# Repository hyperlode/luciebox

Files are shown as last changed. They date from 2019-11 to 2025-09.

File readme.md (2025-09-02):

# About
A busy box is the official word for a sensory exploratory platform for babies. 
This project was made as a birth day gift for Lucie Ameije 2019-04
Turns out, it's as interesting to adults as it is to babies. 
95% ignores abandos the box after five minutes. 5% gets hooked for days. 

Made by Uncle Sensory Overlode.
www.ameije.com

PCB and code:
https://github.com/hyperlode/luciebox

Manual:
https://docs.google.com/document/d/10EQDtFDWs3Xm5eaC9KIhdYMh6ftuR9I12zDFt4Ep7Ls/edit?usp=sharing

# Upload
- Open the arduino IDE
- Open the "luciebox" folder in the IDE
- Compile and upload should go smoothly.
- (alternatively Platformio for VS-code can be used)

# Versions
- F301: 2021-03-19: Version uploaded before sending boxes home
- F302: 2021-04-20 For the v3 startburst pcb. 
-F303: 2021-04-21: Small bugfixes, easier debug of selector dial in settings app . 
-F306: 2021-10-15: Improve user experience. Dream mode app better suited for toddlers.

# Manual
- A manual is in the "documentation folder"
- The most up to date manual is a google docs. Online at https://docs.google.com/document/d/1WturQFRmZjFw0ZYRagNDqMO8tlJvhG8SyK8Gmxv2Aj4/edit#

# Motto
- There are no bugs, only features.  Or: every bug is a feature.  (it doesn't matter if things work or not).

# Making off:
- pcbs ordered 20191112   jlc pcb (jlcpcb.com) 10 pieces for about 30cad.
- Invoice No：2818290A20191113144921
- Invoice Date：13/11/2019
- Batch No：W201911131447210

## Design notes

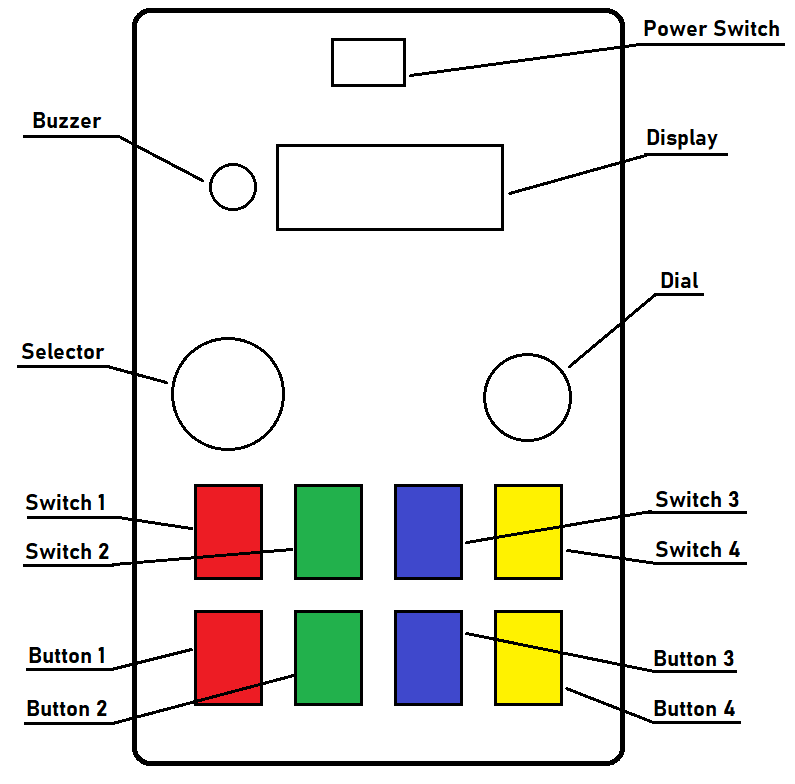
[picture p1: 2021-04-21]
documentation/Drawings_F306/Luciebox_lid_layout_annotated_font_bahnschrift.png

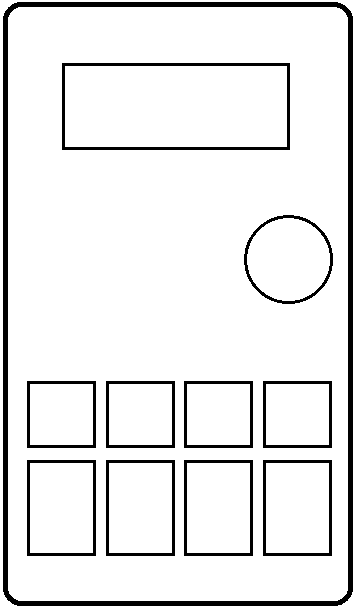
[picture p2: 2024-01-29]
documentation/Drawings_F308/Luciebox_lid_layout.png

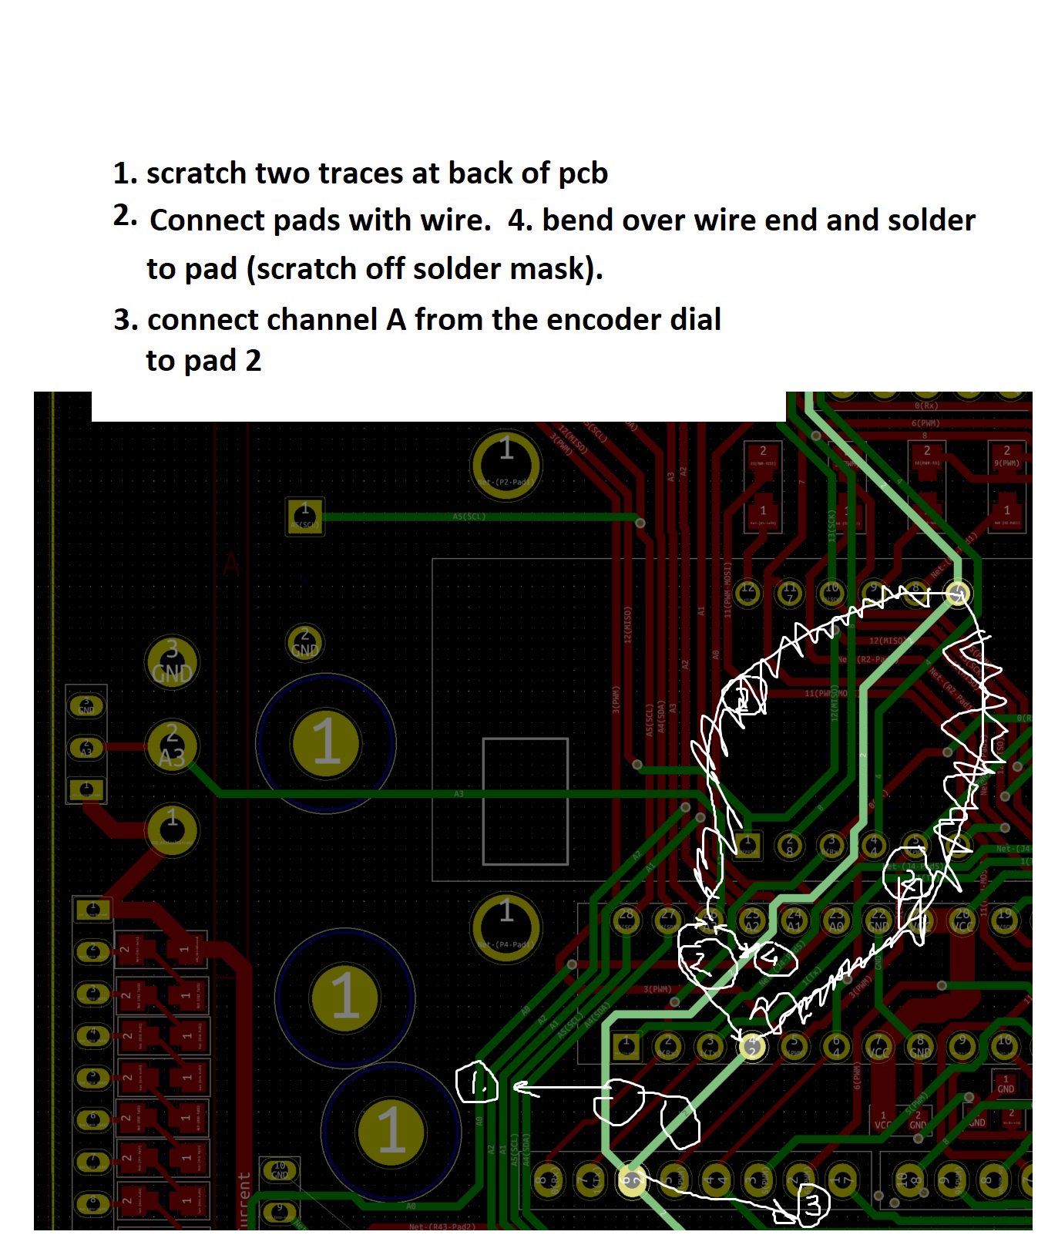
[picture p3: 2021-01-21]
pcb/v2 pcb with corona - change pin 2 to A3 for segment B.jpg

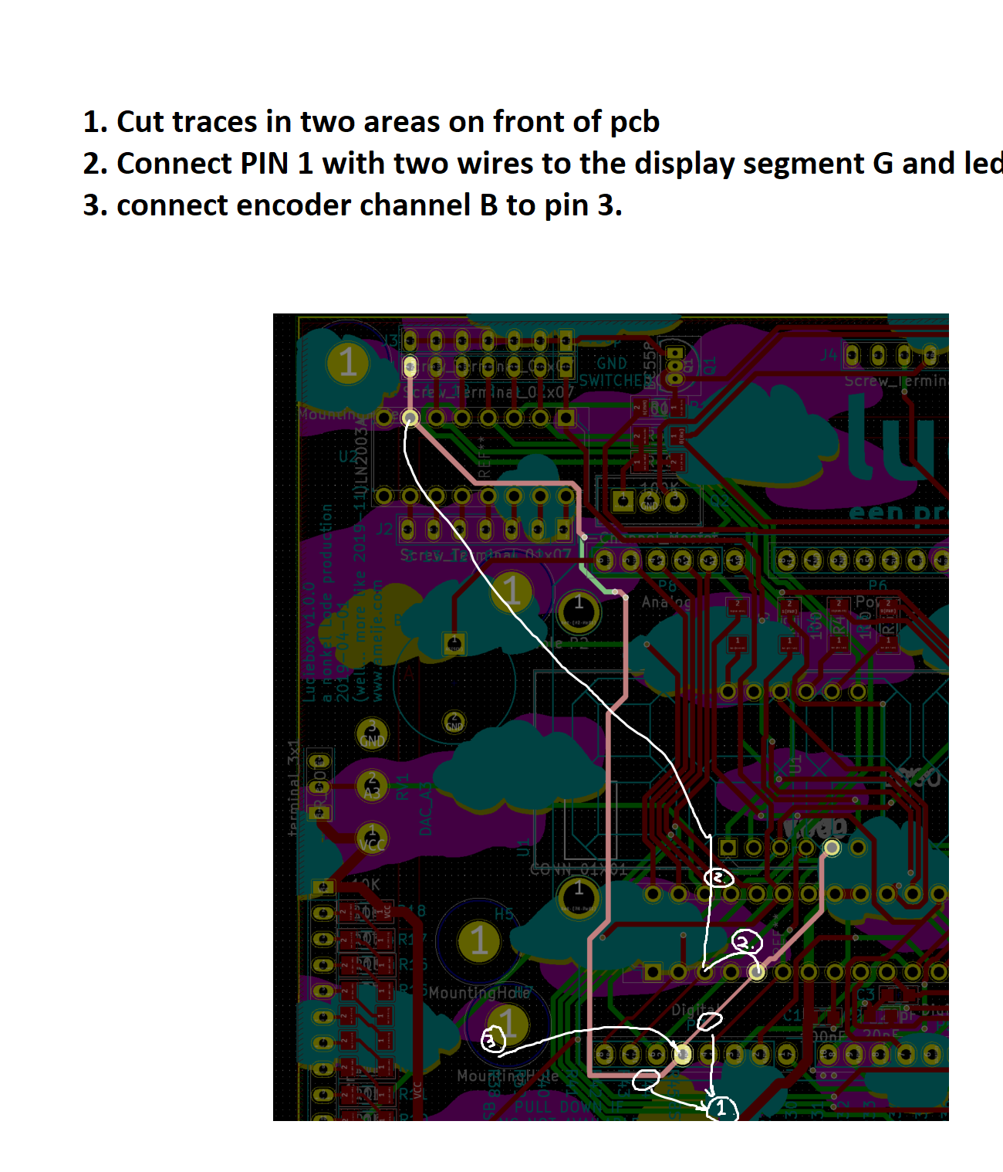
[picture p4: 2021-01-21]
pcb/v1 pcb with clouds - change pin 3 to 1 for segment G.png

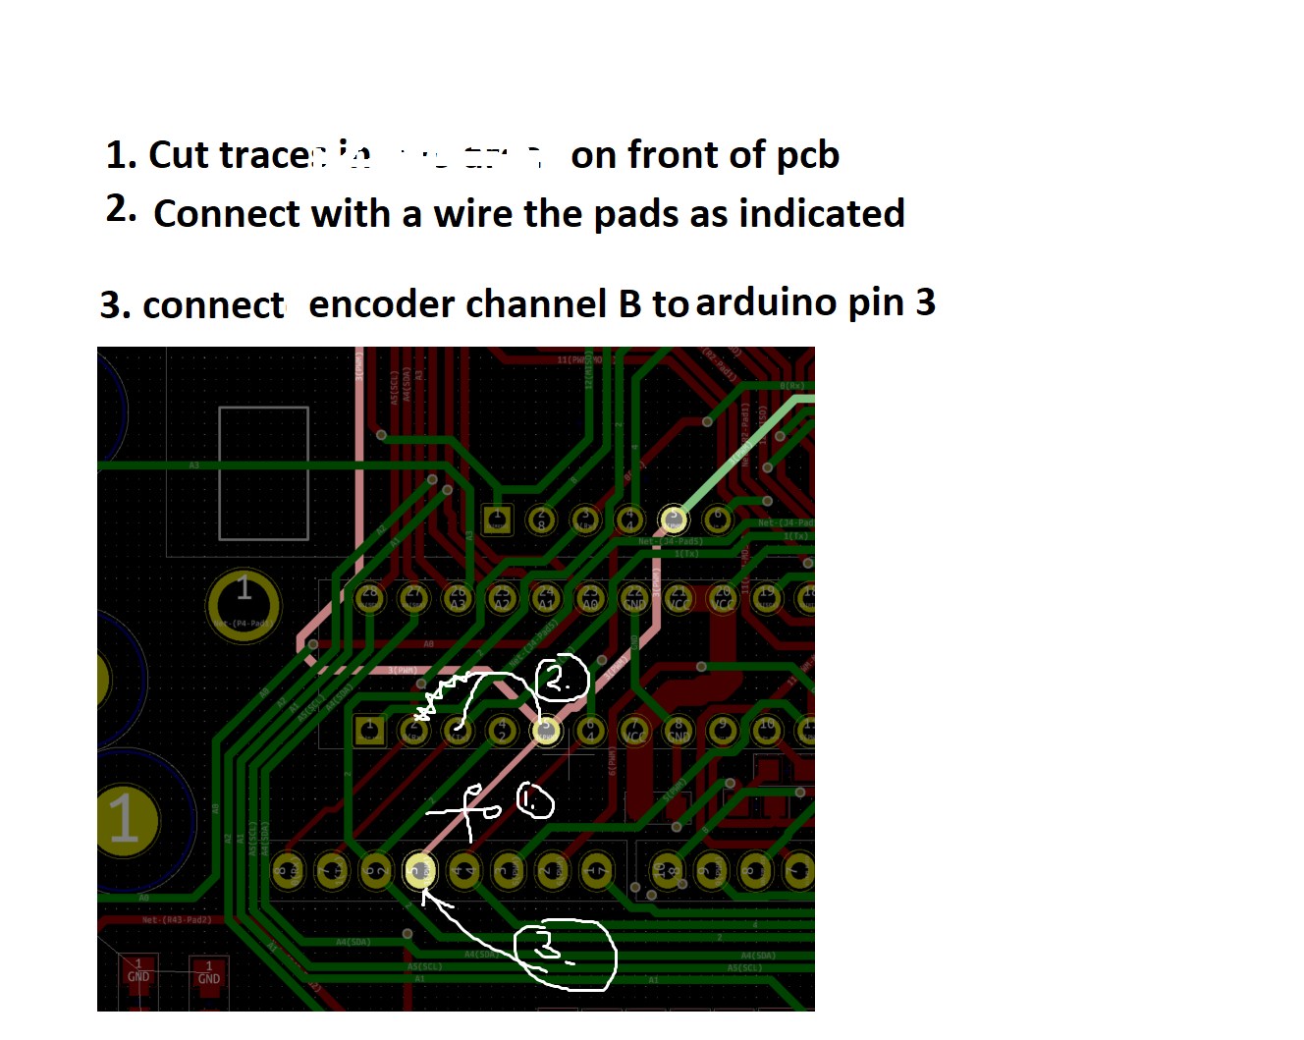
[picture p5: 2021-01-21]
pcb/v2 pcb with corona- change pin 3 to 1 for segment G.png

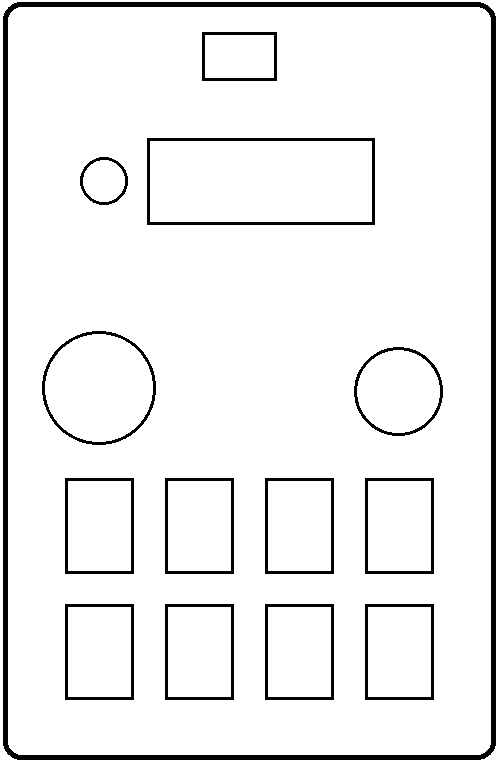
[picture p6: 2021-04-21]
documentation/Drawings_F306/Luciebox_lid_layout.png

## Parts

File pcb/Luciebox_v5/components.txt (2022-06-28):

https://www.aliexpress.com/item/32906026581.html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,scm-url:1007.13339.274681.0,pvid:77129f3c-91ed-44a8-8e5b-19a464453535,tpp_buckets:668%232846%238116%232002&pdp_ext_f=%7B%22sku_id%22%3A%2265853774655%22%2C%22sceneId%22%3A%223339%22%7D&pdp_npi=2%40dis%21CAD%21%2112.02%21%21%21%21%21%40210323a416546603388338875e28e2%2165853774655%21rec

https://www.aliexpress.com/item/32918157519.html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,scm-url:1007.40050.281175.0,pvid:30780251-6273-4900-846c-6cb24b13091a,tpp_buckets:668%232846%238116%232002&pdp_ext_f=%7B%22sku_id%22%3A%2210000001925503913%22%2C%22sceneId%22%3A%2230050%22%7D&pdp_npi=2%40dis%21CAD%21%210.59%21%21%21%21%21%40210323a016546671876902505e33f1%2110000001925503913%21rec

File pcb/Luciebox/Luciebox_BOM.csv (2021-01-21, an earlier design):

Reference | Value | Footprint | Datasheet
P6 | Power | Socket_Arduino_Uno:Socket_Strip_Arduino_1x08
P8 | Analog | Socket_Arduino_Uno:Socket_Strip_Arduino_1x06
P1 | CONN_01X01 | Socket_Arduino_Uno:Arduino_1pin
P2 | CONN_01X01 | Socket_Arduino_Uno:Arduino_1pin
P3 | CONN_01X01 | Socket_Arduino_Uno:Arduino_1pin
P4 | CONN_01X01 | Socket_Arduino_Uno:Arduino_1pin
P7 | Digital | Socket_Arduino_Uno:Socket_Strip_Arduino_1x08
P5 | Digital | Socket_Arduino_Uno:Socket_Strip_Arduino_1x10
U1 | CA56-12SRWA | Luciebox:CA56-12SRWA | http://www.kingbrightusa.com/images/catalog/SPEC/CA56-12SRWA.pdf
R3 | 100 | Luciebox:1206_0805 | ~
R4 | 100 | Luciebox:1206_0805 | ~
R5 | 100 | Luciebox:1206_0805 | ~
U2 | ULN2003A | Luciebox:DIP-16_W7.62mm | http://www.ti.com/lit/ds/symlink/uln2003a.pdf
R2 | 100 | Luciebox:1206_0805 | ~
R1 | 100 | Luciebox:1206_0805 | ~
Q1 | BC558 | Luciebox:TO-92-3 | http://www.fairchildsemi.com/ds/BC/BC557.pdf
J2 | Screw_Terminal_01x07 | Luciebox:Terminal_7x1_100mil | ~
J3 | Screw_Terminal_01x07 | Luciebox:Terminal_7x1_100mil | ~
U3 | ATmega328-PU | Luciebox:DIP-28_W7.62mm | http://ww1.microchip.com/downloads/en/DeviceDoc/ATmega328_P%20AVR%20MCU%20with%20picoPower%20Technology%20Data%20Sheet%2040001984A.pdf
R7 | 10K | Luciebox:1206_0805 | ~
R8 | 10K | Luciebox:1206_0805 | ~
R9 | 10K | Luciebox:1206_0805 | ~
R10 | 10K | Luciebox:1206_0805 | ~
R11 | 10K | Luciebox:1206_0805 | ~
R12 | 10K | Luciebox:1206_0805 | ~
R13 | 10K | Luciebox:1206_0805 | ~
R14 | 10K | Luciebox:1206_0805 | ~
R15 | 10K | Luciebox:1206_0805 | ~
R16 | 10K | Luciebox:1206_0805 | ~
R17 | 10K | Luciebox:1206_0805 | ~
R18 | 10K | Luciebox:1206_0805 | ~
T1 | terminal_13x1 | Luciebox:Terminal_13x1_100mil
RV1 | R_POT | Luciebox:BIG_POTENTIO | ~
BZ1 | Buzzer | Luciebox:buzzer | ~
Y1 | 16MHz | Luciebox:CRYSTAL | ~
R6 | 1M | Luciebox:1206_0805 | ~
C2 | 20pF | Luciebox:0805 | ~
C3 | 20pF | Luciebox:0805 | ~
C1 | 100nF | Luciebox:0805 | ~
R19 | 100 | Luciebox:1206_0805 | ~
J4 | Screw_Terminal_01x07 | Luciebox:Terminal_7x1_100mil | ~
Q2 | N-Channel_Mosfet | Luciebox:TO-220-3 | https://www.onsemi.com/pub/Collateral/FQP30N06L-D.pdf
R47 | 100K | Luciebox:1206_0805 | ~
R48 | 100K | Luciebox:1206_0805 | ~
J5 | Screw_Terminal_01x07 | Luciebox:Terminal_7x1_100mil | ~
T11 | terminal_3x1 | Luciebox:Terminal_3x1_100mil
H4 | MountingHole | MountingHole:MountingHole_4mm | ~
H1 | MountingHole | MountingHole:MountingHole_4mm | ~
H2 | MountingHole | MountingHole:MountingHole_4mm | ~
H3 | MountingHole | MountingHole:MountingHole_4mm | ~
H8 | MountingHole | MountingHole:MountingHole_4mm | ~
H7 | MountingHole | MountingHole:MountingHole_4mm | ~
H6 | MountingHole | MountingHole:MountingHole_4mm | ~
H5 | MountingHole | MountingHole:MountingHole_4mm | ~
U4 | 8X8PADS | Luciebox:64_PADS_100mil
R49 | 10K | Luciebox:1206_0805 | ~
J7 | USB_B_Mini | Luciebox:usb_mini_Molex-0548190519 | ~
D1 | D_Schottky | Luciebox:smd_throughhole_2_pins | ~
T8 | terminal_3x1 | Luciebox:Terminal_3x1_100mil
T10 | terminal_8x1 | Luciebox:Terminal_8x1_100mil
T9 | terminal_8x1 | Luciebox:Terminal_8x1_100mil
T13 | terminal_8x1 | Luciebox:Terminal_8x1_100mil
R27 | R_Small | Luciebox:1206_0805 | ~
R26 | R_Small | Luciebox:1206_0805 | ~
R25 | R_Small | Luciebox:1206_0805 | ~
R24 | R_Small | Luciebox:1206_0805 | ~
R23 | R_Small | Luciebox:1206_0805 | ~
R22 | R_Small | Luciebox:1206_0805 | ~
R21 | R_Small | Luciebox:1206_0805 | ~
R20 | R_Small | Luciebox:1206_0805 | ~
R28 | DAC_R-2R | Luciebox:SIP-10 | https://www.bourns.com/docs/Product-Datasheets/R2R.pdf
T4 | terminal_8x1 | Luciebox:Terminal_8x1_100mil
T3 | terminal_8x1 | Luciebox:Terminal_8x1_100mil
T2 | terminal_8x1 | Luciebox:Terminal_8x1_100mil
R36 | R_Small | Luciebox:1206_0805 | ~
R35 | R_Small | Luciebox:1206_0805 | ~
R34 | R_Small | Luciebox:1206_0805 | ~
R33 | R_Small | Luciebox:1206_0805 | ~
R32 | R_Small | Luciebox:1206_0805 | ~
R31 | R_Small | Luciebox:1206_0805 | ~
R30 | R_Small | Luciebox:1206_0805 | ~
R29 | R_Small | Luciebox:1206_0805 | ~
R37 | DAC_R-2R | Luciebox:SIP-10 | https://www.bourns.com/docs/Product-Datasheets/R2R.pdf
T7 | terminal_8x1 | Luciebox:Terminal_8x1_100mil
T6 | terminal_8x1 | Luciebox:Terminal_8x1_100mil
T5 | terminal_8x1 | Luciebox:Terminal_8x1_100mil
R44 | R_Small | Luciebox:1206_0805 | ~
R43 | R_Small | Luciebox:1206_0805 | ~
R46 | DAC_R-2R | Luciebox:SIP-10 | https://www.bourns.com/docs/Product-Datasheets/R2R.pdf
SW9 | Switch_tilt | Luciebox:Terminal_2x1_100mil
SW10 | Switch_tilt | Luciebox:Terminal_2x1_100mil
SW11 | Switch_tilt | Luciebox:Terminal_2x1_100mil
SW12 | Switch_tilt | Luciebox:Terminal_2x1_100mil
R45 | R_Small | Luciebox:1206_0805 | ~
R42 | R_Small | Luciebox:1206_0805 | ~

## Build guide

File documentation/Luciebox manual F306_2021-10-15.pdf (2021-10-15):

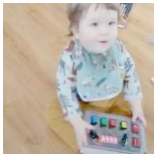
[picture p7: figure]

# Luciebox

# Owners manual

The Luciebox pretbak, made by Uncle Lode Ameije for Lucie. Project started 2019-04-02. Manual v20211005

# Introduction

I saw a toddler being mesmerized with the sounds and lights after pressing random buttons on one of my multiTimers. Right away I knew what I should give to my brother’s first soon-to-be-born child. What started as a weekend project now has a 40 something pages manual, and Lucie is two years old. The Luciebox is not going to appeal to many people, but I know, if I would have had this box as a kid, I would have worn it out together with my brother. We’d know every feature and bug better than the original creator. Sure, I can claim that there is educational value in this over the top retro device. But, let’s not forget the original mission of this project… It’s time to mesmerize! I realize now there is no such thing as finished projects, only abandoned projects. I’m welcoming all suggestions and contributions, write them down as comments in the appropriate section in this document. Looking at you Lucie! Regards from your high-expectations-uncle Lode.

# How to use this box

Don’t be put off by the lack of information on the box. It’s ok to be overwhelmed. Just know that there are 23 applications. An app is selected with the selector dial in combination with the Red Switch. Applications have different degrees of difficulty. Choose an application from the list and try to make it work. I suggest Guitar Hero for a fun introduction. Read the instructions for the specific app and have a go at it. At the start leave all switches in the OFF position to enable the default mode. Experiment away, you can’t do anything wrong.

Ta

# ble

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
rvie

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
rvie

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
al m

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
ol | 1
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
tilt

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
ole, r

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
al m

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
4 Idea for the Pascal sake drinking game | 24

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
rial | 2
7 Independent reaction game mode | 27

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
Timin

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
al c

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
ultiTim

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
Timin

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
al m

o

d

e

3

5
Valu

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
al r

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
al r

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
m la

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
7 Inactivity timer | 37 Randomness fun | 37 Test and Settings | 38 Settings Menu items | 38

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
Valu

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
Valu

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
O in

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
# Getting started

## Overview

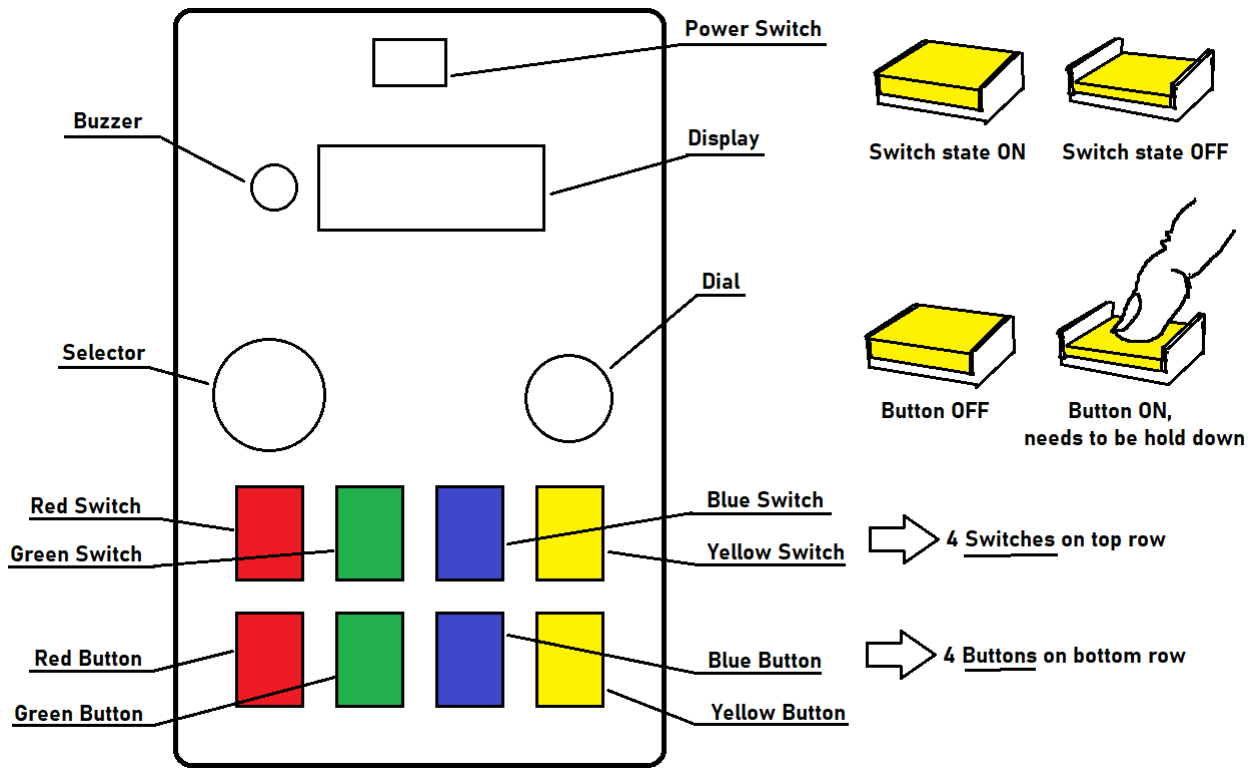
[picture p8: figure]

Name in this document | Official name | Description
Power Switch | On / Off switch | Switches on the box with the batteries. If powered by USB or the programming connecter, this will have no effect
Selector | Selector dial | Limitless 12 positions dial, on the left of the lid
Dial | Encoder dial | Limitless smooth dial on the right of the lid
Red Switch | Latching Button 0 | Red toggle button which can be set in the ON or OFF position.
Green Switch | Latching Button 1 | Green toggle button which can be set in the ON or OFF position.
Blue Switch | Latching Button 2 | Blue toggle button which can be set in the ON or OFF position.
Yellow Switch | Latching Button 3 | Yellow toggle button which can be set in the ON or OFF position.

Red Button | Momentary Button 0 | Red push button. When pushed and held, it’s ON, when released, it’s OFF.
Green Button | Momentary Button 1 | Green push button. When pushed and held, it’s ON, when released, it’s OFF.
Blue Button | Momentary Button 2 | Blue push button. When pushed and held, it’s ON, when released, it’s OFF.
Yellow Button | Momentary Button 3 | Yellow push button. When pushed and held, it’s ON, when released, it’s OFF.
Buzzer | Buzzer | A tiny speaker is inside the box. The volume can be set by putting some tape over the hole. The sound can be muted in the settings app
Display | 4 digit 7 segment LED display | Every digit has actually eight segments if we include the little dot, called the decimal point, on its right

# Applications

## Overview

If one of the buttons is held while rotating the selector knob, the splash screen stays visible.
Application | Selector Position | Red Switch Position | Splash screen | Comments | Diffi culty [1-5]
Test and Settings | 1 | 0 | wrench | Test all the buttons. Check and modify the Luciebox configuration. | 1
| 1 | 1
Stopwatch | 2 | 0 | stopwatch | All the goodies from a typical 80’s stopwatch. Has two independent timers. | 2
MultiTimer | | 1 | | A game clock for up to 4 players. Can also be used as a chess clock or as a kitchen timer. | 2
School | 3 | 0 | koala / Adhemar | Learn how to count, learn the alphabet | 3
Pomodoro Timer | 3 | 1 | | The Pomodoro technique helps procrastinators to get things done | 3

Random world | 4 | 0 | dice | Roll the dice, flip a coin, play bingo, draw random playing cards or let psychic Lucie answer all your questions. | 2
Score tracker | 4 | 1 | | Keeps a tally of the score of up to four players. | 2
Simon Says Game | 5 | 0 | face | Try to repeat light patterns of ever increasing length. Has multiplayer modes. | 3
Quizmaster, reaction game | 5 | 1 | | Press your button as fast as possible when the lights go on. Up to four players. | 3
Whack a mole | 6 | 0 | gun | Hit the button as quick as possible if the light goes on. If you play with sounds, it’s called “whack a bird” | 2
Guitar hero | 6 | 1 | | Bars are falling down quickly, hit the buttons at the right moment to catch them! | 3
Sketch pad | 7 | 0 | pencil | Scroll through and edit 95 pictures | 3
Memory game | 7 | 1 | | Reproduce what the display showed. | 3
Radio | 8 | 0 | movie reel | Play the main songs, your own compositions and the stored sequencer loops | 1
Movie player | 8 | 1 | | A full featured media player. Combine the built in or stored animations with one of the songs. It could as well have been named “my first meme”. | 3
Metronome | 9 | 0 | drumkit | Set the number of beats per minute. The flash mode produces noiseless ticks. | 2
Sequencer | 9 | 1 | | 4 bars of 8 notes of fun. Always starts up with an auto generated sequence. | 4
Music notes | 10 | 0 | note | Experiment with tones, lengths, scales and arpeggios. Features an auto mode | 1

Song Composer | 10 | 1 | | Create and save up to four songs. | 4
Noise Generator | 11 | 0 | radioactive | Measure your local radio activity. Or generate all kinds of noise. | 1
Hack Time | 11 | 1 | | Display and edit the Luciebox memory. Experiment as you like. | 5
Dream Time | 12 | 0 | manta ray | Baby action with simple button actions, patterns and sounds. | 1
| 12 | 1 | | | 1

# Toddler

## Radio

Simple music player. Each momentary button will play a song. The standard songs are featured, and your own programmed songs!

Input | Functionality | Comments
Green Switch | Song bank selector 1 | A combination of the bank selector assigns different songs to the momentary buttons
Blue Switch | Song bank selector 2 | A combination of the bank selector assigns different songs to the momentary buttons
Yellow Switch | Playback speed / Transpose | Dial will change the settings while a song is playing

### Songs

Green Switch | Blue Switch | Functionality
0 | 0 | Permanent memory songs bank 1 assigned to momentary buttons
1 | 0 | Permanent memory songs bank 2 assigned to momentary buttons
0 | 1 | Home made songs from the song composer assigned to momentary buttons
1 | 1 | Sequencer songs 1 to 4 assigned to momentary buttons

## Music notes

Plays single notes. Manually or automatically. Test different scales and modes.
Input | Functionality [OFF / ON] | Comments
Green Switch | Piano mode / Advanced mode
Blue Switch | Single note / Queue | In queue mode, all pressed notes will be added to the buffer. In single mode, the buffer will be erased before adding a note.
Yellow Switch | Manual mode / Auto arpeggio | Auto arpeggio will automatically play the next note after a timed interval
Dial | | in auto arpeggio: set interval, in manual mode: go up or down the scale

### Piano mode

Input | Functionality | Comments
Red Button | Mute | Will not make sound while changing notes. This allows you to jump notes silently when playing a song.
Green Button | Play active note | Play the last played note
Blue Button | Previous note | Previous note on the active scale
Yellow Button | Next note | Next note on the active scale

### Advanced mode

Input | Functionality | Comments
Red Button | Duration | Cycle between full, half, quarter, eight notes
Green Button | Progression | Cycle between up/down patterns: ● MANU: Manual (default, set direction yourself), ● UP: Going up the scale, ● DO: Going down the scale, ● UPDO: Saw pattern, going up and down, changing at a random interval ● RND: Random picking of a note on the scale ● CRAY: Crazy mode going randomly up and down at erratic intervals.
Blue Button | Scale | Cycle between different scales: ● AJOR: Major ● INOR: Minor ● PENT: Pentatonic ● BLUE: Blues Major ● CHRO: Chromatic

Yellow Button | Key | Cycle between all 12 tones in an octave to set the key of the selected scale. Press once to display the current key. Next button presses will change it.

## Metronome

A classic metronome with fun visual effect.
12 steps per cycle, up to three tickers.
Input | Functionality [OFF / ON] | Comments
Green Switch | Make ticker 2 step backwards
Blue Switch | Set speed in beats per minute (bpm) | One ‘beat’ is a full circle of 12 steps.
Yellow Switch | Manual mode / Ticking mode
Red Button | Reset the positions of all tickers | Set to the position of ticker 1
Green Button | Increase ticker 2 offset by one
Blue Button | Increase ticker 3 offset by one

### Metronome Manual mode

Yellow Button | Functionality | Comments
Single press | manual step
Not pressed | rotate dial to step
Hold and dial | Change tick sounds | note length: shorter (rotate clockwise) or longer (rotate counter clockwise) beeps. Shorter beeps lose their pitch, and are more like a metronome ‘puck’ sound.

### Metronome Ticking mode

Button | Functionality | Comments
Yellow Button | Flash screen toggle | Will toggle screen flashing at every beep. This improves metronome feedback in loud environments.
dial | | change bpm

## Dream Time

Mesmerize and go on a trippy hypno voyage where sound and graphics are ruled by randomness and chaos.

Input | Functionality [OFF / ON] | Comments
Green Switch | Play song | Toggle between Alphabet song and Happy Dryer song
Blue Switch | Unmute / Mute | Every segment has a sound assigned.It’s played when it appears or disappears. Sounds are a 32 values range off the total of 256 available sounds. The offset is settable.
Yellow Switch | Auto / Manual | Dial will change step in manual and set interval speed in auto mode
Red Button | Uncle Lode Indoctrination
Green Button | PRRRRR noise
Blue Button | Previous step
Yellow Button | Next step

# Child

## Easy timer

Displays the time since the box was switched on. There are no controls in this app.

## School

Learn how to count and learn the alphabet.
Learn how to be a bouncer by using the counting function to keep track of the number of guests in your bar.
Input | Functionality [OFF / ON] | Comments
Green Switch | Number mode / alphabet mode | display numbers or letters
Blue Switch | Numbers as Decimal / Hexadecimal | Only effective in number mode
Yellow Switch | Manual / Auto count | Auto mode ● Song is played when in alphabet mode ● Dial changes the speed Manual mode ● Dial changes value
Red Button | in auto mode: toggle count up / down
Green Button | set value zero

Blue Button | value down
Yellow Button | value up

## Score tracker

Keeps up to four different tallies. Can also be used for general counting. Cribbage, snooker, darts,...

Input | Functionality [OFF / ON] | Comments
Green Switch | Count up / Count down
Blue Switch | Apply score change to single tally / to all tallys
Yellow Switch | Modify mode / View mode | In view mode, every tally can be checked without modifying it
Red Button | Tally 1
Green Button | Tally 2
Blue Button | Tally 3
Yellow Button | Tally 4
dial | Hold momentary + dial → set delta | Will show the delta on the screen as long as the momentary button is not released.

## Movement detector (tilt fun)

Deprecated app. Will be made available again on popular request and when mercury switches are deemed environmentally friendly.
Move the box around to count.
Input | Functionality [OFF / ON] | Comments
Green Switch | go through all four positions for a full cycle / skip lateral movements for a full cycle. | don’t take lateral movement into account

Blue Switch

Yellow Switch

Dial

Move the box around, inside are motion detectors. When moved through a cycle correctly, the counter will increase.
Put the box on a swing, see how many times you can swing in a minute!

## Sketch pad

All drawings are stored in eeprom. Scroll through and edit the drawings.

### Modes

Input | Functionality [OFF / ON] | Remark
Green Switch | ON: Save menu | Save a drawing to the eeprom memory
Blue Switch | Display Image / Display Index | “Display index” displays the eeprom drawing address
Yellow Switch | View / Draw | In draw mode, drawings can be edited

### Display mode

Input | Functionality | Screen

Red Button

Green Button | Global display setting | cycle through: ● normal (default) ● negative ● all on ● all off ● STOP screen
Blue Button | Previous drawing
Yellow Button | Next drawing
Dial | Scroll through drawings

### Draw mode

Input | Functionality | Screen
Red Button | Toggle active segment
Green Button | Global display setting | cycle through: ● normal (default) ● negative ● all on ● all off ● STOP screen
Blue Button | Move cursor inside digit
Yellow Button | Move cursor to next digit
Dial | Move cursor

### Save To eeprom Mode

When scrolling through images, will NOT update the screen. The buffer stays the same. This way, you can scroll through the desired image (used index to see number) and save .
Input | Functionality | Comments
Red Button | Save screen | Will save the drawing to the active EEPROM address (visible with Green Switch)
Green Button | HOLD to have “shift function for momenary_2 and Yellow Button
Blue Button | previous drawing OR with SHIFT FUNCTION: delete drawing slot (and move all indexes, ) | Hold down Green Button for it to work
Yellow Button | next drawing OR with SHIFT FUNCTION: insert drawing slot and move all indexes from other drawings. Will overwrite the last drawing from eeprom. | Hold down Green Button for it to work
Dial | move through drawings.

### How to create animations

Step | Comment | Example
1 | Create and save a drawing with the STOP marker. (Draw mode → global display settings → stop screen) | drawing 27: STOP
2 | Go to the next drawing. Now make as many drawings as you want in the next slots. These are the frames of the movie. | drawing 28: UNCL drawing 29: LODE drawing 30: IS drawing 31: OLD COOL
3 | To indicate that the drawings are an animation, create and save another STOP drawing. | drawing 32: STOP
4 | Animations can be watched with the “Movie Player” app.

## Memory Game

Look at the picture, memorize it, press the start button. Try to reproduce it!
There are four modes available: Random segments, Numbers, Letters, Digital clock. This game is really fun to play as a collaborative challenge with a team!
Input | Functionality [OFF / ON] | Remark
Green Switch | Play mode option 1

Blue Switch | Play mode option 2
Yellow Switch | Menu / Play | In menu the generated pattern is already shown

### Menu

Play mode defines which image will be generated on the display
Play Mode | Green Switch | Blue Switch | Generate and display pattern
Random | OFF | OFF | Random segments (difficult mode)
Numbers | ON | OFF | Random digits (0000 to 9999)
Letters | OFF | ON | Random letters (AAAA to ZZZZ)
Clock | ON | ON | Random clock value (00.00 to 23.59)

### Play

Step | Comment
1 | Make sure Yellow Switch is set to OFF
2 | Memorize what’s displayed on the screen
3 | Switch Yellow Switch to ON
4 | Try to reproduce the screen as it was shown at the start. See the draw app on how to draw on the display
5 | When done with drawing, switch Yellow Switch to OFF
6 | If done correctly, a victory song will play. If you didn’t manage to reproduce the original drawing, the differences will be displayed.

## Random world

Show various random generated events.
Button | Functionality [OFF / ON] | Remark
Green Switch | Shift | Each of the momentary buttons gets another function if ON.
Blue Switch | animate? | “Rolling animation” if ON.

Yellow Switch | Manual / Auto draw | Auto draw: ● Set the draw interval time in seconds with the dial. ● Press a momentary button to start the auto draw Manual draw: ● Press a momentary button for each draw
Dial | | Manual draw mode: ● rotate to draw

### Random modes

Input | Shift? | Function
Red Button | No | Single Dice | Display shows eyes like a real dice
Red Button | Yes | Roll 4 dice at once | Each dice has its own digit. display: VVVV V = [1-6]
Green Button | No | Random Letter Shows random letter and its position in the alphabet | display: VV L VV = position of letter in alphabet L = representation of letter.
Green Button | Yes | Draw the next card from a shuffled deck. The card is discarded at next draw. When all cards from the deck are gone, a new deck is shuffled. Sound will sound when a new deck is taken and shuffled. | display: V S V = value S = Suit Values: 1 = ACE, 11 = JACK, 12 = QUEEN 13 = KING Suits: S = Spades C = Clubs H = Hearts D = Diamonds
Blue Button | No | Random number in manual mode : hold button (minimum 2 seconds, and keep holding) to set upper limit with Dial.
Blue Button | Yes | Random sequence (=tombola) Custom Value [0-xxx] Set maximum value xxx by holding the button and turning the Dial. xxx will be saved in eeprom.

| | in manual mode : hold button (minimum 2 seconds, and keep holding) to set upper limit with Dial. Will draw all numbers from the set (max 100 numbers) before starting a new set. Sound will sound when new sequence produced.
Yellow Button | No | Coin toss | display: HEAD (=head) or TAIL (=tails)
Yellow Button | Yes | Psychic experience. Ask a question, your grand-grand aunty Lucy will respond with yes or no. | display: YES or NO

## Stopwatch

Two independent classic chronometers.
At startup of the app, the second chronometer contains the total ON time since the Lucie box was switched on.
Input | Functionality [OFF / ON] | Remark
Green Switch | None | The rarest of beasts! A button without a function! Contact Uncle Lode if you have an idea.
Blue Switch | Display maximum precision or seconds precision
Yellow Switch | Stopwatch 1 / Stopwatch 2 | The two stopwatch controls are not influencing each other
Red Button | Hold to show split time
Green Button | Hold to save split time and show
Blue Button | Reset
Yellow Button | Toggle Start Pause

## Noise Generator

A geiger counter detects radioactive decay. Every time radiation is sensed, a beep is emitted. The more beeps you hear, the more contaminated the environment is!
Note: There is no real radioactivity meter installed in the Luciebox. It’s all fake fake fake. But your mother doesn’t need to know!
Input | Functionality [OFF / ON] | Remark
Green Switch | Geiger mode / Noise mode

Blue Switch | Animated / Counter
Dial | sensitivity

### Geiger Counter Mode

Input | Function | Comment
Red Button | None | Contact uncle Lode if you have a functionality idea
Green Button | None | Contact uncle Lode if you have a functionality idea
Blue Button | None | Contact uncle Lode if you have a functionality idea
Yellow Button | Temporary sharp increase of tick probability | When pressed, it looks like there is a lot more radiation. Practical joke idea: Hold the box close to a person and press the button…. it then appears like the person is contaminated. Hilarity ensues! Warning, do not use this prank near microwave ovens. People are already paranoid enough about them as it is.
Dial | Set tick probability

### Noise Mode

Offers the possibility to tune Geiger as a random note generator.

Input | Functionality | Comment
Yellow Switch | Prolonged beep | Every beep will sound until another beep takes over if ON.
Red Button | Set Lower frequency | Hold while rotating the dial. This is the lowest frequency that will be randomly chosen.
Green Button | Upper frequency | Hold while rotating the dial. This is the highest frequency that will be randomly chosen.
Blue Button | Tone length | Hold while rotating the dial. Tone length in milliseconds.
Yellow Button | Trigger manually | Hold while rotating the dial to trigger manually

## Whack a mole, reaction game

### Menu

Input | Functionality [OFF / ON] | Remark

Green Switch | Whack a mole / whack a bird | Can only be changed in Menu
Blue Switch | Normal mode / Endurance mode | Can only be changed in Menu
Yellow Switch | Menu / Play
Dial | Set level | Can only be changed in Menu

### Play Whack a mole

Every momentary button represents a mole that’s popping up. Your task is to hit it when it stick its head out! When the light goes on, you have to press the button as quick as possible to gain high scores.

Step | Function
1 | In the menu, the level (L x) and its high score are shown intermittently. Choose a level with the dial.
2 | Switch Yellow Switch to ON to start playing
3 | If a momentary button lights up (or a decimal point on the display), the corresponding button needs to be pressed.
4 | When the button is pressed, the light goes out. If it stays on, the button needs to be pressed again as that persistent mole needs more whacking!
5 | If a wrong button is pressed, or if time ran out, the game ends
6 | At game end, your mole whacking score will be displayed. If you have a new high score, a victory song will be played.
7 | After some seconds, a new game will start automatically. Go to step 3.
8 | Switch Yellow Switch to OFF to end the game and enter the menu at any time

### Play Whack a bird

Step | Function
1 | When the application is selected, four random notes from the chromatic scale are chosen. These notes stay the same for as long as the Whack-a-mole application is active.
2 | In the menu, the level (L x) and its high score are shown intermittently. Choose a level with the dial.
3 | Switch Yellow Switch to ON to start playing
4 | The four notes will be heard as a sequence. For each note, a button is assigned. It will light up when the sequence is playing.
5 | Now a note is played. Press the corresponding momentary button to whack that bird. (In

| level one, rookie mode, the corresponding button is lit up as a visual clue.)
6 | If a wrong button is pressed, or if time ran out, the game ends
7 | At game end, your bird whacking score will be displayed. If you have a new high score, a victory song will be played.
8 | After some seconds, a new game will start automatically. Go to step 4.
9 | Switch Yellow Switch to OFF to end the game and enter the menu at any time

### Normal mode

The time assigned is the maximum time between two whacks.
Level | Maximum reaction time[s] | Comments
1 | 30 | This seems long. But, run around the table or house for every mole you whack. How long can you last? What else can you do?
2 | 5
3 | 2.5
4 | 1
5 | ~0.5
6 | ~0.3 | Obviously uncle Lode maxed out on this one!

### Endurance mode

The time assigned is the total whacking time. Try to whack as many animals in that given time frame. Beware, one mistake and you have to start all over again…
level | Total whack time
1 | 2 minutes
2 | 1 minute
3 | 30 seconds
4 | 20 seconds
5 | 10 seconds
6 | 5 seconds

# Adolescent

## Simon Says Game

‘Simon says’ is a game where people try to repeat progressively longer sequences of button presses.

### Main menu

Button | Functionality [OFF / ON]
Green Switch | Simon / without Simon | Normally Simon decides the sequence. In games without Simon, every level, a player adds a step to the sequence.
Blue Switch | All players repeat/ one player repeats | In multiplayer: all players have to enter the sequencer (computer decides player sequence) or only one random chosen player has to repeat it.
Yellow Switch | Main menu / Play | When playing, set to OFF to enable menu and reset game
Dial | set number of players

### Game selection

Green Switch | Blue Switch | Functionality implemented | desired functionality (future)
0 | 0 | Play with Simon. Every turn, the computer makes the sequence one step longer. In multiplayer, all players in random order (the number is displayed on the screen) have to repeat the sequence
0 | 1 | Play with Simon. Every turn, the computer makes the sequence one step longer. In multiplayer, only one player is chosen to repeat the sequence. The chosen player id is displayed.
1 | 0 | Play without Simon. Players build the sequence. The first player in a new rounds sets the new last step in the sequence. Every player repeats the sequence.
1 | 1 | Play without Simon. Players build the sequence. Only one random player has to repeat the sequence. He decides what the next last step is. | Pascal sake drinking game: Player presses a sequence (length decided by computer?) computer chooses another player who has to repeat it.

TODO: Mode Pascal Sake Drinking Game
Use random switch AND custom build up options at the same time. For every round, a random player has to add a button press to the sequence.
→ a lot more fun when not
everybody has to do the new sequence.

### Play with Simon

Display | Function | Comments
Sxx | De computer player Simon shows a light sequence. | x = length of lights sequence [1-99]
nPxx | Player n has to repeat the light sequence Simon showed. Every button stands for a light. | Lights from left to right correspond with momentary buttons from left to right. n = player id [1 to 9]
nPxx/ END (blink) | All players are out. Last surviving player is n, with score: xx | Display blinks, during a repetition of the sequence one more time. After which a new game starts.

### Play without Simon

Display | Function | Comments
nPxx | Player n has to repeat the light sequence that’s already set. Every button stands for a light. At the end of the sequence, the player adds one more step by pressing one of the buttons of his choice. | Lights from left to right correspond with momentary buttons from left to right. n = player id [1 to 9]
nPxx/ END (blink) | All players are out. Last surviving player is n, with score: xx | Display blinks, during a repetition of the sequence one more time. After which a new game starts.

### Idea for the Pascal sake drinking game

Display | Function | Comments

nPxx | Player n inputs a certain sequence with the momentary buttons. The length of the sequence is defined by x | x = length of sequence [1-99] Use momentary buttons to input a sequence. n = player id [1 to 9]
nPpP | Player n has to repeat the light sequence Player p showed. This could be the same player (p could = n) | Use momentary buttons to input a sequence. n = player id [1 to 9]
pP / OUT (blink) | If player p makes a mistake, he’s out. Not sure if we continue then with a new sequence or if the next player has to input the correct sequence (this would ensure everybody keeps paying attention!) | Display blinks for 2 seconds, before continuing
nP / END (blink) | All players are out. Last surviving player is n | Display blinks for two seconds before restarting a new game

## Guitar Hero

Input | Functionality [OFF / ON] | Remark
Green Switch | Guitar hero / Hex hero
Blue Switch | Normal / Extra mode | Extra mode: Guitar hero: Adds random paused Hex Hero: Input the complement of what you see for all digits with a dot. e.a. 6. → 1001
Yellow Switch | Menu / Play
Dial | In Menu: Choose level | Higher level number = faster

### Play Guitar Hero

Step | Function
1 | In the menu, the level (L x) and its high score are shown intermittently. Choose a level with the dial.
2 | Switch Yellow Switch to ON to start playing
3 | Lines fall down from the top of the screen.
4 | Once lines have reached the bottom, you have to delete them by pressing the corresponding momentary button. Only delete lines that are AT the bottom.
5 | The game ends if a button is pressed at the wrong time, or lines are not deleted in time.
6 | At game end, your score will be displayed. If you have a new high score, a victory song

| will be played.
7 | After some seconds, a new game will start automatically. Go to step 4.
8 | Switch Yellow Switch to OFF to end the game and enter the menu at any time

Team tip: Play guitar hero together: Every player holds his finger on one or more buttons.

### Play Hex Hero

By the year 2036, having a reflexive knowledge of hexadecimal patterns will vastly improve your chances on the job market. Hex hero is an industry leading hex patterns trainer.
Step | Function
1 | In the menu, the level (L x) and its high score are shown intermittently. Choose a level with the dial.
2 | Switch Yellow Switch to ON to start playing
3 | Hexadecimal numbers characters scroll into the screen from the left
4 | Press the corresponding nibble (=half byte) pattern with the momentary buttons to delete the most right hex number. Try to keep a clear screen. See the “Hex character to button pattern conversion table” below. In extra mode (Blue Switch ON), digits with a dot will appear. These need to have the inverted nibble pattern inputted. That’s called “the complement”.
5 | The game ends if the hex numbers scroll out of the screen before they are deleted.
6 | At game end, your score will be displayed. If you have a new high score, a victory song will be played.
7 | After some seconds, a new game will start automatically. Go to step 4.
8 | Switch Yellow Switch to OFF to end the game and enter the menu at any time

Hex character to button pattern conversion table
Example: B shows up on the screen. B represents the value of 11 in decimal. In binary, B is 1011. Mimic this pattern with the momentary buttons by simultaneously pressing buttons 0, 2 and 3.
Charact er display ed | Decim al value | Convert ed to binary | Required button pattern to be pressed simultaneously | Extra: Compleme nt
| | | Red Button | Green Button | Blue Button | Yellow Button
1 | 1 | 0001 | | | | x | 1110
2 | 2 | 0010 | | | x | | 1101

3 | 3 | 0011 | | | x | x | 1100
4 | 4 | 0100 | | x | | | 1011
5 | 5 | 0101 | | x | | x | 1010
6 | 6 | 0110 | | x | x | | 1001
7 | 7 | 0111 | | x | x | x | 1000
8 | 8 | 1000 | x | | | | 0111
9 | 9 | 1001 | x | | | x | 0110
A | 10 | 1010 | x | | x | | 0101
B | 11 | 1011 | x | | x | x | 0100
C | 12 | 1100 | x | x | | | 0011
D | 13 | 1101 | x | x | | x | 0010
E | 14 | 1110 | x | x | x | | 0001
F | 15 | 1111 | x | x | x | x | 0000

## Quizmaster

Once the quizmaster has asked a question. Players can then press a button if they know the answer. It’s important to press your button quicker than your opponent. The Luciebox figures out who pressed first.
In independent mode, this app becomes an addictive multiplayer reaction game without a quizmaster asking questions
Input | Functionality [OFF / ON] | Remark
Green Switch | Normal / Long maximum wait time | ● normal: max 3 seconds ● long: max 20 seconds (which is very long!)
Blue Switch | Quizmode / Independent mode | in independent mode, this is a reaction game. At the random intervals, the light goes on. First player pressing gets a point. auto play some rounds.
Yellow Switch | Question asked | Quizmaster “just asked a question button” In independent mode: ON=play game

Dial

### Quizmaster Tutorial

Step | Comments
1 | Every player gets a momentary button assigned.

2 | Quizmaster asks question
3 | Quizmaster sets Yellow Switch to ON
4 | When the momentary buttons light up, the players can press their corresponding button. The first players pressing its button can answer. A player that presses its button before it’s lit up will have its score reset.
5 | Quizmaster can now turn dial to add or subtract a point to the player’s score
6 | Quizmaster sets Yellow Switch to OFF
7 | Go to step 2

### Independent reaction game mode

In independent mode, this becomes a very fun multiplayer reaction game.
Step | Comments
1 | Every player gets a momentary button assigned.
2 | Start the game by setting Yellow Switch to ON
3 | Wait until the button lights go on.
4 | The first player to press its corresponding button (when the light is on) gets a point. All players that press their buttons before it’s lit up will have their score reset.
5 | First player to reach ten points will hear a victory song.
6 | Reset the game with Yellow Switch

## Movie Player

Combine animations with songs to create full featured movies.

Functionality | Switch | Button | Dial
| 0 | 1 | 2 | 3 | 0 | 1 | 2 | 3
Sound Off (=Mute button) | 1 | | 1
Sound On | 1 | | 0
Autoplay movies | 1 | | | 0
Set playback speed | 1 | 0 | | 0 | | | | | Turn
Manual movie mode | 1 | | | 1
Scroll through frames | 1 | 0 | | 1 | | | | | Turn
Play song | 1 | 1 | | | 1 | 0 | 0 | 0

Toggle between continuous repeat of song and only play at start of movie | 1 | 1 | | 0 | 1 | 0 | 0
Previous Song | 1 | 1 | | 0 | 0 | 1 | 0
Next Song | 1 | 1 | | 0 | 0 | 0 | 1
Next Movie | 1 | 0 | | 1 | 0 | 0 | 0
Display Inverted | 1 | 0 | | 0 | 1 | 0 | 0
Previous frame | 1 | 0 | 1 | 0 | 0 | 1 | 0
Next frame | 1 | 0 | 1 | 0 | 0 | 0 | 1
Play movie forwards | 1 | 0 | 0 | 0 | 0 | 1 | 0
Play movie backwards | 1 | 0 | 0 | 0 | 0 | 0 | 1

### Animation selection

Cycle through all the animations with the “next movie” button.
Sequence: built in animations - home made animations
Note: See DRAW app on how to create a home made animation

### Song selection

Cycle through all the songs with the next and previous buttons. Sequence: 8 built in songs - 4 composed songs - 4 sequencer songs

## Pomodoro Performance Meter

The Pomodoro Timer is a well known tool to be able to concentrate for specific task such as studying, filing in taxes, doing homework, cleaning, …
https://en.wikipedia.org/wiki/Pomodoro_Technique

The official Pomodoro timer is a kitchen timer which has to be wind up manually. This very physical act prepares the mind for the task at hand. But, as we are automation aficionado's, an auto mode was added that automatically restarts the cycle after some break time.

### Menu

Input | Functionality [OFF / ON] | Remark
Green Switch | Enable Break time and auto restart
Blue Switch | Enable Visual Timer | Visual timer shows the amount of segments lit up as a function of the left over time. This is easier to grasp for young children.

Yellow Switch | Switch ON to start timer | Once started the settings will be saved to the permanent eeprom memory, to be retrieved later.
dial | if no Red Button or Green Button is pressed, will set the set POMODORO time | The official Pomodoro time is 25 minutes.
Red Button + dial | Hold and turn Dial to set POMODORO break duration. | The official Pomodoro break time is 5 minutes.
Green Button + dial | Hold and turn Dial to set random beep probability interval. | Must be bigger than zero to enable. Set the probability time at which interval a beep will be heard. This means that “on average” at this interval a beep will be heard. The randomization is to ensure that we are being checked up on at irregular intervals.

### Timing

Input | Functionality [OFF / ON] | Remark
Green Switch | enable/ disable break
Blue Switch | Display Visual timer.
Yellow Switch | If released, the timer will stop immediately.
Dial | Set volume and number of ticks. | The official Pomodoro guide states that the audible ticks remind us of the task at hand and help us to stay focussed.
Red Button | See number of NO’s
Green Button | See number of Yes’s
Blue Button | add 1 to NO
Yellow Button | add 1 to YES

Performance meter
When enabled, the Pomodoro timer will beep at random intervals during timing. The beeps keep you focussed. The idea is to press the Blue or the Yellow button at each beep. Blue for “I admit, I am procrastinating”, Yellow for “yes I am working”. A tally is kept of the key presses, so you can see your good vs bad ratio with the Red and Green Button. This is the computer equivalent of your mother checking up on you at unexpected moments!

Manual counter
The buttons can be pressed at any time. So they can also serve as a manual counter. e.a.how many sit-ups can you do in two minutes? Four kids playing, one person pressing buttons per sit-up. Or kids running back and forth from the wall to the timer for one minute, and pressing their button every time they pass… Yeah, I’m up to something

## MultiTimer

A chess clock for up to four players.

Input | Functionality [OFF / ON] | Comments
Yellow Switch | Menu / Timing | Switching to OFF will always reset the timer

### Menu

Input | Functionality [OFF / ON] | Comments
Green Switch | Fischer Timer | ● Set the time that will be added to every timer after its turn is finished. ● The Fischer timer prevents a player from not using all its time at once. It provides a fighting chance to come back into the game if a player is almost out of time. ● As copied from boardgamearena.com: When playing a timer’s time will never exceed its initial time.
Blue Switch | Random | ● A random timer will be chosen at game startup. ● When selected, all enabled timer button lights are blinking to indicate a random starter.
Yellow Switch | Menu / Start Timing
Dial | Set number of timers, Set time | ● Normal: Set the number of timers. ● If corresponding momentary buttons is pushed: Set a timer’s initial time
Momentar y_buttons | | ● If the light is on, the player is selected to join the game. ● If it is blinking, it is the starting player. ● To set the time of the player, press the button while rotating the dial.

### Timing mode

Input | Functionality [OFF / ON] | Comments
Green Switch | None
Blue Switch | Unpause / Pause
Yellow Switch | Menu / Start Timing

Momentary_but
tons
Next timer | ● If blinking slow: Timer is selected and ticking. Press the button to select the next timer ● If solid: Timer is not selected and not elapsed ● If fast blinking in pause mode: Selected but paused timer ● If fast blinking not in pause mode: checking remaining time while timer not selected ● If Off: Timer elapsed or not initialized

# Professional

## Sequencer

A sequencer indefinitely plays a programmed pattern.
The sequencer has a total length of 32 steps spread out over four bars of 8 steps. The bottom four horizontal segments on the display indicate the active bar, the top and middle horizontal segments indicate the active step on that bar. Each step can contain one note.
At startup of the app a random sequencer song will be generated for you. It will change at every restart of the app. If you like it, you’ll have to store it manually.
Input | Functionality [OFF / ON] | Comments
Green Switch | Normal mode / Eeprom Menu
Yellow Switch | Play mode / Program Mode | (Green Switch must be off)

### Program Mode

Input | Functionality [OFF / ON] | Comments
Blue Switch | Single bar / All bars | If All Bars is ON: When assigning a note to a step, it will be assigned to the step of all 4 bars. This is VERY HANDY. Tip: Use it to create a “base” pattern that is the same for all 4 bars before changing steps individually in all bars to make the song interesting.
Red Button | Play and show note at active sequencer step

Green Button | Set and listen to active note without assigning it | Hold button and rotate dial to choose the active note. Keep on holding the button while pressing the red button to assign the selected note to the current active sequencer step.
Blue Button | Previous step
Yellow Button | Next step
Dial | Move step

### Play Mode

Input | Functionality [OFF / ON] | Comments
Red Button | Hold to show assigned notes at active step as they are played | BONUS: hold and rotate dial to transpose the programmed sequence in auto play mode
Blue Button | Assign active note to active slot
Yellow Button | Next step | Hold down and rotate dial to quickly go forward
Dial | Set step speed

### Eeprom menu

Input | Functionality [OFF / ON] | Comments
Yellow Switch | LOAD / SAVE | Should a song be saved or loaded?
Green Button | Execute | Will save to eeprom or load from eeprom (depending on Yellow Switch)
Dial | Choose song number

## Song composer

Create your own songs and store them permanently in eeprom memory. Or load and edit a song. Each song has a maximum length of 100 notes.

Input | Functionality [OFF / ON] | Comments
Green Switch | Compose mode / Eeprom menu | Compose a song or save or load a song from Eeprom
Blue Switch | Note mode / Index mode | Display note value / Display note position in song

Dial | in autoplay: set speed, in manual mode: scroll through all notes.

### Compose mode

Input | Functionality [OFF / ON]
Red Button in Note mode | Play active note
Green Button in Note mode | Select note | Hold down and turn dial to select active note from scale
Press Red Button while holding Green Button in Note mode | Program note | It’s important to FIRST hold and keep holding Green Button, and then, to program, shortly press Red Button
Red Button in Index Mode | Delete current note in song | Delete slot. Move all notes so there is no gap
Green Button in Index Mode | Insert a note in the song | Insert slot behind current location. The song gets longer. If longer than the maximum allowed number of notes, the last note is erased.
Blue Button | Previous note in song
Yellow Button | Next note in song
Yellow Switch | Manual / Auto | If ON: the note sequence is played automatically
Dial | ● Auto play: set speed ● Manual play: scroll through song.. ● With Green Button in note mode: select note

### Eeprom menu

Input | Functionality [OFF / ON]
Yellow Switch | SAVE / LOAD | Should a song be saved or loaded
Red Button | Execute | Save to eeprom or load from eeprom (depending on Yellow Switch)
Dial | Choose program number

# Uncle Lode’s crazy level

## Hack Time

Observe the FLASH, RAM and EEPROM memories in their rawest state!
Scroll manually or automatically through all the bytes. Let them make noise or just display them on the screen. Show the index or the value of the address. Modify the RAM and EEPROM manually. Can you cheat your way into the game's highscores? If things go wrong, just switch the box on and off again.

Note: The active address is the most left digit on the display

### Modes

Input | Function [OFF / ON] | Remark
Green Switch | Address mode / normal mode
Blue Switch | Mute button | Sound OFF / ON. Every byte encodes for a note. On every change, this note is played. Be prepared for post-modernist masterpieces in auto-mode.
Yellow Switch | Auto scroll / Manual
Blue Button | HOLD and rotate Dial to scroll through memory in increments of 255 addresses
Yellow Button | HOLD and rotate Dial to scroll through memory in increments of 4 addresses | 4 is chosen, because the display can hold four bytes at its most.
Dial | | ● Auto scroll: Change speed ● Manual: Change address

### Address mode

Input | Functionality | Screen
Red Button | Set memory type | Cycle through: ● FLASH: displays F ● RAM: displays R ● EEPROM: displays E

### Normal mode

Input | Functionality | Screen
Green | | Cycle through:

Button with dial | | ● values displayed as ASCII-like character ● values displayed as bytes (7 segments + decimal point = 8 bits represented) ● most left digit on display: decimal ● most left digit on display: hexadecimal
Dial | while Green Button is pressed, write | Hold and rotate Dial to change the active memory byte value from 0 to 255. When the value changes in the memory, a confirmation beep will sound. Will work for eeprom and ram, but not for flash. Beware: when changing RAM, it might change back to another value right away as you’re tweaking the cpu live. Also, the device can suddenly behave strangely. Alternatively, the universe might collapse.

### Value representation

Decimal representation
Value from 0 to 255 (left character on the display)

Hexadecimal representation
Value from 0 to 0xFF (left segment on the display)

Binary representation
Display the raw byte value. See addendum for byte to display conversion.

Character representation
Display the byte value as a character. See addendum for byte to character conversion.

### Memory types

Memory Type | Address range Decimal | Address range Hexadeci mal | Length [bytes] | Edita ble | Retains value when powered off | Function
Flash | 0..32255 | 0..7DFF | 32255 | NO | YES | This memory contains the main program code. It is programmable to upload the firmware, but it cannot be changed from within the program.
Ram | 0..2047 | 0..7FF | 2048 | YES | NO | This fast memory is needed for the program to function
Eeprom | 0..1023 | 0..3FF | 1024 | YES | YES | This slow memory contains values the need to be preserved

### Luciebox eeprom layout

The flash and ram memory are organised beyond my control. But, the eeprom has 1024 bytes that can be programmed and will retain their value, even when the box is switched on and off again. It is strictly organised according to the schematic below.

Address range Decimal | Address range Hexadeci mal | Len gth [byt es] | function
0..7 | 0..7 | 8 | Settings | ● byte 0: Sound disabled ● byte 1..2: Power cycle counter (will only update if at least one of the momentary buttons is pressed after a switch on)
8.. 103 | 8..67 | 96 | Game high scores | each game has 6 levels. High score is 2 bytes (because I choose to believe in your abilities!) ● byte 0..11: Whack a mole ● byte 12..23: Whack a mole endurance mode ● byte 24..35: Whack a bird ● byte 36..47: Whack a bird endurance mode ● byte 48..59: Guitar Hero ● byte 60..71: Guitar Hero with stuttering ● byte 72..83: Hex Hero ● byte 84..95: Hex Hero with stuttering
104..109 | 68..6D | 6 | MultiTimer | ● byte 0: Number of enabled timers ● byte 1..4: Init timer per timer [seconds] ● byte 5: Fischer time [seconds]
110..112 | 6E..70 | 3 | Pomodoro | ● byte 0: Init time [seconds] ● byte 1: Pause time [seconds] ● byte 2: Random beep time [seconds]
113..240 | 71..F0 | 128 | Sequencer | 32 bytes per sequence * 4 sequences
241..640 | F1..280 | 400 | Composer songs | 100 bytes per song * 4 songs
641..1020 | 281..3FC | 380 | Sketch saved Pictures | 4 bytes per picture* 95 pictures
1021..1023 | 3FD..3FF | 3 | Free | Free space. All for you to store secret information, passwords, bitcoin passwords,...

# Extra features

## Luciebox ON time

This functionality has moved to the second chronometer of the chronometer app.

Nothing can be done in this app. The total time since the Luciebox was switched on is displayed. Switch the box OFF and back ON to reset.

## Inactivity timer

Every hour since the last key press, the happy dryer song will play. Unless the Pomodoro Application or Multitimer is activated.

## Randomness fun

Computers have a hard time with random value. They produce always the same sequence of values. By “seeding” a random generator, a starting point in that sequence is chosen.

For the Lucie box, the random seed is done with the internal timer at each app initialization. So, at startup, as long as no app has been changed, the same values will show up for generated random events.

In reality: As long as the selector dial was not rotated, the same random sequence will show up when restarting the Luciebox. That means rolling the dice will have result in the same value sequences, the sequencer generator will create the exact same song, guitar hero will show the same blocks,... .

I did this because it’s fun. For better randomness, change apps with the selector dial after switching the Luciebox on.

https://rheingoldheavy.com/better-arduino-random-values/

## Test and Settings

Button test and Luciebox settings.
Decimal points on display flicker erratically to indicate that the box is alive.
This is a simple buttons test app, that is very appealing to small kids as the behaviour is very predictable. All button presses have an instant effect!
Input | Function [OFF / ON] | Remark
Red Switch | Button test | display: -
Green Switch | Button test | display: -
Blue Switch | Button test | display: -
Yellow Switch | Button test | display: -
Red Button | Button test | display: 0
Green Button | Button test | display: 0

Blue Button | Button test | display: 0
Yellow Button | Button test | display: 0
Dial | Settings Menu | Twist back and forth 3 times to activate the settings menu. Once activated, every consecutive twist will activate the next menu item.

### Settings Menu items

Dial twists | Menu item | Functionality
3 | Enable sound | With Red Button, toggle the sound. This will be stored in the retentive memory.
4 | Battery level | Check the battery or usb voltage. Displayed in millivolts. The battery voltage goes down during the battery life until a level (about 2.7V) until a level where the box cannot operate any longer. Which is called “brown out”. Note: The measured voltage can vary from the battery voltage because of an inline Schottky diode (the voltage of a set of new batteries is too high for the microcontroller. The diode lowers the voltage to be always in range for 4 AA batteries. Add about 700mV to the displayed value for battery voltage.
5 | A0 | The value of the selector dial. The selector dial can be rotated in the A0 menu to check the values without changing apps. Expected values (estimations): 82/168/253/339/425/510/596/682/767/853/938/1023 (which makes for a difference of 85 per position). (If the selector wiper does not make contact, it shows a low value (~ 50). The analog input is then basically floating.)
6 | A1 | The value is an addition of pressed latching buttons. Red Switch:~64, Green Switch: ~128, Blue Switch: ~256, Yellow Switch: ~512
7 | A2 | The value is an addition of pressed momentary buttons. Red Button:~64, Green Button: ~128, Blue Button: ~256, Yellow Button: ~512
8 | A3 | not used for an analog input
9 | A4 | left floating
10 | Firmware version | Have this number ready when contacting the helpdesk.
11 | QTY | Display the amount of times the Luciebox was switched on and at least one momentary button was pressed.

12 | Reset | Press M0 and then M3 for game high scores and timer settings reset Press M0 and then M2 for total reset (includes drawings, composed songs, high scores, sequencer songs)

# Troubleshooting

Problem | Comment
App sometimes restarts. Some apps show a blank screen. Some apps are missing. | The selector dial wiper might have a gap. Bad bad selector switch. With a small screwdriver, bend the wiper downward to eliminate the gap with the outer conducting circle.
Luciebox does not start up, or only for some seconds | Undervoltage, batteries empty.
I have no clue what to do. | Read this manual.
I can’t read yet | Vraag hulp aan een ouder of voogd.
Ik ken geen Engels | Vraag maar aan Omi, zij heeft Engelse les gevolgd!

## Unimplemented apps

App | status | comments | Difficulty [1-5]
Slots machine | not started | Teach children that luck can replace work in order to make money | 3
Timed key press game | not started | Olympics game with keypresses. Press as fast as possible, stay in a steady rhythm or gradually go faster. | 4

# Addendums

## Value representation

### Binary representation

7 segment Digit, segment to byte position. light on = 1

0
5 | 1
6
4 | 2
3 | 7
| XXXX
| X
| XXXX
| X X
e.a. | X X = h57 = b01010111
Segment name | Byte bit index | Segment Position in Digit description
A | 0 | top
B | 1 | up right
C | 2 | bottom right
D | 3 | bottom
E | 4 | bottom left
F | 5 | top left
G | 6 | center
DP | 7 | decimal point

## Music note values

The length of the rests is

Byte value | ⅛ note | Byte valu e | ¼ note | Byte value | ½ note | Byte value | Full note | Byte value | Rest values (multiples of ⅛) (DISPLAY VALUE)
0 | A3_8 | 60 | A3_4 | 120 | A3_2 | 180 | A3_1 | 240 | REST_1_8 (-- 1)
1 | As3_8 | 61 | As3_4 | 121 | As3_2 | 181 | As3_1 | 241 | REST_2_8 (-- 2)
2 | B3_8 | 62 | B3_4 | 122 | B3_2 | 182 | B3_1 | 242 | REST_3_8 (-- 3)
3 | C4_8 | 63 | C4_4 | 123 | C4_2 | 183 | C4_1 | 243 | REST_4_8 (-- 4)
4 | Cs4_8 | 64 | Cs4_4 | 124 | Cs4_2 | 184 | Cs4_1 | 244 | REST_5_8 (-- 5)
5 | D4_8 | 65 | D4_4 | 125 | D4_2 | 185 | D4_1 | 245 | REST_6_8 (-- 6)
6 | Ds4_8 | 66 | Ds4_4 | 126 | Ds4_2 | 186 | Ds4_1 | 246 | REST_7_8 (-- 7)

7 | E4_8 | 67 | E4_4 | 127 | E4_2 | 187 | E4_1 | 247 | REST_8_8 (-- 8)
8 | F4_8 | 68 | F4_4 | 128 | F4_2 | 188 | F4_1 | 248 | REST_9_8 (-- 9)
9 | Fs4_8 | 69 | Fs4_4 | 129 | Fs4_2 | 189 | Fs4_1 | 249 | REST_10_8 (--A )
10 | G4_8 | 70 | G4_4 | 130 | G4_2 | 190 | G4_1 | 250 | REST_11_8 (-- B)
11 | Gs4_8 | 71 | Gs4_4 | 131 | Gs4_2 | 191 | Gs4_1 | 251 | REST_12_8 (-- C)
12 | A4_8 | 72 | A4_4 | 132 | A4_2 | 192 | A4_1 | 252 | REST_13_8 (-- D)
13 | As4_8 | 73 | As4_4 | 133 | As4_2 | 193 | As4_1 | 253 | REST_14_8 (-- E)
14 | B4_8 | 74 | B4_4 | 134 | B4_2 | 194 | B4_1 | 254 | REST_15_8 (-- F)
15 | C5_8 | 75 | C5_4 | 135 | C5_2 | 195 | C5_1 | 255 | RESERVED (eeprom song stop byte) (-- G)
16 | Cs5_8 | 76 | Cs5_4 | 136 | Cs5_2 | 196 | Cs5_1
17 | D5_8 | 77 | D5_4 | 137 | D5_2 | 197 | D5_1
18 | Ds5_8 | 78 | Ds5_4 | 138 | Ds5_2 | 198 | Ds5_1
19 | E5_8 | 79 | E5_4 | 139 | E5_2 | 199 | E5_1
20 | F5_8 | 80 | F5_4 | 140 | F5_2 | 200 | F5_1
21 | Fs5_8 | 81 | Fs5_4 | 141 | Fs5_2 | 201 | Fs5_1
22 | G5_8 | 82 | G5_4 | 142 | G5_2 | 202 | G5_1
23 | Gs5_8 | 83 | Gs5_4 | 143 | Gs5_2 | 203 | Gs5_1
24 | A5_8 | 84 | A5_4 | 144 | A5_2 | 204 | A5_1
25 | As5_8 | 85 | As5_4 | 145 | As5_2 | 205 | As5_1
26 | B5_8 | 86 | B5_4 | 146 | B5_2 | 206 | B5_1
27 | C6_8 | 87 | C6_4 | 147 | C6_2 | 207 | C6_1
28 | Cs6_8 | 88 | Cs6_4 | 148 | Cs6_2 | 208 | Cs6_1
29 | D6_8 | 89 | D6_4 | 149 | D6_2 | 209 | D6_1
30 | Ds6_8 | 90 | Ds6_4 | 150 | Ds6_2 | 210 | Ds6_1
31 | E6_8 | 91 | E6_4 | 151 | E6_2 | 211 | E6_1
32 | F6_8 | 92 | F6_4 | 152 | F6_2 | 212 | F6_1
33 | Fs6_8 | 93 | Fs6_4 | 153 | Fs6_2 | 213 | Fs6_1
34 | G6_8 | 94 | G6_4 | 154 | G6_2 | 214 | G6_1
35 | Gs6_8 | 95 | Gs6_4 | 155 | Gs6_2 | 215 | Gs6_1
36 | A6_8 | 96 | A6_4 | 156 | A6_2 | 216 | A6_1
37 | As6_8 | 97 | As6_4 | 157 | As6_2 | 217 | As6_1
38 | B6_8 | 98 | B6_4 | 158 | B6_2 | 218 | B6_1
39 | C7_8 | 99 | C7_4 | 159 | C7_2 | 219 | C7_1
40 | Cs7_8 | 100 | Cs7_4 | 160 | Cs7_2 | 220 | Cs7_1
41 | D7_8 | 101 | D7_4 | 161 | D7_2 | 221 | D7_1
42 | Ds7_8 | 102 | Ds7_4 | 162 | Ds7_2 | 222 | Ds7_1
43 | E7_8 | 103 | E7_4 | 163 | E7_2 | 223 | E7_1

44 | F7_8 | 104 | F7_4 | 164 | F7_2 | 224 | F7_1
45 | Fs7_8 | 105 | Fs7_4 | 165 | Fs7_2 | 225 | Fs7_1
46 | G7_8 | 106 | G7_4 | 166 | G7_2 | 226 | G7_1
47 | Gs7_8 | 107 | Gs7_4 | 167 | Gs7_2 | 227 | Gs7_1
48 | A7_8 | 108 | A7_4 | 168 | A7_2 | 228 | A7_1
49 | As7_8 | 109 | As7_4 | 169 | As7_2 | 229 | As7_1
50 | B7_8 | 110 | B7_4 | 170 | B7_2 | 230 | B7_1
51 | C8_8 | 111 | C8_4 | 171 | C8_2 | 231 | C8_1
52 | Cs8_8 | 112 | Cs8_4 | 172 | Cs8_2 | 232 | Cs8_1
53 | D8_8 | 113 | D8_4 | 173 | D8_2 | 233 | D8_1
54 | Ds8_8 | 114 | Ds8_4 | 174 | Ds8_2 | 234 | Ds8_1
55 | E8_8 | 115 | E8_4 | 175 | E8_2 | 235 | E8_1
56 | F8_8 | 116 | F8_4 | 176 | F8_2 | 236 | F8_1
57 | Fs8_8 | 117 | Fs8_4 | 177 | Fs8_2 | 237 | Fs8_1
58 | G8_8 | 118 | G8_4 | 178 | G8_2 | 238 | G8_1
59 | Gs8_8 | 119 | Gs8_4 | 179 | Gs8_2 | 239 | Gs8_1

## Display character Values

The letters and digits follow the ASCII standard. The other characters are custom Luciebox characters.
All values that are not indicated in the table will have their value represented as a blank (just like a space).
Character | Binary to 7 segment (left is A, right is DP) | ASCII value | Remark
‘ ‘ | | | Space is not implemented, provide SPACE_FAKE_ASCII. All unrecognized values will resolve into spaces.
0 | B00111111 | 48
1 | B00000110 | 49
2 | B01011011 | 50
3 | B01001111 | 51
4 | B01100110 | 52
5 | B01101101 | 53
6 | B01111101 | 54

7 | B00000111 | 55
8 | B01111111 | 56
9 | B01101111 | 57
ONLY_TOP_SEGMENT_FAKE_ASCII | B00000001 | 58 | Not an official ASCII character
ONLY_MIDDLE_SEGMENT_FAKE_ASCII | B01000000 | 59 | Not an official ASCII character
ONLY_BOTTOM_SEGMENT_FAKE_ASCII | B00001000 | 60 | Not an official ASCII character
ONLY_TOP_AND_BOTTOM_SEGMENT_F AKE_ASCII | B00001001 | 61 | Not an official ASCII character
SPACE_FAKE_ASCII | B00000000 | 62 | Not an official ASCII character
RANDOM | RANDOM | 63 | Not an official ASCII character. This is a SPECIAL CASE. It will randomly toggle its segments each time when assigned.
| B00000000 | 64
A | B01110111 | 65
B | B01111100 | 66
C | B00111001 | 67
D | B01011110 | 68
E | B01111001 | 69
F | B01110001 | 70
G | B00111101 | 71
H | B01110100 | 72
I | B00000110 | 73
J | B00001110 | 74
K | B01110101 | 75
L | B00111000 | 76
M | B01010101 | 77
N | B01010100 | 78

O | B01011100 | 79
P | B01110011 | 80
Q | B01100111 | 81
R | B01010000 | 82
S | B01101101 | 83
T | B01111000 | 84
U | B00011100 | 85
V | B00011110 | 86
W | B00011101 | 87
X | B00110110 | 88
Y | B01101110 | 89
Z | B00011011 | 90
37

# Todo and issues

F305

Please write down all idea’s, suggestions, and bugs.

## F304 changes

Update baby mode. Update songs and music notes handling

## F303 Changes

Settings app: ability to debug selector dial at A0

## F302 Changes

Issue | Status
metronome:button3 hold: set sound also when metronome ON. Change flashing toggle to another button. | No don’t do this. ok like it is. close issue
check if the MAX from random number (bingo) is indeed saved to eeprom once set… | Done

in random mode: dial function: not working. : If Blue Switch and Yellow Switch are off: Generate random values for last selected mode. (dial should be like next step)

Mode draw letters: would be fun to have the probability of drawn letter set to a certain language. English, Dutch,.... this way it can be used in word games. | memory for such a multi language endeavour for now. I could work if we put the probabilities per letter as byte in the eeprom. So, it can be changed in hack mode. Then, to pick a letter: make sum of all probabilities. Choose random number between zero and that total. In a for loop, add the probabilities again, if the chosen random number, is in an interval, that’s our number! aka: previous probability index when counting up. Of, just store the english letter frequencies in the ram. It’s not thaaaat
chronometer (or countdown timer?) Set animation, instead of numbers on screen, show hourglass on screen for countdown | we could use the screen fill animation.

done. Does it add value though?

done in flash Hmmm… not enough

different from dutch...

not done , not needed close

simon says multiplayer mode: do not let everybody do the sequence. Just one person. let random mode decide if it’s
just the next person, or a random person

OK done.

check pascal “No Simon” mode. | OK done
todo quizmaster app: dial sets score in quizmaster mode after question answered. → press all buttons to which a value is added or subtracted. hmm easier: dial changes value of player that pressed

multitimer: multiple timers, next player: not working!

enable random pause in hex hero | that’s silly. But, what we could do: complementary mode: whenever the decimal point is ON, the complement of the given number has to be provided

song composer: check if dial rotating with If momentary 1 or 2 is pressed, sets note.

song composer: hold down momentary0 and rotate dial will not assign notes while dialing

hack time: When the value changes in the memory, a confirmation beep will sound → NOPE

hacktime: representation of values as chars and binary looks like it’s not correct

ok done

ugh, no problem. works! did you read the manual on how to use it ? Closed.

done

reworked done

reworked done

solved.

done

inactivity timer

done beep every X minutes.(30?) → one hour

# Remarks

# Power solutions

- Batteries: 4xAA → this is more like 6.5V when the batteries are new, but, the Luciebox can handle (thanks to a Schottky diode)
- USB Mini connected to a powerbank or a phone charger

# Firmware update

Check the firmware version in the settings app. An update or your own software can be uploaded.

## Background

The arduino platform is used. The arduino bootloader is loaded in the Microcontroller. Imagine the Luciebox as an Arduino UNO board without its microcontroller. When the wires are connected like in the table, programming the Luciebox is like uploading a program to any Arduino Uno board. Experimenting is encouraged.

## Upload firmware procedure

1. Have an arduino UNO board ready. These boards are available for very cheap on aliexpress.
2. Take an arduino uno board, and connect the wires like indicated in the table below. There is no need to modify the arduino uno board. (For serial output to work in debug mode (e.a. Serial.println()), the atmega328 needs to be removed from the original UNO).
3. Open the arduino IDE and load the Luciebox program.
4. Upload the program to the connected “arduino UNO”.
5. Disconnect the RX/ TX pins if the atmega328 is not removed from the UNO board.
6. Done. (you can leave the VCC and GND connected to save on batteries).

## Luciebox to Arduino UNO interface

Pin Arduino programmer | Pin Luciebox | Remarks
VCC | VCC | 5V DC
GND | GND | Ground
TX | TX | Luciebox to Computer
RX | RX | Computer to Luciebox

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
ulle

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
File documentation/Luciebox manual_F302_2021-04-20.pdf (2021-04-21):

# Luciebox

# Owners manual

The Luciebox pretbak, made by Uncle Lode Ameije for Lucie. Project started 2019-04-02. Manual v20210406

# Introduction

I saw a toddler being mesmerized with the sounds and lights after pressing random buttons on one of my multiTimers. Right away I knew what I should give to my brother’s first soon-to-be-born child. What started as a weekend project now has a 40 something pages manual, and Lucie is two years old. The Luciebox is not going to appeal to many people, but I know, if I would have had this box as a kid, I would have worn it out together with my brother. We’d know every feature and bug better than the original creator. Sure, I can claim that there is educational value in this over the top retro device. But, let’s not forget the original mission of this project… It’s time to mesmerize! As I realize now there is no such thing as finished projects, only abandoned projects, I’m welcoming all suggestions and contributions. Looking at you Lucie! Regards from your high-expectations-uncle Lode.

# How to use this box

Don’t be put off by the lack of information on the box. It’s ok to be overwhelmed. Just know that there are 23 applications. An app is selected with the selector dial in combination with the Red Switch. Applications have different degrees of difficulty. Choose an application from the list and try to make it work. I suggest Guitar Hero for a fun introduction. Read the instructions for the specific app and have a go at it. At start leave all the switches in the OFF position to enable the default mode. Experiment away, you can’t do anything wrong.

# Table of contents

Introduction | 2
How to use this box | 2
Table of contents | 2
Getting started | 5
Overview | 5
Applications | 6
Overview | 6
Unimplemented apps | 8
Toddler | 8
Radio | 8
Songs | 8
Music notes | 9
Simple mode | 9
Advanced mode | 9
Metronome | 10
Metronome Manual mode | 10
Metronome Ticking mode | 11
Dreamtime | 11
Child | 11

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
tilt

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
ole, r

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
al m

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
2 Idea for the Pascal sake drinking game | 22

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
5 Independent reaction game mode | 26

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
Timin

g
M

ultiTim

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
Timin

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
al M

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
al m

o

d

e

3

3
Valu

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
al r

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
al r

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
m la

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
8 Inactivity timer | 38 Randomness | 38 Settings App | 38 Settings Menu items | 38

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
O in

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
# Getting started

## Overview


Name in this document | Official name | Description
Power Switch | On / Off switch | Switches on the box with the batteries. If powered by USB or the programming connecter, this will have no effect
Selector | Selector dial | Limitless 12 positions dial, on the left of the lid
Dial | Encoder dial | Limitless smooth dial on the right of the lid
Red Switch | Latching Button 0 | Red toggle button which can be set in the ON or OFF position.
Green Switch | Latching Button 1 | Green toggle button which can be set in the ON or OFF position.
Blue Switch | Latching Button 2 | Blue toggle button which can be set in the ON or OFF position.
Yellow Switch | Latching Button 3 | Yellow toggle button which can be set in the ON or OFF position.

Red Button | Momentary Button 0 | Red push button. When pushed and held, it’s ON, when released, it’s OFF.
Green Button | Momentary Button 1 | Green push button. When pushed and held, it’s ON, when released, it’s OFF.
Blue Button | Momentary Button 2 | Blue push button. When pushed and held, it’s ON, when released, it’s OFF.
Yellow Button | Momentary Button 3 | Yellow push button. When pushed and held, it’s ON, when released, it’s OFF.
Buzzer | Buzzer | A tiny speaker is inside the box. The volume can be set by putting some tape over the hole. The sound can be muted in the settings app
Display | 4 digit 7 segment LED display | Every digit has actually eight segments if we include the little dot, called the decimal point, on its right

# Applications

## Overview

If one of the buttons is held while rotating the selector knob, the splash screen stays visible.
App | Select or | Latch ing 0 | Splash screen | comments | Diffi culty [1-5]
Settings | 1 | 0 | | Test all the buttons. Check configuration. | 1
| 1 | 1
Total Time | 2 | 0 | | Display time from the moment the box is switched on | 2
Stopwatch | 2 | 1 | | All the goodies from a typical 80’s stopwatch. Has two independent timers. | 2
MultiTimer | 3 | 0 | | A game clock for up to 4 players. Can also be used as a chess clock or as a kitchen timer. | 3
Pomodoro timer | 3 | 1 | | The Pomodoro technique helps procrastinators to get things done | 3

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

Geiger | 11 | 0 | Measure your local radio activity. Or generate all kinds of noise.
Hack mode | 11 | 1 | Display and edit the Luciebox memory. Experiment as you like. | 5
Dream time | 12 | 0 | Baby soothing patterns and sounds. | 1
Letters and Numbers | 12 | 1 | Learn how to count, learn the alphabet | 2

## Unimplemented apps

App | status | comments | Difficulty [1-5]
Slots machine | not started | Teach children that luck can replace work in order to make money | 3
Timed key press game | not started | Olympics game with keypresses. Press as fast as possible, stay in a steady rhythm or gradually go faster. | 4

# Toddler

## Radio

Simple music player. Each momentary button will play a song. The standard songs are featured, and your own programmed songs!

Button | Functionality | Comments
Latching_1 | Song bank selector 1 | A combination of the bank selector assigns different songs to the momentary buttons
Latching_2 | Song bank selector 2 | A combination of the bank selector assigns different songs to the momentary buttons
Latching_3 | Playback speed / Transpose | Dial will change the settings while a song is playing

### Songs

Latching button index

2 | 3 | Functionality
0 | 0 | Permanent memory songs bank 1 assigned to momentary buttons
1 | 0 | Permanent memory songs bank 2 assigned to momentary buttons
0 | 1 | Home made songs from the song composer assigned to momentary buttons
1 | 1 | Sequencer songs 1 to 4 assigned to momentary buttons

## Music notes

Plays single notes. Manually or automatically. Test different scales and modes.
Button | Functionality [OFF / ON] | Comments
Latching_1 | Simple mode / Advanced mode | see different chapters for controls in each mode
Latching_2 | Single note / Queue | In queue mode, all pressed notes will be added to the buffer. In single mode, the buffer will be erased before adding a note.
Latching_3 | Manual mode / Auto arpeggio | Auto arpeggio will automatically play the next note after a timed interval
Dial | | in auto arpeggio: set interval, in manual mode: go up or down the scale

### Simple mode

Button | Functionality | Comments
Momentary_0 | Mute | Will not make sound while changing notes
Momentary_1 | Play active note | Just play the last played note
Momentary_2 | Previous note | Previous note on the active scale
Momentary_3 | Next note | Next note on the active scale

### Advanced mode

Button | Functionality | Comments
Momentary_0 | Duration | Press to cycle between full, half, quarter, eight notes
Momentary_1 | Progression | Press to cycle between

| | ● MANU: Manual (default, set direction yourself), ● UP: Going up the scale, ● DO: Going down the scale, ● UPDO: Saw pattern, going up and down, changing at a random interval ● RND: Random picking of a note on the scale ● CRAY: Crazy mode going randomly up and down at erratic intervals.
Momentary_2 | Scale | Cycle between different scales: ● AJOR: Major ● INOR: Minor ● PENT: Pentatonic ● BLUE: Blues Major ● CHRO: Chromatic
Momentary_3 | Key | Cycle between all 12 tones in an octave to set the key of the selected scale.

## Metronome

A classic metronome with fun visual effect.
12 steps per cycle, up to three tickers.
Button | Functionality [OFF / ON] | Comments
Latching_1 | Make ticker 2 step backwards
Latching_2 | Set speed in beats per minute (bpm) | One ‘beat’ is a full circle of 12 steps.
Latching_3 | Manual mode / Ticking mode
Momentary_0 | Reset the positions of all tickers | Set to the position of ticker 1
Momentary_1 | Increase ticker 2 offset by one
Momentary_2 | Increase ticker 3 offset by one

### Metronome Manual mode

Button Momentary_3 | Functionality | Comments
Single press | manual step
Not pressed | rotate dial to step
Hold and dial | Change tick sounds | note length: shorter (rotate clockwise) or longer (rotate counter clockwise) beeps. Shorter beeps lose their pitch, and are more like a metronome ‘puck’ sound.

### Metronome Ticking mode

Button | Functionality | Comments
Momentary_3 | Flash screen toggle | Will toggle screen flashing at every beep. This improves metronome feedback in loud environments.
dial | | change bpm

## Dreamtime

Mesmerize and go on a trippy hypno voyage where sound and graphics are ruled by randomness and chaos.
Button | Functionality [OFF / ON] | Comments
Latching_1 | Pitch offset | Offset is set with dial
Latching_2 | Unmute / Mute | Every segment has a sound assigned.It’s played when it appears or disappears. Sounds are a 32 values range off the total of 256 available sounds. The offset is settable.
Latching_3 | Auto / Manual | Dial will change step in manual and set interval speed in auto mode
Momentary_2 | Previous step | Only in manual mode
Momentary_3 | Next step | Only in manual mode

# Child

## Easy timer

Displays the time since the box was switched on. There are no controls in this app.

## Letters and Numbers

Learn how to count and learn the alphabet.
Learn how to be a bouncer by using the counting function to keep track of the number of guests in your bar.
Button | Functionality [OFF / ON] | Comments
Latching_1 | Number mode / alphabet mode | display numbers or letters
Latching_2 | Numbers as Decimal / Hexadecimal | Only effective in number mode
Latching_3 | Manual / Auto count | Auto mode

| | ● Song is played when in alphabet mode ● Dial changes the speed Manual mode ● Dial changes value
Momentary_0 | in auto mode: toggle count up / down
Momentary_1 | set value zero
Momentary_2 | value down
Momentary_3 | value up

## Score tracker

Keeps up to four different tallies. Can also be used for general counting. Cribbage, snooker, darts,...

Button | Functionality [OFF / ON] | Comments
Latching_1 | Count up / Count down
Latching_2 | Apply score change to single tally / to all tallys
Latching_3 | Modify mode / View mode | In view mode, every tally can be checked without modifying it
Momentary_0 | Tally 1
Momentary_1 | Tally 2
Momentary_2 | Tally 3
Momentary_3 | Tally 4
dial | Hold momentary + dial → set delta | Will show the delta on the screen as long as the momentary button is not released.

## Movement detector (tilt fun)

Deprecated app. Will be made available again on popular request and when mercury switches are deemed environmentally friendly.
Move the box around to count.
Button | Functionality [OFF / ON] | Comments
Latching_1 | go through all four positions for a full cycle / skip lateral movements for a full cycle. | don’t take lateral movement into account

Latching_2

Latching_3

Dial

Move the box around, inside are motion detectors. When moved through a cycle correctly, the counter will increase.
Put the box on a swing, see how many times you can swing in a minute!

## Sketch pad

All drawings are stored in eeprom. Scroll through and edit the drawings.

### Modes

Button | Functionality [OFF / ON] | Remark
Latching_1 | ON: Save menu | Save a drawing to the eeprom memory
Latching_2 | Display Image / Display Index | “Display index” displays the eeprom drawing address
Latching_3 | View / Draw | In draw mode, drawings can be edited

### Display mode

Control | Functionality | Screen

Momentary_0

Momentary_1 | Global display setting | cycle through: ● normal (default) ● negative ● all on ● all off ● STOP screen
Momentary_2 | Previous drawing
Momentary_3 | Next drawing
Dial | Scroll through drawings

### Draw mode

Control | Functionality | Screen
Momentary_0 | Toggle active segment
Momentary_1 | Global display setting | cycle through:

| | ● normal (default) ● negative ● all on ● all off ● STOP screen
Momentary_2 | Move cursor inside digit
Momentary_3 | Move cursor to next digit
Dial | Move cursor

### Save To eeprom Mode

When scrolling through images, will NOT update the screen. The buffer stays the same. This way, you can scroll through the desired image (used index to see number) and save .
Control | Functionality | Comments
Momentary_0 | Save screen | Will save the drawing to the active EEPROM address (visible with Latching_1)
Momentary_1 | HOLD to have “shift function for momenary_2 and momentary_3
Momentary_2 | previous drawing OR with SHIFT FUNCTION: delete drawing slot (and move all indexes, ) | Hold down Momentary_1 for it to work
Momentary_3 | next drawing OR with SHIFT FUNCTION: insert drawing slot and move all indexes from other drawings. Will overwrite the last drawing from eeprom. | Hold down Momentary_1 for it to work
Dial | move through drawings.

### How to create animations

Step | Comment | Example
1 | Create and save a drawing with the STOP marker. (Draw mode → global display settings → stop screen) | drawing 27: STOP
2 | use as many frames as you want the next drawings | drawing 28: UNCL drawing 29: LODE drawing 30: IS drawing 31: OLD COOL
3 | To indicate that the drawings are an animation, create and save another STOP drawing. | drawing 32: STOP
4 | Animations can be watched with the media player.

## Memory Game

Look at the picture, memorize it, press the start button. Try to reproduce it!
There are four modes available: Random segments, Numbers, Letters, Digital clock. This game is really fun to play as a collaborative challenge with a team!
Button | Functionality [OFF / ON] | Remark
Latching_1 | Play mode option 1
Latching_2 | Play mode option 2
Latching_3 | Menu / Play | In menu the generated pattern is already shown

### Menu

Play mode defines which image will be generated on the display
Play Mode | Latching_1 | Latching_2 | Generate and display pattern
Random | OFF | OFF | Random segments (difficult mode)
Numbers | ON | OFF | Random digits (0000 to 9999)
Letters | OFF | ON | Random letters (AAAA to ZZZZ)
Clock | ON | ON | Random clock value (00.00 to 23.59)

### Play

Step | Comment
1 | Make sure Latching_3 is set to OFF
2 | Memorize what’s displayed on the screen
3 | Switch Latching_3 to ON
4 | Try to reproduce the screen as it was shown at the start. See the draw app on how to draw on the display
5 | When done with drawing, switch Latching_3 to OFF
6 | If done correctly, a victory song will play. If you didn’t manage to reproduce the original drawing, the differences will be displayed.

## Random world

Show various random generated events.

Button | Functionality [OFF / ON] | Remark
Latching_1 | Shift | Each of the momentary buttons gets another function if ON.
Latching_2 | animate? | “Rolling animation” if ON.
Latching_3 | Manual / Auto draw | Auto draw: ● Set the draw interval time in seconds with the dial. ● Press a momentary button to start the auto draw Manual draw: ● Press a momentary button for each draw
Dial | | Manual draw mode: ● rotate to draw

### Random modes

Button | Shift ? | Function
Momentary_0 | No | Single Dice | Display shows eyes like a real dice
Momentary_0 | Yes | Roll 4 dice at once | Each dice has its own digit. display: VVVV V = [1-6]
Momentary_1 | No | Random Letter Shows random letter and its position in the alphabet | display: VV L VV = position of letter in alphabet L = representation of letter.
Momentary_1 | Yes | Draw the next card from a shuffled deck. The card is discarded at next draw. When all cards from the deck are gone, a new deck is shuffled. Sound will sound when a new deck is taken and shuffled. | display: V S V = value S = Suit Values: 1 = ACE, 11 = JACK, 12 = QUEEN 13 = KING Suits: S = Spades C = Clubs H = Hearts D = Diamonds
Momentary_2 | No | Random number in manual mode : hold button (minimum 2

| | seconds, and keep holding) to set upper limit with Dial.
Momentary_2 | Yes | Random sequence (=tombola) Custom Value [0-xxx] Set maximum value xxx by holding the button and turning the Dial. xxx will be saved in eeprom. in manual mode : hold button (minimum 2 seconds, and keep holding) to set upper limit with Dial. Will draw all numbers from the set (max 100 numbers) before starting a new set. Sound will sound when new sequence produced.
Momentary_3 | No | Coin toss | display: HEAD (=head) or TAIL (=tails)
Momentary_3 | Yes | Psychic experience. Ask a question, your grand-grand aunty Lucy will respond with yes or no. | display: YES or NO

## Stopwatch

Two independent classic chronometers.
Control | Functionality [OFF / ON] | Remark
Latching_1 | None | The rarest of beasts! A button without a function! Contact Uncle Lode if you have an idea.
Latching_2 | Display maximum precision or seconds precision
Latching_3 | Stopwatch 1 / Stopwatch 2 | The two stopwatch controls are not influencing each other
Momentary_0 | Hold to show split time
Momentary_1 | Hold to save split time and show
Momentary_2 | Reset
Momentary_3 | Toggle Start Pause

## Geiger

A geiger counter detects radioactive decay. Every time radiation is sensed, a beep is emitted. The more beeps you hear, the more contaminated the environment is!

Note: There is no real radioactivity meter installed in the Luciebox. It’s all fake fake fake.

Button | Functionality [OFF / ON] | Remark
Latching_1 | Geiger mode / Noise mode
Latching_2 | Animated / Counter
Dial | sensitivity

### Geiger Mode

Button | Function | Comment
Momentary_0 | None | Contact uncle Lode if you have a functionality idea
Momentary_1 | None | Contact uncle Lode if you have a functionality idea
Momentary_2 | None | Contact uncle Lode if you have a functionality idea
Momentary_3 | Temporary sharp increase of tick probability | When pressed, it looks like there is a lot more radiation. Practical joke idea: Hold the box close to a person and press the button…. it then appears like the person is contaminated. Hilarity ensues! Warning, do not use this prank near microwave ovens. People are already paranoid enough about them as it is.
Dial | Set tick probability

### Noise Mode

Offers the possibility to tune Geiger as a random note generator.

Button | Functionality | Comment
Latching_3 | Prolonged beep | Every beep will sound until another beep takes over if ON.
Momentary_0 | Lower frequency | Keep pressed while rotating Dial(CW=higher, CCW = lower)
Momentary_1 | Upper frequency | Keep pressed while rotating Dial (CW=higher, CCW = lower)
Momentary_2 | Note length | Keep pressed while rotating Dial(CW=longer, CCW = shorter)
Momentary_3 | trigger manually | Keep pressed while rotating dial for massive hits

## Whack a mole, reaction game

### Menu

Button | Functionality [OFF / ON] | Remark
Latching_1 | Whack a mole / whack a bird | Can only be changed in Menu
Latching_2 | Normal mode / Endurance mode | Can only be changed in Menu
Latching_3 | Menu / Play
Dial | Set level | Can only be changed in Menu

### Play Whack a mole

Every momentary button represents a mole that’s popping up. Your task is to hit it when it stick its head out! When the light goes on, you have to press the button as quick as possible to gain high scores.

Step | Function
1 | In the menu, the level (L x) and its high score are shown intermittently. Choose a level with the dial.
2 | Switch Latching_3 to ON to start playing
3 | If a momentary button lights up (or a decimal point on the display), the corresponding button needs to be pressed.
4 | When the button is pressed, the light goes out. If it stays on, the button needs to be pressed again as that persistent mole needs more whacking!
5 | If a wrong button is pressed, or if time ran out, the game ends
6 | At game end, your mole whacking score will be displayed. If you have a new high score, a victory song will be played.
7 | After some seconds, a new game will start automatically. Go to step 3.
8 | Switch Latching_3 to OFF to end the game and enter the menu at any time

### Play Whack a bird

Step | Function
1 | When the application is selected, four random notes from the chromatic scale are chosen. These notes stay the same for as long as the Whack-a-mole application is active.
2 | In the menu, the level (L x) and its high score are shown intermittently. Choose a level with the dial.

3 | Switch Latching_3 to ON to start playing
4 | The four notes will be heard as a sequence. For each note, a button is assigned. It will light up when the sequence is playing.
5 | Now a note is played. Press the corresponding momentary button to whack that bird. (In level one, rookie mode, the corresponding button is lit up as a visual clue.)
6 | If a wrong button is pressed, or if time ran out, the game ends
7 | At game end, your bird whacking score will be displayed. If you have a new high score, a victory song will be played.
8 | After some seconds, a new game will start automatically. Go to step 4.
9 | Switch Latching_3 to OFF to end the game and enter the menu at any time

### Normal mode

The time assigned is the maximum time between two whacks.
Level | Maximum reaction time[s] | Comments
1 | 30 | This seems long. But, run around the table or house for every mole you whack. How long can you last? What else can you do?
2 | 5
3 | 2.5
4 | 1
5 | ~0.5
6 | ~0.3 | Obviously uncle Lode maxed out on this one!

### Endurance mode

The time assigned is the total whacking time. Try to whack as many animals in that given time frame. Beware, one mistake and you have to start all over again…
level | Total whack time
1 | 2 minutes
2 | 1 minute
3 | 30 seconds
4 | 20 seconds
5 | 10 seconds
6 | 5 seconds

# Adolescent

## Simon

Simon says is a game where people try to repeat progressively longer sequences of button presses.

### Main menu

Button | Functionality [OFF / ON]
Latching_1 | Simon / without Simon | Normally Simon decides the sequence. In games without Simon, every level, a player adds a step to the sequence.
Latching_2 | All players repeat/ one player repeats | In multiplayer: all players have to enter the sequencer (computer decides player sequence) or only one random chosen player has to repeat it.
Latching_3 | Main menu / Play | When playing, set to OFF to enable menu and reset game
Dial | set number of players

### Game selection

Latchin g_1 | Latchin g_2 | Functionality implemented | desired functionality (future)
0 | 0 | Play with Simon. Every turn, the computer makes the sequence one step longer. In multiplayer, all players in random order (the number is displayed on the screen) have to repeat the sequence
0 | 1 | Play with Simon. Every turn, the computer makes the sequence one step longer. In multiplayer, only one player is chosen to repeat the sequence. The chosen player id is displayed.
1 | 0 | Play without Simon. Players build the sequence. The first player in a new rounds sets the new last step in the sequence. Every player repeats the sequence.
1 | 1 | Play without Simon. Players build the sequence. Only one random player has to repeat the sequence. He decides what the next last step is. | Pascal sake drinking game: Player presses a sequence (length decided by computer?) computer chooses another player who has to repeat it.

TODO: Mode Pascal Sake Drinking Game
Use random switch AND custom build up options at the same time. For every round, a random player has to add a button press to the sequence.
→ a lot more fun when not
everybody has to do the new sequence.

### Play with Simon

Display | Function | Comments
Sxx | De computer player Simon shows a light sequence. | x = length of lights sequence [1-99]
nPxx | Player n has to repeat the light sequence Simon showed. Every button stands for a light. | Lights from left to right correspond with momentary buttons from left to right. n = player id [1 to 9]
nPxx/ END (blink) | All players are out. Last surviving player is n, with score: xx | Display blinks, during a repetition of the sequence one more time. After which a new game starts.

### Play without Simon

Display | Function | Comments
nPxx | Player n has to repeat the light sequence that’s already set. Every button stands for a light. At the end of the sequence, the player adds one more step by pressing one of the buttons of his choice. | Lights from left to right correspond with momentary buttons from left to right. n = player id [1 to 9]
nPxx/ END (blink) | All players are out. Last surviving player is n, with score: xx | Display blinks, during a repetition of the sequence one more time. After which a new game starts.

### Idea for the Pascal sake drinking game

Display | Function | Comments

nPxx | Player n inputs a certain sequence with the momentary buttons. The length of the sequence is defined by x | x = length of sequence [1-99] Use momentary buttons to input a sequence. n = player id [1 to 9]
nPpP | Player n has to repeat the light sequence Player p showed. This could be the same player (p could = n) | Use momentary buttons to input a sequence. n = player id [1 to 9]
pP / OUT (blink) | If player p makes a mistake, he’s out. Not sure if we continue then with a new sequence or if the next player has to input the correct sequence (this would ensure everybody keeps paying attention!) | Display blinks for 2 seconds, before continuing
nP / END (blink) | All players are out. Last surviving player is n | Display blinks for two seconds before restarting a new game

## Guitar Hero

Button | Functionality [OFF / ON] | Remark
Latching_1 | Guitar hero / Hex hero
Latching_2 | Normal / Extra mode | Extra mode: Guitar hero: Adds random paused Hex Hero: Input the complement of what you see for all digits with a dot. e.a. 6. → 1001
Latching_3 | Menu / Play
Dial | In Menu: Choose level | Higher level number = faster

### Play Guitar Hero

Step | Function
1 | In the menu, the level (L x) and its high score are shown intermittently. Choose a level with the dial.
2 | Switch Latching_3 to ON to start playing
3 | Lines fall down from the top of the screen.
4 | Once lines have reached the bottom, you have to delete them by pressing the corresponding momentary button. Only delete lines that are AT the bottom.
5 | The game ends if a button is pressed at the wrong time, or lines are not deleted in time.
6 | At game end, your score will be displayed. If you have a new high score, a victory song

| will be played.
7 | After some seconds, a new game will start automatically. Go to step 4.
8 | Switch Latching_3 to OFF to end the game and enter the menu at any time

Team tip: Play guitar hero together: Every player holds his finger on one or more buttons.

### Play Hex Hero

By the year 2036, having a reflexive knowledge of hexadecimal patterns will vastly improve your chances on the job market. Hex hero is an industry leading hex patterns trainer.
Step | Function
1 | In the menu, the level (L x) and its high score are shown intermittently. Choose a level with the dial.
2 | Switch Latching_3 to ON to start playing
3 | Hexadecimal numbers characters scroll into the screen from the left
4 | Press the corresponding nibble (=half byte) pattern with the momentary buttons to delete the most right hex number. Try to keep a clear screen. See the “Hex character to button pattern conversion table” below. In extra mode (Latching_2 ON), digits with a dot will appear. These need to have the inverted nibble pattern inputted. That’s called “the complement”.
5 | The game ends if the hex numbers scroll out of the screen before they are deleted.
6 | At game end, your score will be displayed. If you have a new high score, a victory song will be played.
7 | After some seconds, a new game will start automatically. Go to step 4.
8 | Switch Latching_3 to OFF to end the game and enter the menu at any time

Hex character to button pattern conversion table
Example: B shows up on the screen. B represents the value of 11 in decimal. In binary, B is 1011. Mimic this pattern with the momentary buttons by simultaneously pressing buttons 0, 2 and 3.
Charact er display ed | Decim al value | Convert ed to binary | Required button pattern to be pressed simultaneously | Extra: Compleme nt
| | | Momentary _0 | Momentary _1 | Momentary _2 | Momentary _3
1 | 1 | 0001 | | | | x | 1110
2 | 2 | 0010 | | | x | | 1101

3 | 3 | 0011 | | | x | x | 1100
4 | 4 | 0100 | | x | | | 1011
5 | 5 | 0101 | | x | | x | 1010
6 | 6 | 0110 | | x | x | | 1001
7 | 7 | 0111 | | x | x | x | 1000
8 | 8 | 1000 | x | | | | 0111
9 | 9 | 1001 | x | | | x | 0110
A | 10 | 1010 | x | | x | | 0101
B | 11 | 1011 | x | | x | x | 0100
C | 12 | 1100 | x | x | | | 0011
D | 13 | 1101 | x | x | | x | 0010
E | 14 | 1110 | x | x | x | | 0001
F | 15 | 1111 | x | x | x | x | 0000

## Quiz master

One person is the quiz master. Up to four players are the participants. When the quiz master presses the button, a random timer is started. After that time is elapsed, the lights of the player buttons go on. Every player has a button. First one who presses can answer the question. If the player is correct, he keeps his button pressed while the quizmaster resets his button. That way, a point is added to his score. And off to the next round!

Button | Functionality [OFF / ON] | Remark
Latching_1 | Normal / Long maximum wait time | ● normal: max 3 seconds ● long: max 20 seconds (which is very long!)
Latching_2 | Quizmode / Independent mode | in independent mode, this is a reaction game. At the random intervals, the light goes on. First player pressing gets a point. auto play some rounds.
Latching_3 | Question asked | Quizmaster “just asked a question button” In independent mode: ON=play game

Dial

### Quizmaster

Step | Comments

1 | Every player gets a momentary button assigned.
2 | Quizmaster asks question
3 | Quizmaster sets Latching_3 to ON
4 | When the momentary buttons light up, the players can press their corresponding button. The first players pressing its button can answer. A player that presses its button before it’s lit up will have its score reset.
5 | Quizmaster can now turn dial to add or subtract a point to the player’s score
6 | Quizmaster sets Latching_3 to OFF
7 | Go to step 2

### Independent reaction game mode

In independent mode, this becomes a very fun multiplayer reaction game.
Step | Comments
1 | Every player gets a momentary button assigned.
2 | Start the game by setting Latching_3 to ON
3 | Wait until the button lights go on.
4 | The first player to press its corresponding button (when the light is on) gets a point. All players that press their buttons before it’s lit up will have their score reset.
5 | First player to reach ten points will hear a victory song.
6 | Reset the game with Latching_3

## Movie Player

Combine animations with songs to create full featured movies.

Functionality | Latching Button | Momentary Button | Dial
| 0 | 1 | 2 | 3 | 0 | 1 | 2 | 3
Sound Off (=Mute button) | 1 | | 1
Sound On | 1 | | 0
Autoplay movies | 1 | | | 0
Set playback speed | 1 | 0 | | 0 | | | | | Turn
Manual movie mode | 1 | | | 1

Scroll through frames | 1 | 0 | 1 | | | | | Turn
Play song | 1 | 1 | | 1 | 0 | 0 | 0
Toggle between continuous repeat of song and only play at start of movie | 1 | 1 | | 0 | 1 | 0 | 0
Previous Song | 1 | 1 | | 0 | 0 | 1 | 0
Next Song | 1 | 1 | | 0 | 0 | 0 | 1
Next Movie | 1 | 0 | | 1 | 0 | 0 | 0
Display Inverted | 1 | 0 | | 0 | 1 | 0 | 0
Previous frame | 1 | 0 | 1 | 0 | 0 | 1 | 0
Next frame | 1 | 0 | 1 | 0 | 0 | 0 | 1
Play movie forwards | 1 | 0 | 0 | 0 | 0 | 1 | 0
Play movie backwards | 1 | 0 | 0 | 0 | 0 | 0 | 1

### Animation selection

Cycle through all the animations with the “next movie” button.
Sequence: built in animations - home made animations
Note: See DRAW app on how to create a home made animation

### Song selection

Cycle through all the songs with the next and previous buttons. Sequence: 8 built in songs - 4 composed songs - 4 sequencer songs

## Pomodoro Performance Meter

The Pomodoro Timer is a well known tool to be able to concentrate for specific task such as studying, filing in taxes, doing homework, cleaning, …
https://en.wikipedia.org/wiki/Pomodoro_Technique

The implementation tries to imitate the original as closely as possible. It also has an experimental performance meter. When enabled, the timer will beep at random intervals. At these beeps, you have to press the “Yes, I was working button” or the “no, I was procrastination or dreaming” button. A tally is kept of the key presses, so you can see your good vs bad ratio. This is the computer equivalent of your mother checking up on you at unexpected moments!

The official Pomodoro timer is a kitchen timer which has to be wind up manually. This very physical act prepares the mind for the task at hand. But, as we are automation aficionado's, an auto mode was added that automatically restarts the cycle after a settable pause.

When enabled, during the Pomodoro timing, at random intervals, beeps will be heard. When a beep is
heard, a button needs to be pressed. Assign your values to the buttons. Good, bad, sleeping | The
buttons can be pressed at any time. This way, they can serve also as a manual counter. e.a.how many sit-ups can you do in two minutes? Four kids playing, one person pressing buttons per sit-up. Or kids running back and forth from the wall to the timer for one minute, and pressing their button every time they pass… Yeah, I’m up to something

### Menu

Control | Functionality [OFF / ON] | Remark
Latching_1 | Enable Break time and auto restart
Latching_2 | Enable Visual Timer | Visual timer shows the amount of segments lit up as a function of the left over time. This is easier to grasp for young children.
Latching_3 | Switch ON to start timer | Once started the settings will be saved to the permanent eeprom memory, to be retrieved later.
dial | if no momentary_0 or momentary_1 is pressed, will set the set POMODORO time | The official Pomodoro time is 25 minutes.
Momentary_0 + dial | Hold and turn Dial to set POMODORO break duration. | The official Pomodoro break time is 5 minutes.
Momentary_1 + dial | Hold and turn Dial to set random beep probability interval. | Must be bigger than zero to enable. Set the probability time at which interval a beep will be heard. This means that “on average” at this interval a beep will be heard. The randomization is to ensure that we are being checked up on at irregular intervals.

### Timing

Control | Functionality [OFF / ON] | Remark
Latching_1 | enable/ disable break
Latching_2 | Display Visual timer.
Latching_3 | If released, the timer will stop immediately.
Dial | Set volume and number of ticks. | The official Pomodoro guide states that the audible ticks remind us of the task at hand and help us to stay

| | focussed.
Momentary_0 | See number of NO’s
Momentary_1 | See number of Yes’s
Momentary_2 | add 1 to NO
Momentary_3 | add 1 to YES

## MultiTimer

A chess clock for up to four players.

Button | Functionality [OFF / ON] | Comments
Latching_3 | Menu / Timing | Switching to OFF will always reset the timer

### Menu

Button | Functionalit y [OFF / ON] | Comments
Latching_1 | Fischer Timer | ● Set the time that will be added to every timer after its turn is finished. ● The Fischer timer prevents a player from not using all its time at once. It provides a fighting chance to come back into the game if a player is almost out of time. ● As copied from boardgamearena.com: When playing a timer’s time will never exceed its initial time.
Latching_2 | Random | ● A random timer will be chosen at game startup. ● When selected, all enabled timer button lights are blinking to indicate a random starter.
Latching_3 | Menu / Start Timing
Dial | Set number of timers, Set time | ● Normal: Set the number of timers. ● If corresponding momentary buttons is pushed: Set a timer’s initial time
Momentar y_buttons | | ● If the light is on, the player is selected to join the game. ● If it is blinking, it is the starting player. ● To set the time of the player, press the button while rotating the dial.

### Timing mode

Button | Functionality [OFF / ON] | Comments

Latching_1 | None
Latching_2 | Pause / Unpause
Latching_3 | Menu / Start Timing
Momentary _buttons | Next timer | ● If blinking slow: Timer is selected and ticking. Press the button to select the next timer ● If solid: Timer is not selected and not elapsed ● If fast blinking in pause mode: Selected but paused timer ● If fast blinking not in pause mode: checking remaining time while timer not selected ● If Off: Timer elapsed or not initialized

# Professional

## Sequencer

A sequencer indefinitely plays a programmed pattern.
The sequencer has a total length of 32 steps spread out over four bars of 8 steps. The bottom four horizontal segments on the display indicate the active bar, the top and middle horizontal segments indicate the active step on that bar. Each step can contain one note.
At startup of the app a random sequencer song will be generated for you. It will change at every restart of the app. If you like it, you’ll have to store it manually.
Button | Functionality [OFF / ON] | Comments
Latching_1 | Normal mode / Eeprom Menu

### Normal Mode

Button | Functionality [OFF / ON] | Comments
Latching_2 | one bar / all bars | If ON: When assigning a note to a step, it will be assigned to the step of all 4 bars. VERY HANDY. Use this to create a “base” melody that is the same for all 4 bars.
Latching_3 | Manual / Autoplay | If no momentary buttons pressed, dial will set speed in autoplay mode
Momentary_0 Manual mode | Play and show assigned note at active step
Momentary_0 | Hold to show | BONUS: hold and rotate dial to transpose the

Autoplay | assigned notes at active step as they are played | programmed sequence in auto play mode
Momentary_1 | Set and listen to active note without assigning it | hold and rotate dial to choose the active note
Momentary_2 | Assign active note to active slot | rotate the dial to choose an active note (will not be shown on display)
Momentary_3 | Next step | Hold down and rotate dial to quickly go forward or backward

### Eeprom menu

Button | Functionality [OFF / ON] | Comments
Latching_3 | LOAD / SAVE | Should a song be saved or loaded?
Momentary_1 | Execute | Will save to eeprom or load from eeprom (depending on latching_3)
Dial | Choose song number

## Song composer

Create your own songs and store them permanently in eeprom memory. Or load and edit a song. Each song has a maximum length of 100 notes.

Button | Functionality [OFF / ON] | Comments
Latching_1 | Compose mode / Eeprom menu | Compose a song or save or load a song from Eeprom
Latching_2 | Note mode / Index mode | Display note value / Display note position in song
Dial | in autoplay: set speed, in manual mode: scroll through all notes.

### Compose mode

Button | Functionality [OFF / ON]
Momentary_0 in Note mode | Play active note
Momentary_1 in Note mode | Select note | Hold down and turn dial to select active note from scale

Press Momentary_0 while holding Momentary_1 in Note mode | Program note | It’s important to FIRST hold and keep holding Momentary_1, and then, to program, shortly press Momenary_0
Momentary_0 in Index Mode | Delete current note in song | Delete slot. Move all notes so there is no gap
Momentary_1 in Index Mode | Insert a note in the song | Insert slot behind current location. The song gets longer. If longer than the maximum allowed number of notes, the last note is erased.
Momentary_2 | Previous note in song
Momentary_3 | Next note in song
Latching_3 | Manual / Auto | If ON: the note sequence is played automatically
Dial | ● Auto play: set speed ● Manual play: scroll through song.. ● With momentary_1 in note mode: select note

### Eeprom menu

Button | Functionality [OFF / ON]
Latching_3 | SAVE / LOAD | Should a song be saved or loaded
Momentary_0 | Execute | Save to eeprom or load from eeprom (depending on latching_3)
Dial | Choose program number

# Uncle Lode’s crazy level

## Hacktime

See the FLASH, RAM and EEPROM memories in their rawest state!
Scroll manually or automatically through all the bytes. Let them make noise or just display them on the screen. Show the index or the value of the address. Modify the RAM and EEPROM manually. Can you cheat your way into the game highscores? If things go wrong, just switch the box on and off again.

note: Active address is the most left digit on the display

### Modes

Button | Function [OFF / ON] | Remark
Latching_1 | Address mode / normal mode
Latching_2 | Mute button | Sound OFF / ON. Every byte encodes for a note. On every change, this note is played. Be prepared for post-modernist masterpieces in auto-mode.
Latching_3 | Auto scroll / Manual
Momentary_2 | HOLD and rotate Dial to move memory location x255
Momentary_3 | HOLD and rotate Dial to move memory location x4 | 4 is chosen, because the display can hold four bytes at its most.
Dial | | ● Auto scroll: Change speed ● Manual: Change address

### Address mode

Control | Functionality | Screen
Momentary_0 | Set memory type | Cycle through: ● FLASH: displays F ● RAM: displays R ● EEPROM: displays E

### Normal mode

Control | Functionality | Screen
Moment ary_1 with dial | | Cycle through: ● values displayed as ASCII-like character ● values displayed as bytes (7 segments + decimal point = 8 bits represented) ● most left digit on display: decimal ● most left digit on display: hexadecimal
Dial | while Momentary_1 is pressed, write | Hold and rotate Dial to change the active memory byte value from 0 to 255. When the value changes in the memory, a confirmation beep will sound. Will work for eeprom and ram, but not for flash. Beware: when changing RAM, it might change back to another value right away as you’re tweaking the cpu live. Also, the device can suddenly behave strangely. Alternatively, the universe might collapse.

### Value representation

Decimal representation
Value from 0 to 255 (left character on the display)

Hexadecimal representation
Value from 0 to 0xFF (left segment on the display)

Binary representation
7 segment Digit, segment to byte position. light on = 1 0
5 | 1
6
4 | 2
3 | 7
| XXXX
| X
| XXXX
| X X
e.a. | X X = h57 = b01010111
Segment name | Byte bit index | Segment Position in Digit description
A | 0 | top
B | 1 | up right
C | 2 | bottom right
D | 3 | bottom
E | 4 | bottom left
F | 5 | top left
G | 6 | center
DP | 7 | decimal point

Character representation
All values that are not indicated in the table will have their value represented as a blank (just like a space)

Character

Binary to 7
segment (left

ASCII
value

Remark

| is A, right is DP)
‘ ‘ | | | Space is not implemented, provide SPACE_FAKE_ASCII. It will still work, because all unrecognized code will resolved into spaces.
0 | B00111111 | 48
1 | B00000110 | 49
2 | B01011011 | 50
3 | B01001111 | 51
4 | B01100110 | 52
5 | B01101101 | 53
6 | B01111101 | 54
7 | B00000111 | 55
8 | B01111111 | 56
9 | B01101111 | 57
ONLY_TOP_SEGMENT_FAKE_ASCII | B00000001 | 58 | Not an official ASCII character
ONLY_MIDDLE_SEGMENT_FAKE_ASCII | B01000000 | 59 | Not an official ASCII character
ONLY_BOTTOM_SEGMENT_FAKE_ASCII | B00001000 | 60 | Not an official ASCII character
ONLY_TOP_AND_BOTTOM_SEGMENT_FA KE_ASCII | B00001001 | 61 | Not an official ASCII character
SPACE_FAKE_ASCII | B00000000 | 62 | Not an official ASCII character
RANDOM | RANDOM | 63 | Not an official ASCII character, SPECIAL CASE, will randomly toggle one of the segment each time when assigned.
| B00000000 | 64
A | B01110111 | 65
B | B01111100 | 66
C | B00111001 | 67

D | B01011110 | 68
E | B01111001 | 69
F | B01110001 | 70
G | B00111101 | 71
H | B01110100 | 72
I | B00000110 | 73
J | B00001110 | 74
K | B01110101 | 75
L | B00111000 | 76
M | B01010101 | 77
N | B01010100 | 78
O | B01011100 | 79
P | B01110011 | 80
Q | B01100111 | 81
R | B01010000 | 82
S | B01101101 | 83
T | B01111000 | 84
U | B00011100 | 85
V | B00011110 | 86
W | B00011101 | 87
X | B00110110 | 88
Y | B01101110 | 89
Z | B00011011 | 90

### Memory types

Memory Type | Address range Decimal | Address range Hexadeci mal | Length [bytes] | Edita ble | Retains value when powered off | Function
Flash | 0..32255 | 0..7DFF | 32255 | NO | YES | This memory contains the main program code. It is

| | | | | | programmable to upload the firmware, but it cannot be changed from within the program.
Ram | 0..2047 | 0..7FF | 2048 | YES | NO | This fast memory is needed for the program to function
Eeprom | 0..1023 | 0..3FF | 1024 | YES | YES | This slow memory contains values the need to be preserved

### Luciebox eeprom layout

The flash and ram memory are organised beyond my control. But, the eeprom has 1024 bytes that can be programmed and will retain their value, even when the box is switched on and off again. It is strictly organised according to the schematic below.

Address range Decimal | Address range Hexadeci mal | Len gth [byt es] | function
0..7 | 0..7 | 8 | Settings | ● byte 0: Sound disabled ● byte 1..2: Power cycle counter (will only update if at least one of the momentary buttons is pressed after a switch on)
8.. 103 | 8..67 | 96 | Game high scores | each game has 6 levels. High score is 2 bytes (because I choose to believe in your abilities!) ● byte 0..11: Whack a mole ● byte 12..23: Whack a mole endurance mode ● byte 24..35: Whack a bird ● byte 36..47: Whack a bird endurance mode ● byte 48..59: Guitar Hero ● byte 60..71: Guitar Hero with stuttering ● byte 72..83: Hex Hero ● byte 84..95: Hex Hero with stuttering
104..109 | 68..6D | 6 | MultiTimer | ● byte 0: Number of enabled timers ● byte 1..4: Init timer per timer [seconds] ● byte 5: Fischer time [seconds]
110..112 | 6E..70 | 3 | Pomodoro | ● byte 0: Init time [seconds] ● byte 1: Pause time [seconds] ● byte 2: Random beep time [seconds]
113..240 | 71..F0 | 128 | Sequencer | 32 bytes per sequence * 4 sequences
241..640 | F1..280 | 400 | Composer songs | 100 bytes per song * 4 songs
641..1020 | 281..3FC | 380 | Sketch | 4 bytes per picture* 95 pictures

| | | saved Pictures
1021..1023 | 3FD..3FF | 3 | Free | Free space. All for you to store secret information, passwords, bitcoin passwords,...

# Practical

## Inactivity timer

Every hour since the last key press, the happy dryer song will play. Unless the Pomodoro Application or Multitimer is activated.

### Randomness

https://rheingoldheavy.com/better-arduino-random-values/
The random seed is done with the internal timer at each app initialization. So, at startup, as long as not app has been changed, the same values will show up for generated random event (rolling dice, sequencer generator, guitar hero sequence,...). It’s important that your sequence does not involve button presses, because, these cannot be timed. There is something fun about the idea of have the same randomness. For better randomness, make sure to change an app some time after startup of the box.

## Settings App

Button test and Luciebox settings.
Decimal points on display flicker erratically to indicate that the box is alive.
This is a simple buttons test app, that is very appealing to small kids as the behaviour is very predictable. All button presses have an instant effect!
Latching Button | Momentary Button | Dial | Functionality
0 | 1 | 2 | 3 | 0 | 1 | 2 | 3
1 | 1 | 1 | 1 | | | | | | Corresponding digit displays “-”
| | | | 1 | 1 | 1 | 1 | | Corresponding digit displays “0”
| | | | | | | | turn | Twist back and forth 3 times to activate the settings menu. Every consecutive twist will activate the next menu item.

### Settings Menu items

Dial twists | Menu item | Functionality
3 | Enable sound | With momentary 0, toggle the sound. This will be stored in the

| | retentive memory.
4 | A0 | The value of the selector dial. Stays at about 680. Cannot be changed.
5 | A1 | The value is an addition of pressed momentary buttons. Momentary_0:~64, momentary_1: ~128, momentary_2: ~256, momentary_3: ~512
6 | A2 | The value is an addition of pressed latching buttons. Latching_0:~64, Latching_1: ~128, Latching_2: ~256, Latching_3: ~512
7 | Firmware version | Have this number ready when contacting the helpdesk.
8 | QTY | Show the amount of times the Luciebox was switched on and at least one button was pressed.
9 | Reset | Press M0 and then M3 for game high scores reset Press M0 and then M2 for total reset (includes drawings, composed songs, high scores, sequencer songs)

# Troubleshooting

Problem | Comment
App sometimes restarts. Some apps show a blank screen. Some apps are missing. | The selector dial wiper might have a gap. Bad bad selector switch. With a small screwdriver, bend the wiper downward to eliminate the gap with the outer conducting circle.
Luciebox does not start up, or only for some seconds | Undervoltage, batteries empty.
I have no clue what to do. | Read this manual.
I can’t read yet | Vraag hulp aan een ouder of voogd.
Ik ken geen Engels | Vraag maar aan Omi, zij heeft Engelse les gevolgd!

# Todo and issues

## F302 Changes

Issue | Status

metronome:button3 hold: set sound also when metronome ON. Change flashing toggle to another button.

check if the MAX from random number (bingo) is indeed saved to eeprom once set…

in random mode: dial function: not working. : If latching_2 and latching_3 are off: Generate random values for last selected mode. (dial should be like next step)

Mode draw letters: would be fun to have the probability of drawn letter set to a certain language. English, Dutch,.... this way it can be used in word games. | memory for such a multi language endeavour for now. I could work if we put the probabilities per letter as byte in the eeprom. So, it can be changed in hack mode. Then, to pick a letter: make sum of all probabilities. Choose random number between zero and that total. In a for loop, add the probabilities again, if the chosen random number, is in an interval, that’s our number! aka: previous probability index when counting up. Of, just store the english letter frequencies in the ram. It’s not thaaaat
chronometer (or countdown timer?) Set animation, instead of numbers on screen, show hourglass on screen for countdown | we could use the screen fill animation.

No don’t do this. ok like it is. close issue

Done

done. Does it add value though?

done in flash Hmmm… not enough

different from dutch...

not done , not needed close

simon says multiplayer mode: do not let everybody do the sequence. Just one person. let random mode decide if it’s
just the next person, or a random person

OK done.

check pascal “No Simon” mode. | OK done
todo quizmaster app: dial sets score in quizmaster mode after question answered. → press all buttons to which a value is added or subtracted. hmm easier: dial changes value of player that pressed

multitimer: multiple timers, next player: not working!

enable random pause in hex hero | that’s silly. But, what we could do: complementary mode: whenever the decimal point is ON, the complement of the given number has to be provided

ok done

ugh, no problem. works! did you read the manual on how to use it ? Closed.

done

song composer: check if dial rotating with If momentary 1 reworked done or 2 is pressed, sets note.
song composer: hold down momentary0 and rotate dial will not assign notes while dialing

hack time: When the value changes in the memory, a confirmation beep will sound → NOPE

hacktime: representation of values as chars and binary looks like it’s not correct

inactivity timer

reworked done

solved.

done

done beep every X minutes.(30?) → one hour

# Remarks

# Power solutions

- Batteries: 4xAA → this is more like 6.5V when the batteries are new, but, the Luciebox can handle (thanks to a Schottky diode)
- USB Mini connected to a powerbank or a phone charger

# Firmware update

Check the firmware version in the settings app. An update or your own software can be uploaded.

## Background

The arduino platform is used. The arduino bootloader is loaded in the Microcontroller. Imagine the Luciebox as an Arduino UNO board without its microcontroller. When the wires are connected like in the table, programming the Luciebox is like uploading a program to any Arduino Uno board. Experimenting is encouraged.

## Upload firmware procedure

1. Have an arduino UNO board ready. These boards are available for very cheap on aliexpress.
2. Take an arduino uno board, and connect the wires like indicated in the table below. There is no need to modify the arduino uno board. (For serial output to work in debug mode (e.a. Serial.println()), the atmega328 needs to be removed from the original UNO).
3. Open the arduino IDE and load the Luciebox program.
4. Upload the program to the connected “arduino UNO”.
5. Disconnect the RX/ TX pins if the atmega328 is not removed from the UNO board.
6. Done. (you can leave the VCC and GND connected to save on batteries).

## Luciebox to Arduino UNO interface

Pin Arduino programmer | Pin Luciebox | Remarks
VCC | VCC | 5V DC
GND | GND | Ground
TX | TX | Luciebox to Computer
RX | RX | Computer to Luciebox
RESET | RESET | Pulled to GND during programming.

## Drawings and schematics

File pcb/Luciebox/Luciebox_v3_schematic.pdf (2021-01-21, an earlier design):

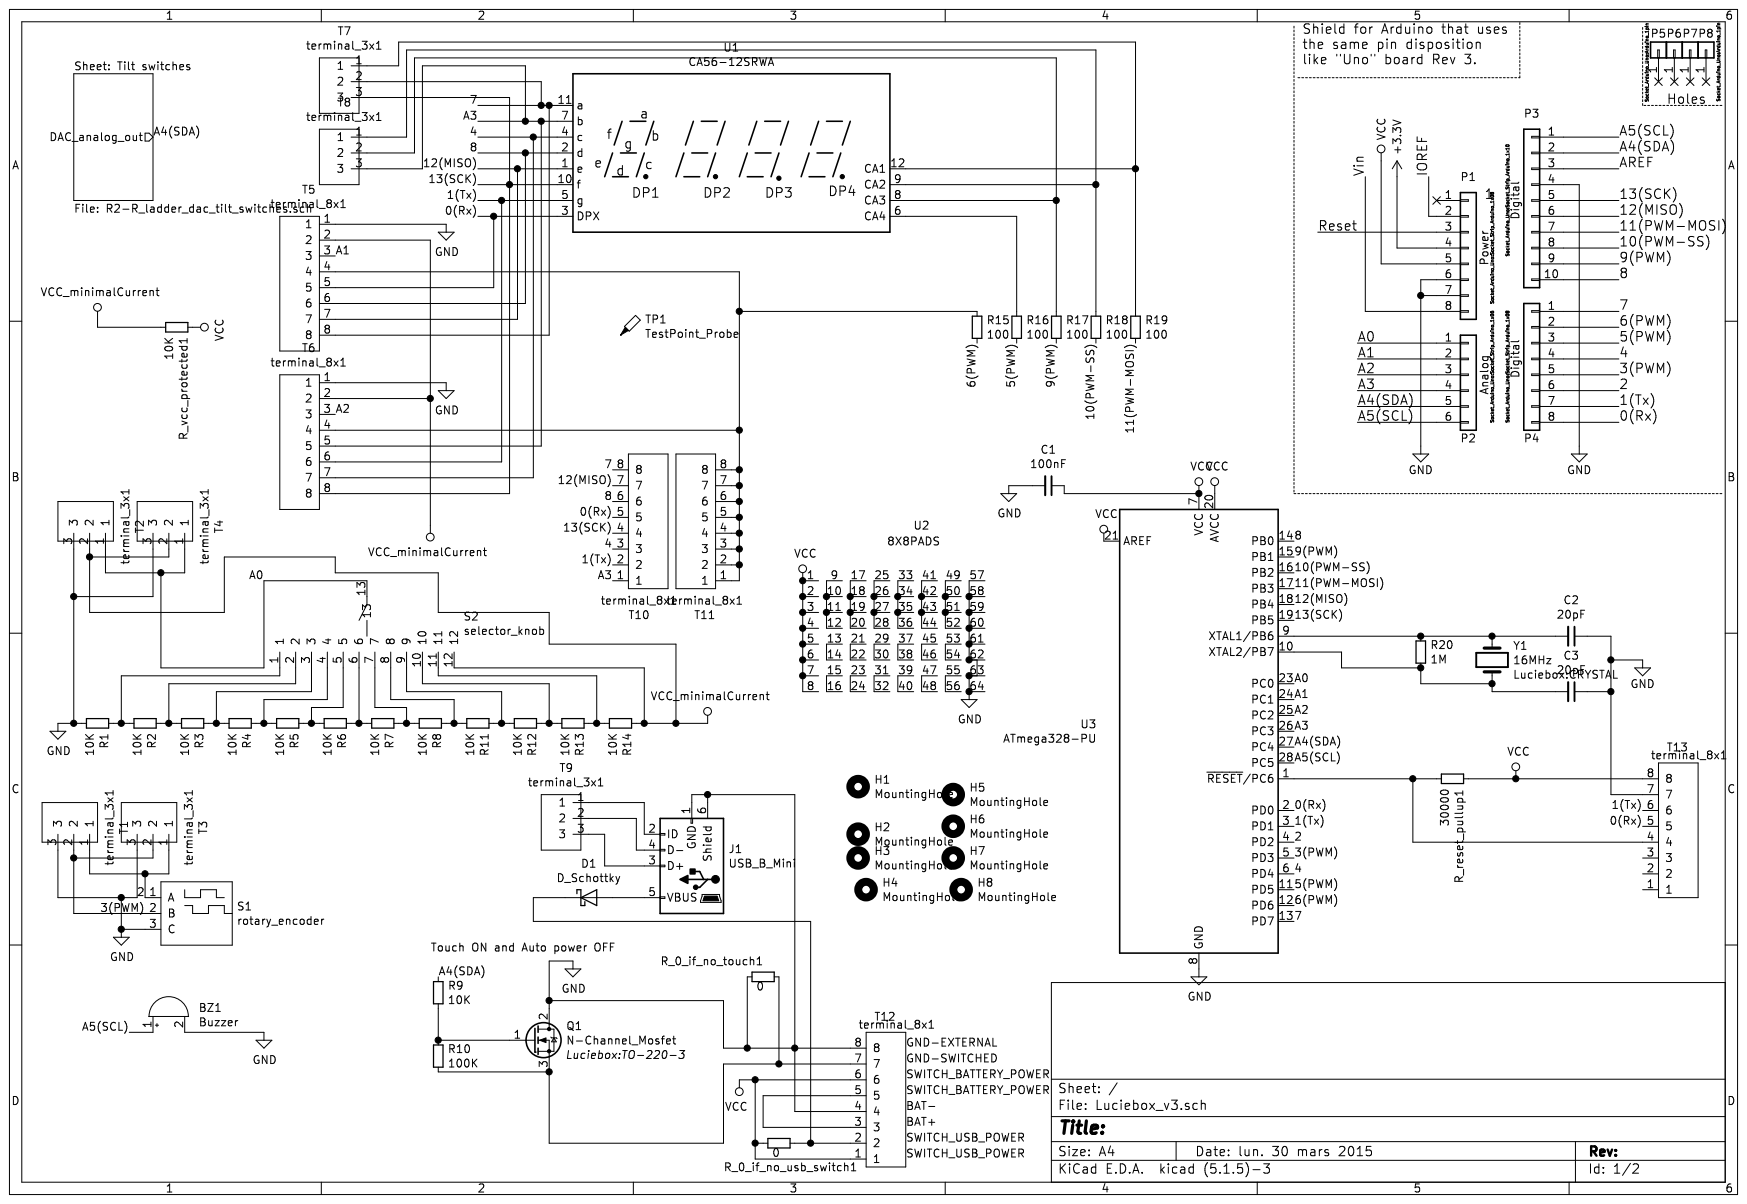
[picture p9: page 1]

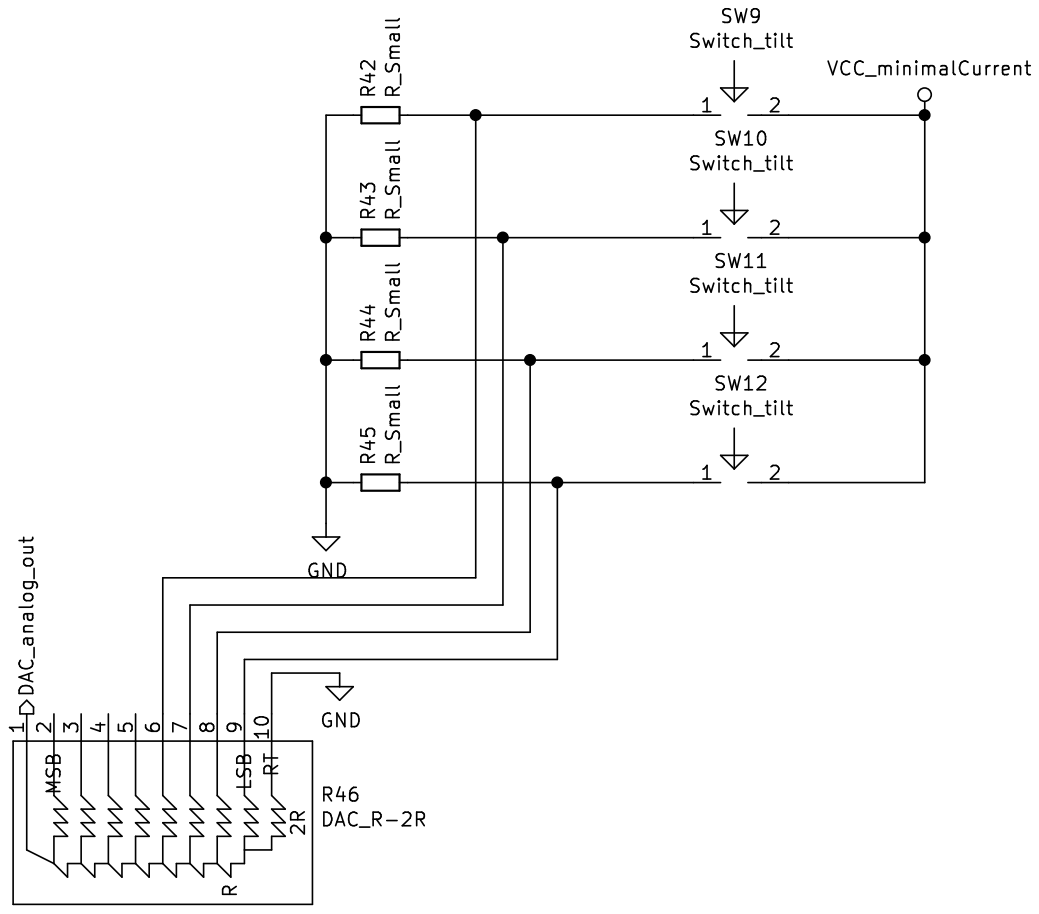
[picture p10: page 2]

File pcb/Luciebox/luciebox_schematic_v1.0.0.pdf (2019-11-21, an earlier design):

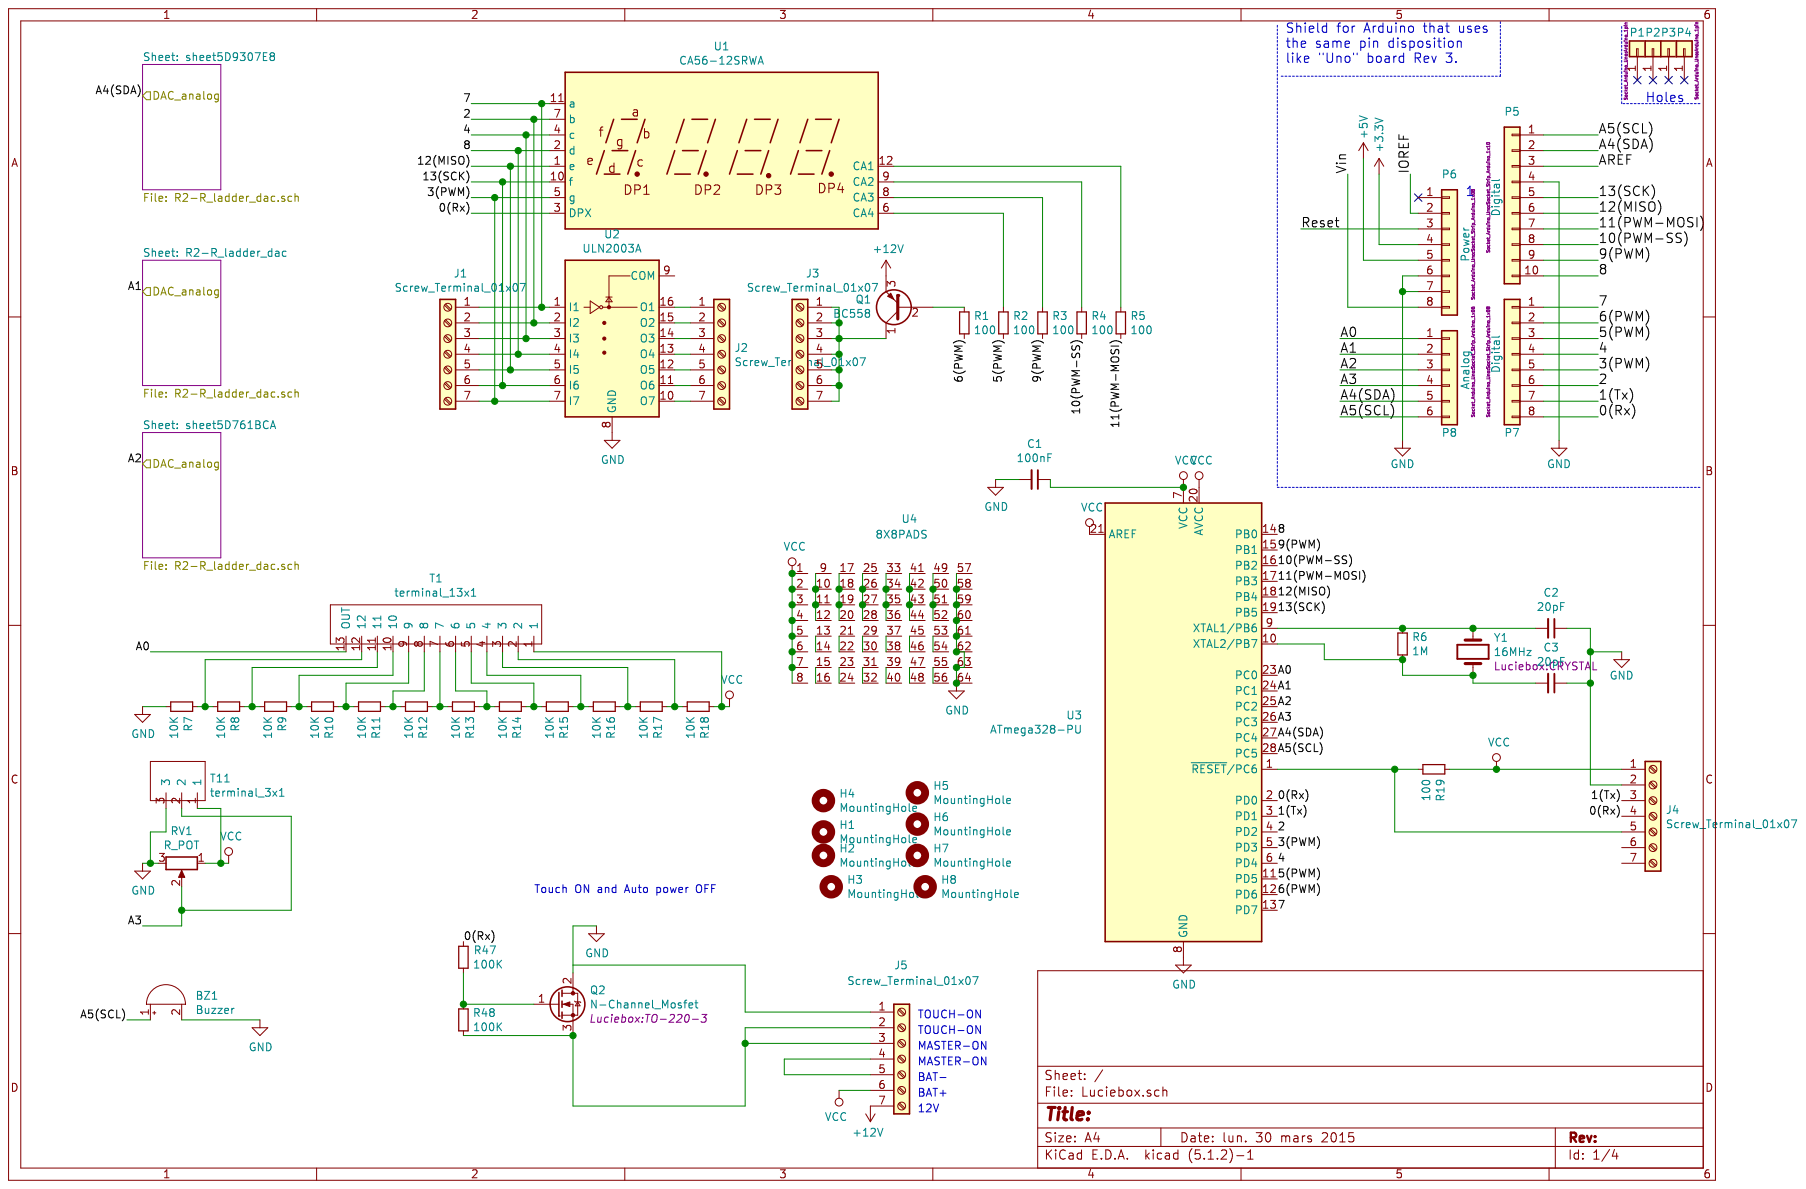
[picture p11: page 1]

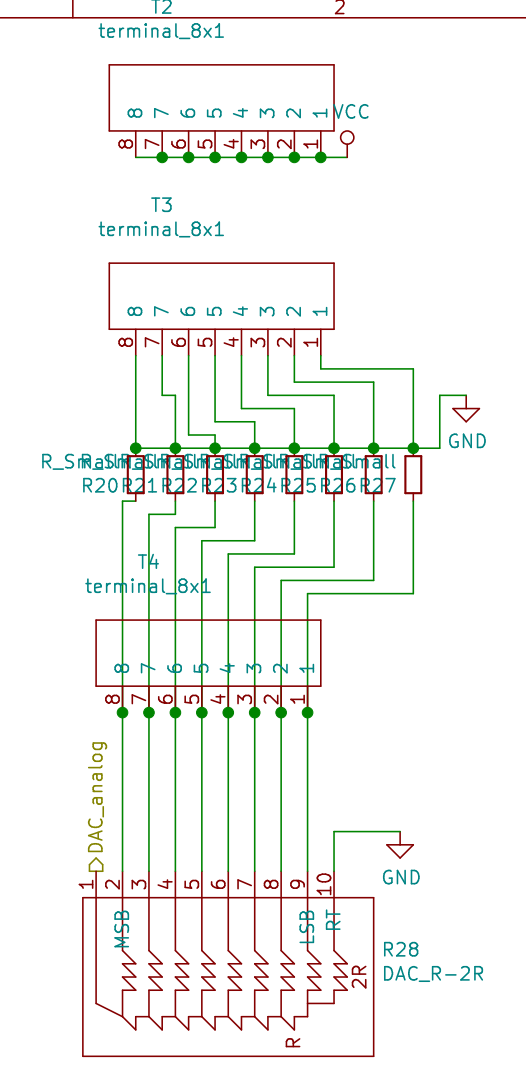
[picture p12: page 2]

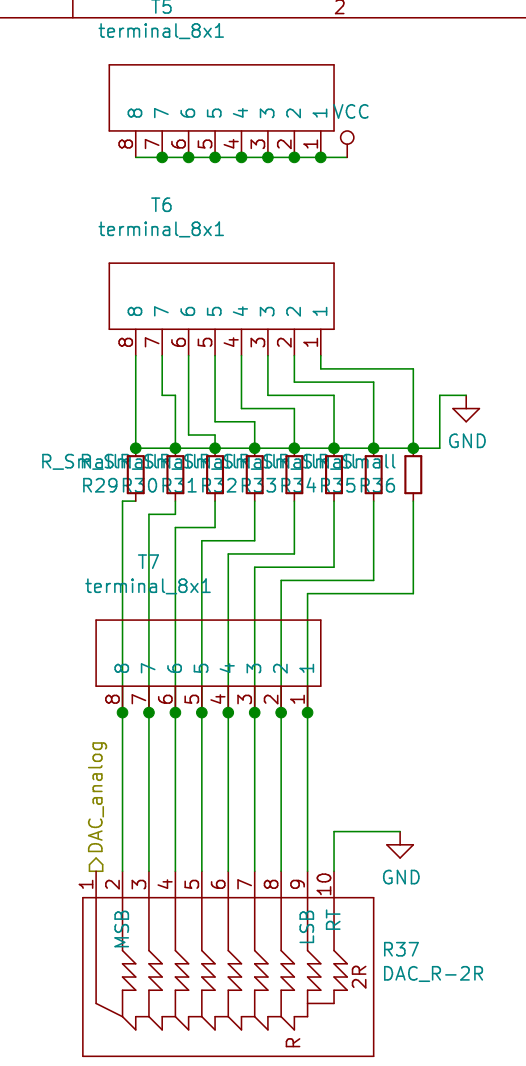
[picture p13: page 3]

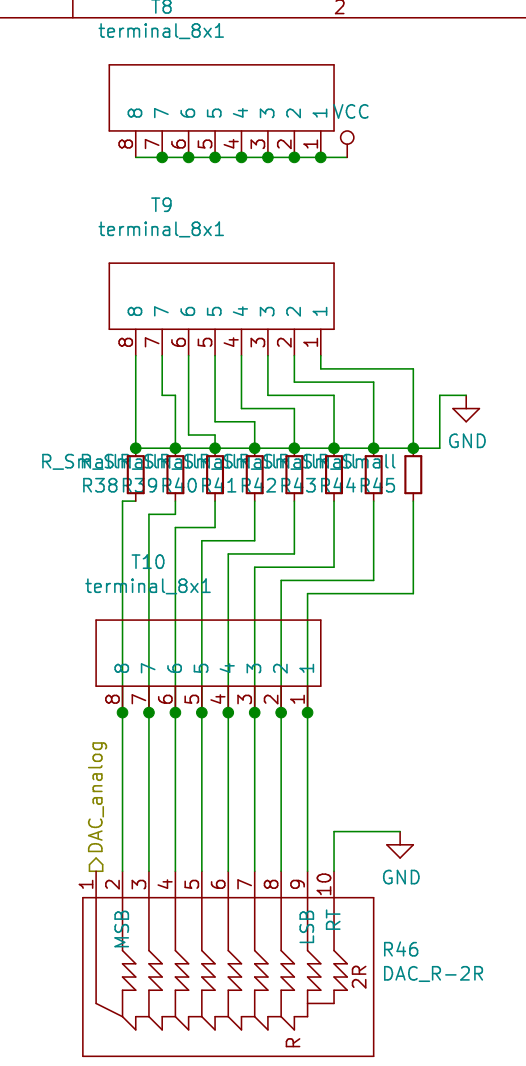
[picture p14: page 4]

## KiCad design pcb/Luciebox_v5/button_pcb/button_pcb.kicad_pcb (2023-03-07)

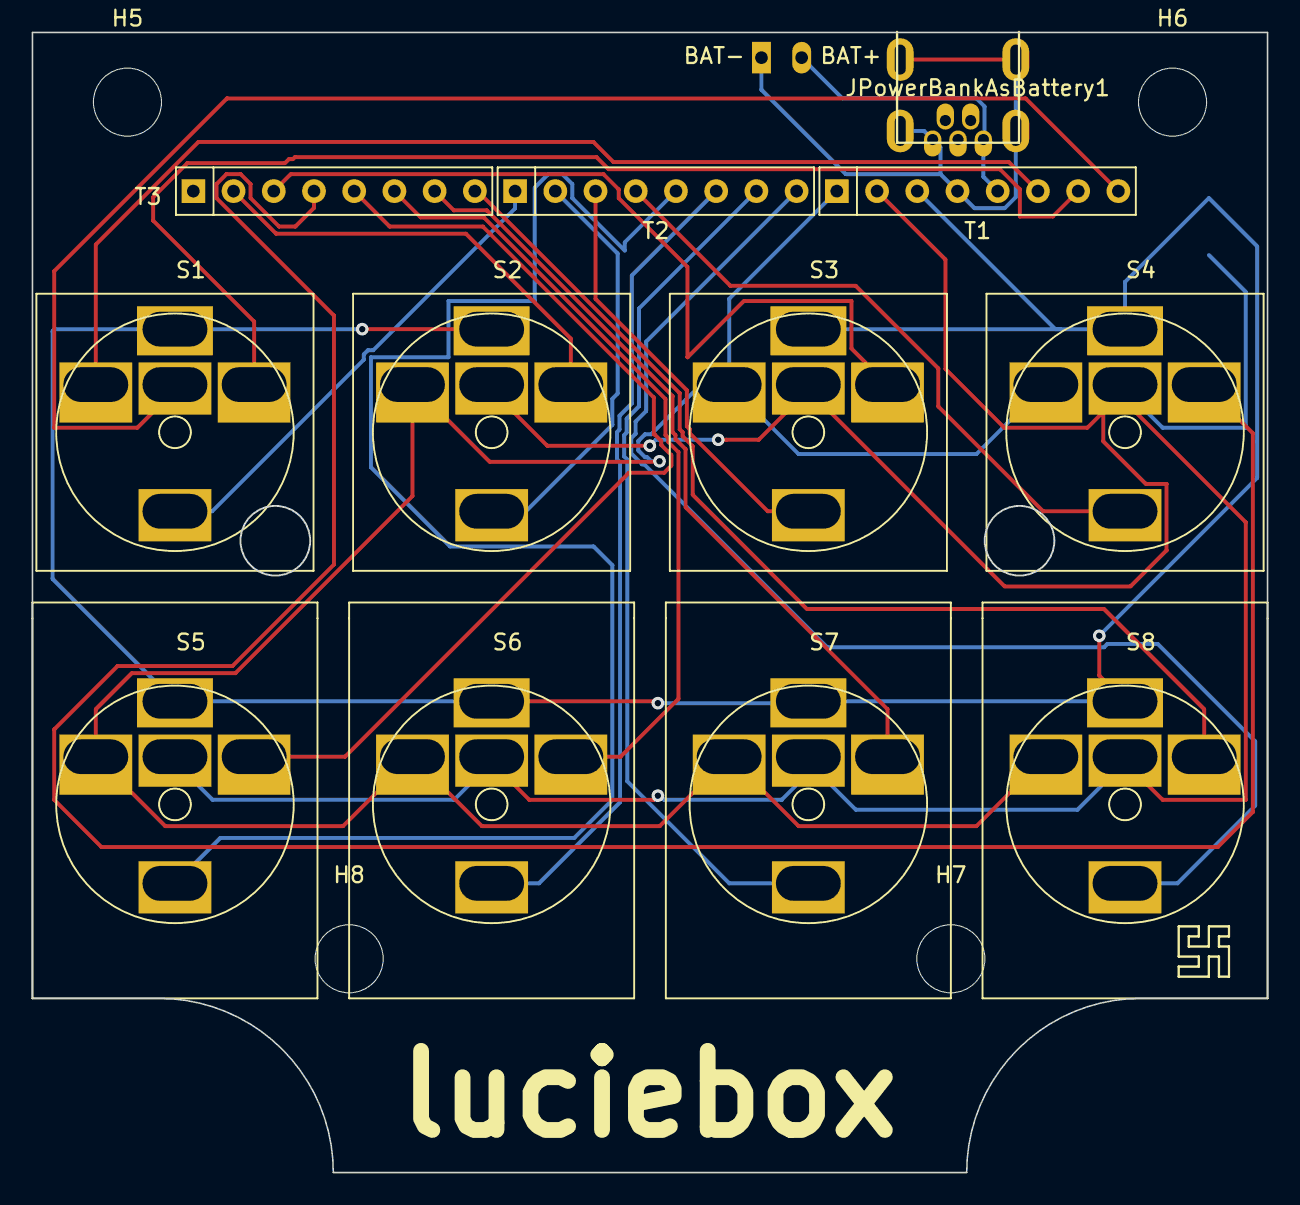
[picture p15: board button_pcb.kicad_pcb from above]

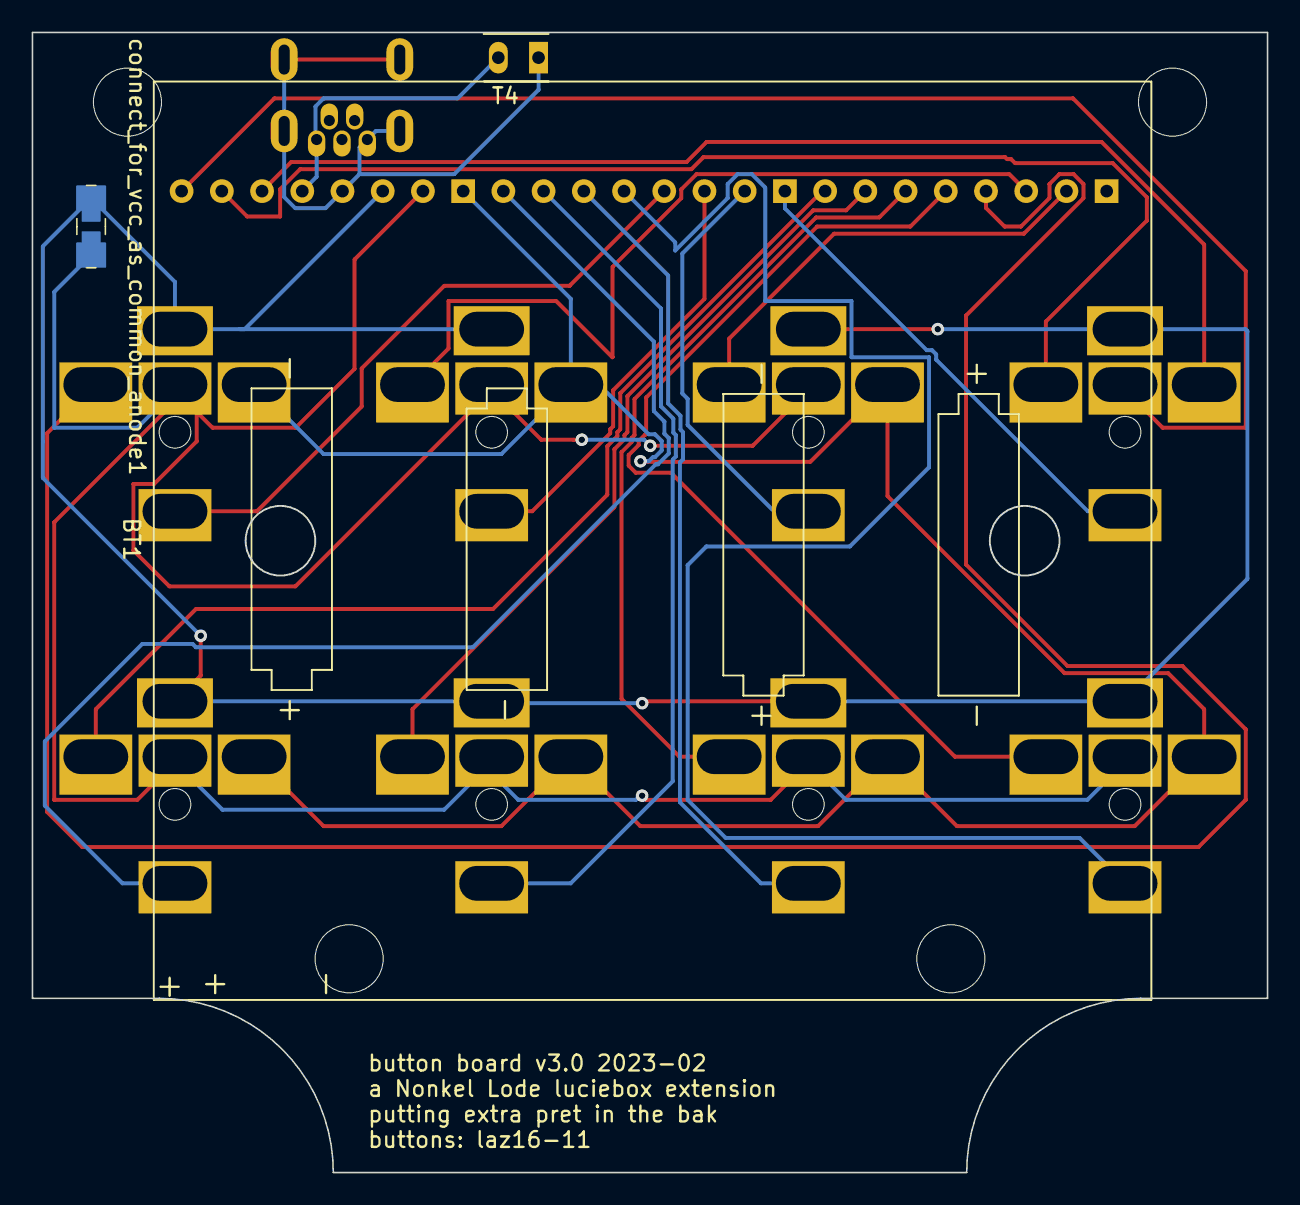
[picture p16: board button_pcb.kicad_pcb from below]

Board: 2 copper layers, 78.0 x 72.0 mm, 19 parts (3 on the bottom side), 23 nets.

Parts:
BT1: 4xAA_Battery_holder; BatteryHolder_4xAA
H5, H6, H7, H8: MountingHole; MountingHole_4.3mm_M4
JPowerBankAsBattery1: USB_B_Mini; usb_mini_Molex-0548190519
S1, S2, S3, S4: button_laz16-11; button_square_17.5x17.5mm_big_holes
S5, S6, S7, S8: button_laz16-11; button_LAZ16-11_big_holes
T1, T2, T3: terminal_8x1; Terminal_8x1_100mil
T4: terminal_2x1; Terminal_2x1_100mil
connect_for_vcc_as_common_anode1: R_Small; 1206_0805

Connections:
/common Anode: S1.4 (LED_+), S2.4 (LED_+), S3.4 (LED_+), S4.4 (LED_+), S5.4 (LED_+), S6.4 (LED_+), S7.4 (LED_+), S8.4 (LED_+), T1.3, connect_for_vcc_as_common_anode1.2
GND: S2.2 (NC), S3.2 (NC), S4.2 (NC), S5.2 (NC), S6.2 (NC), S7.2 (NC), S8.2 (NC), T1.1
unnamed: JPowerBankAsBattery1.5 (VBUS), T1.5, T4.2
unnamed: JPowerBankAsBattery1.1 (GND), JPowerBankAsBattery1.6 (Shield), T1.4, T4.1
unnamed: S1.1 (NO), T1.8
unnamed: S1.2 (NC), T1.6
unnamed: S1.3 (C), T1.7
unnamed: S1.5 (LED_-), T2.1
unnamed: S2.3 (C), T3.2
unnamed: S2.5 (LED_-), T2.2
unnamed: S3.3 (C), T3.3
unnamed: S3.5 (LED_-), T2.3
unnamed: S4.3 (C), T3.4
unnamed: S4.5 (LED_-), T2.4
unnamed: S5.3 (C), T3.5
unnamed: S5.5 (LED_-), T2.5
unnamed: S6.3 (C), T3.6
unnamed: S6.5 (LED_-), T2.6
unnamed: S7.3 (C), T3.7
unnamed: S7.5 (LED_-), T2.7
unnamed: S8.3 (C), T3.8
unnamed: S8.5 (LED_-), T2.8
VCC: S2.1 (NO), S3.1 (NO), S4.1 (NO), S5.1 (NO), S6.1 (NO), S7.1 (NO), S8.1 (NO), T1.2, connect_for_vcc_as_common_anode1.1

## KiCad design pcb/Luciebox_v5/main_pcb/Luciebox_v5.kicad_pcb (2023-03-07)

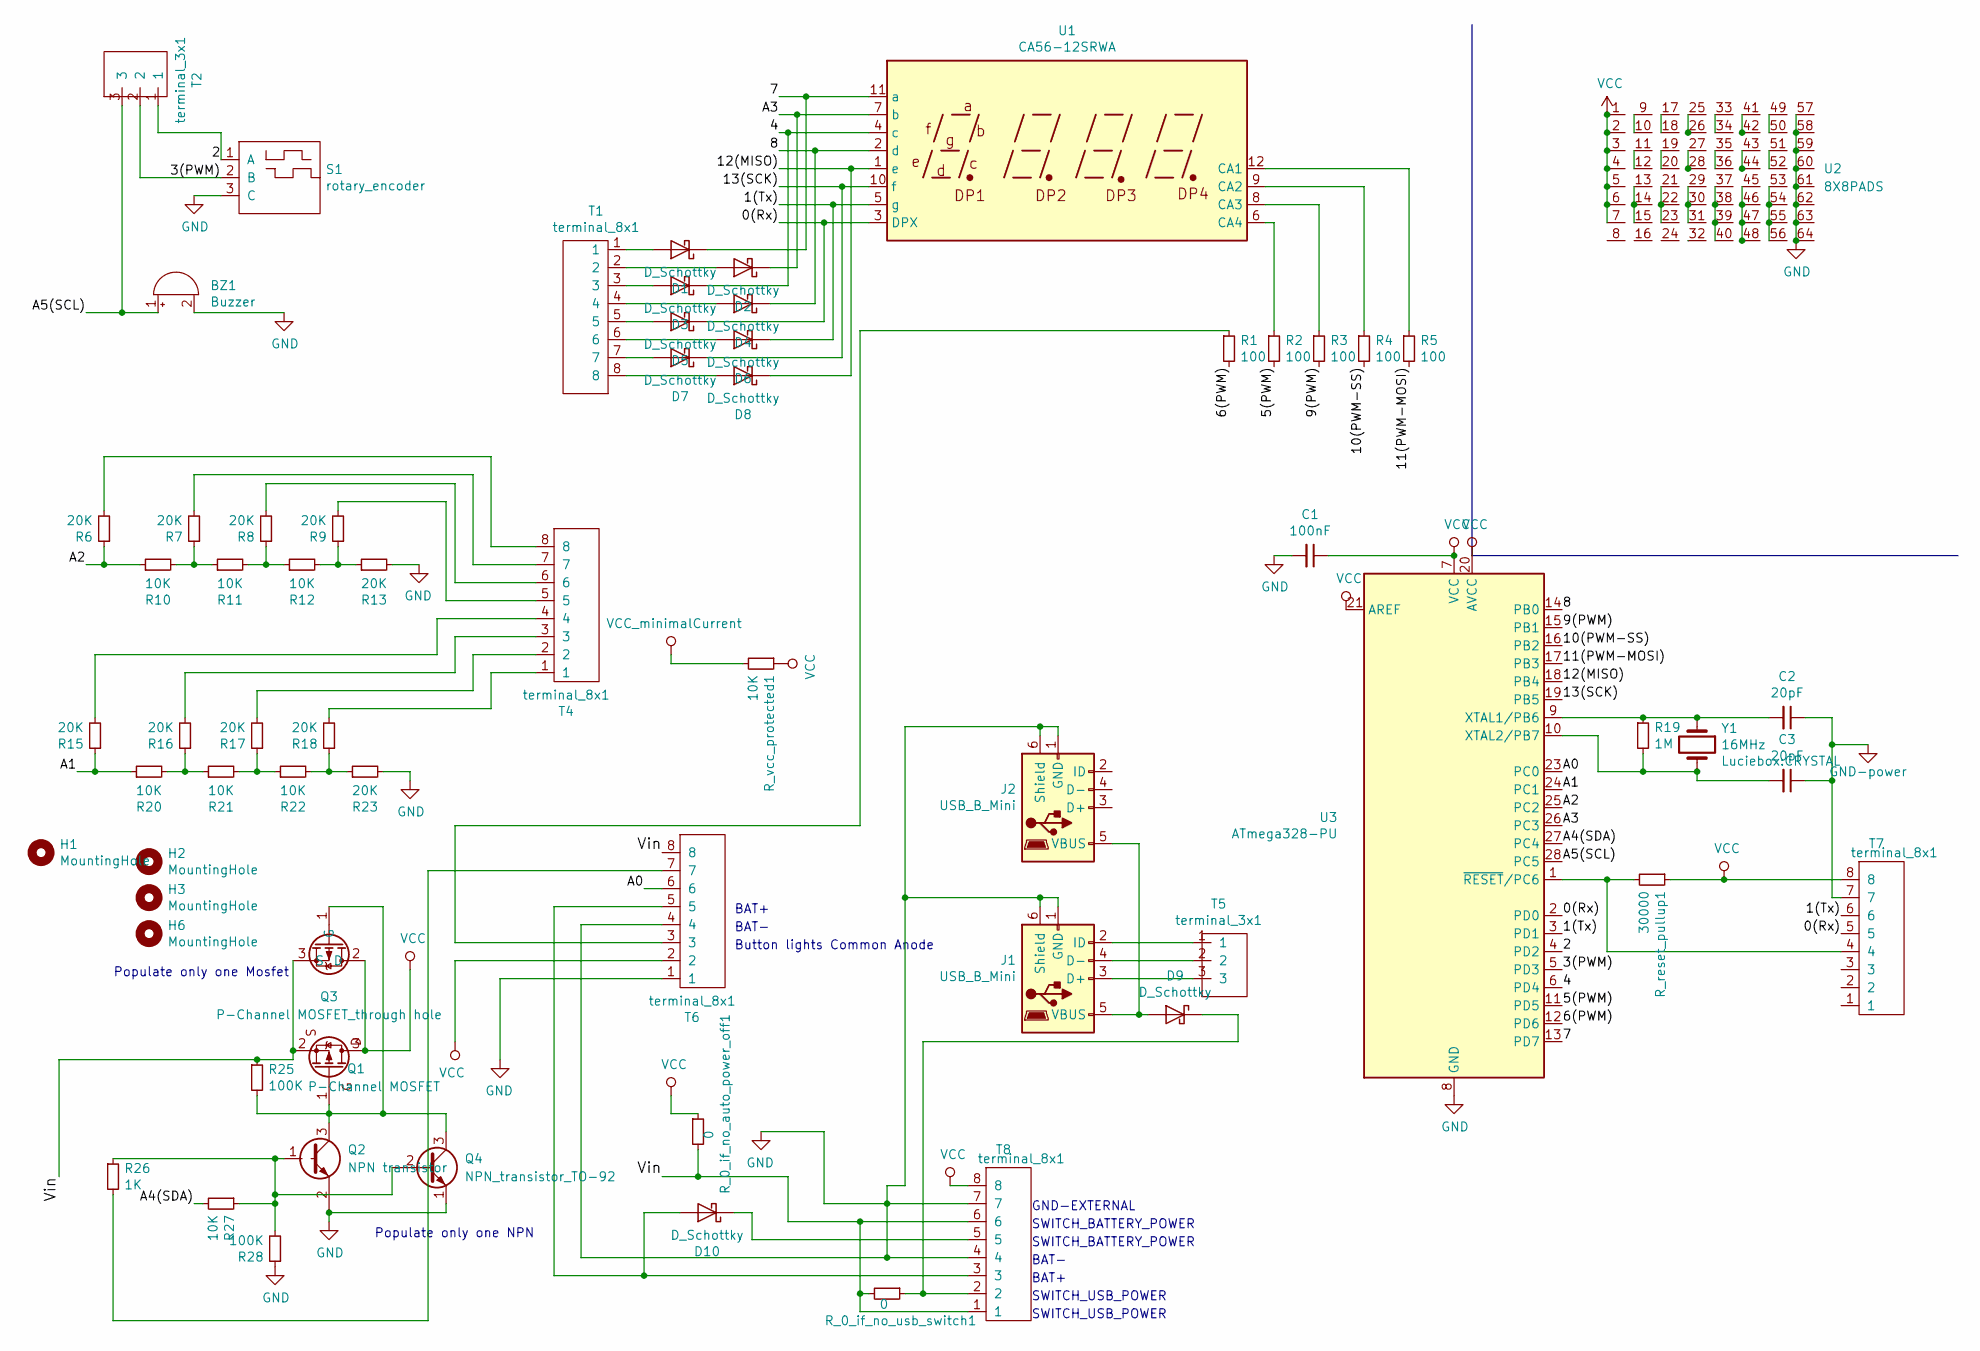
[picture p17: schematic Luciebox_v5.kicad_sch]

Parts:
BZ1: Buzzer; buzzer
C1: 100nF; 0603_1608Metric
C2, C3: 20pF; 0603_1608Metric
D1, D2, D3, D4, D5, D6, D7, D8, D9, D10: D_Schottky; D_SMA
H1, H2, H3, H6: MountingHole; MountingHole_4.3mm_M4
J1, J2: USB_B_Mini; usb_mini_Molex-0548190519
Q1: P-Channel MOSFET; SOT-23
Q2: NPN transistor; SOT-23
Q3: P-Channel MOSFET_through hole; TO-218-3_Vertical
Q4: NPN_transistor_TO-92; TO-92
R1, R2, R3, R4, R5: 100; 0603_1608Metric
R6, R7, R8, R9, R13, R15, R16, R17, R18, R23: 20K; 0603_1608Metric
R10, R11, R12, R20, R21, R22, R27: 10K; 0603_1608Metric
R19: 1M; 0603_1608Metric
R25, R28: 100K; 0603_1608Metric
R26: 1K; 0603_1608Metric
R_0_if_no_auto_power_off1, R_0_if_no_usb_switch1: 0; 0603_1608Metric
R_reset_pullup1: 30000; 0603_1608Metric
R_vcc_protected1: 10K; 0603_1608Metric
S1: rotary_encoder
T1, T4, T6, T7, T8: terminal_8x1; Terminal_8x1_100mil
T2, T5: terminal_3x1; Terminal_3x1_100mil
U1: CA56-12SRWA
U2: 8X8PADS; 8X8PADS_100mil
U3: ATmega328-PU; DIP-28_W7.62mm
Y1: 16MHz; CRYSTAL

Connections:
/0(Rx): D5.1 (K), T7.5, U1.3 (DPX), U3.2 (PD0)
/1(Tx): D6.1 (K), T7.6, U1.5 (g), U3.3 (PD1)
/2: S1.1 (A), T2.1, U3.4 (PD2)
/3(PWM): S1.2 (B), T2.2, U3.5 (PD3)
/4: D3.1 (K), U1.4 (c), U3.6 (PD4)
/5(PWM): R2.2, U3.11 (PD5)
/6(PWM): R1.2, U3.12 (PD6)
/7: D1.1 (K), U1.11 (a), U3.13 (PD7)
/8: D4.1 (K), U1.2 (d), U3.14 (PB0)
/9(PWM): R3.2, U3.15 (PB1)
/10(PWM-SS): R4.2, U3.16 (PB2)
/11(PWM-MOSI): R5.2, U3.17 (PB3)
/12(MISO): D8.1 (K), U1.1 (e), U3.18 (PB4)
/13(SCK): D7.1 (K), U1.10 (f), U3.19 (PB5)
/A0: T6.6, U3.23 (PC0)
/A1: R15.1, R20.1, U3.24 (PC1)
/A2: R6.1, R10.1, U3.25 (PC2)
/A3: D2.1 (K), U1.7 (b), U3.26 (PC3)
/A4(SDA): R27.2, U3.27 (PC4)
/A5(SCL): BZ1.1 (-), T2.3, U3.28 (PC5)
/Vin: Q1.2 (S), Q3.3 (S), R25.1, R_0_if_no_auto_power_off1.2, R_0_if_no_usb_switch1.2, T6.8, T8.1, T8.6
unnamed: C2.2, R19.1, U3.9 (XTAL1/PB6), Y1.1
unnamed: C3.2, R19.2, U3.10 (XTAL2/PB7), Y1.2
unnamed: D1.2 (A), T1.1
unnamed: D2.2 (A), T1.2
unnamed: D3.2 (A), T1.3
unnamed: D4.2 (A), T1.4
unnamed: D5.2 (A), T1.5
unnamed: D6.2 (A), T1.6
unnamed: D7.2 (A), T1.7
unnamed: D8.2 (A), T1.8
unnamed: D9.1 (K), R_0_if_no_usb_switch1.1, T8.2
unnamed: D9.2 (A), J1.5 (VBUS), J2.5 (VBUS)
unnamed: D10.1 (K), T8.5
unnamed: D10.2 (A), T6.5, T8.3
unnamed: J1.2 (ID), T5.1
unnamed: J1.3 (D+), T5.3
unnamed: J1.4 (D-), T5.2
unnamed: Q1.1 (G), Q2.3 (E), Q3.1 (G), Q4.3 (E), R25.2
unnamed: Q2.1 (C), Q4.2 (B), R26.1, R27.1, R28.2
unnamed: R1.1, T6.3
unnamed: R2.1, U1.6 (CA4)
unnamed: R3.1, U1.8 (CA3)
unnamed: R4.1, U1.9 (CA2)
unnamed: R5.1, U1.12 (CA1)
unnamed: R6.2, T4.8
unnamed: R7.2, T4.7
unnamed: R8.2, T4.6
unnamed: R9.2, T4.5
unnamed: R7.1, R10.2, R11.1
unnamed: R8.1, R11.2, R12.1
unnamed: R9.1, R12.2, R13.1
unnamed: R15.2, T4.4
unnamed: R16.1, R20.2, R21.1
unnamed: R16.2, T4.3
unnamed: R17.1, R21.2, R22.1
unnamed: R17.2, T4.2
unnamed: R18.1, R22.2, R23.1
unnamed: R18.2, T4.1
unnamed: R26.2, T6.7
unnamed: R_reset_pullup1.2, T7.4, U3.1 (~RESET/PC6)
unnamed: U2.9, U2.10
unnamed: U2.11, U2.12
unnamed: U2.13, U2.14, U2.15
unnamed: U2.17, U2.18
unnamed: U2.19, U2.20
unnamed: U2.21, U2.22, U2.23
unnamed: U2.25, U2.26
unnamed: U2.27, U2.28
unnamed: U2.29, U2.30, U2.31
unnamed: U2.33, U2.34
unnamed: U2.35, U2.36
unnamed: U2.37, U2.38, U2.39, U2.40
unnamed: U2.41, U2.42
unnamed: U2.43, U2.44
unnamed: U2.45, U2.46, U2.47, U2.48
unnamed: U2.49, U2.50
unnamed: U2.51, U2.52
unnamed: U2.53, U2.54, U2.55, U2.56
VCC: C1.1, Q1.3 (D), Q3.2 (D), R_0_if_no_auto_power_off1.1, R_reset_pullup1.1, R_vcc_protected1.1, T6.2, T7.8, T8.8, U2.1, U2.2, U2.3, U2.4, U2.5, U2.6, U2.7, U3.7 (VCC), U3.20 (AVCC), U3.21 (AREF)
VCC_minimalCurrent: R_vcc_protected1.2

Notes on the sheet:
GND-EXTERNAL
BAT-
Populate only one NPN
BAT+
SWITCH_BATTERY_POWER
SWITCH_USB_POWER
Populate only one Mosfet
Button lights Common Anode

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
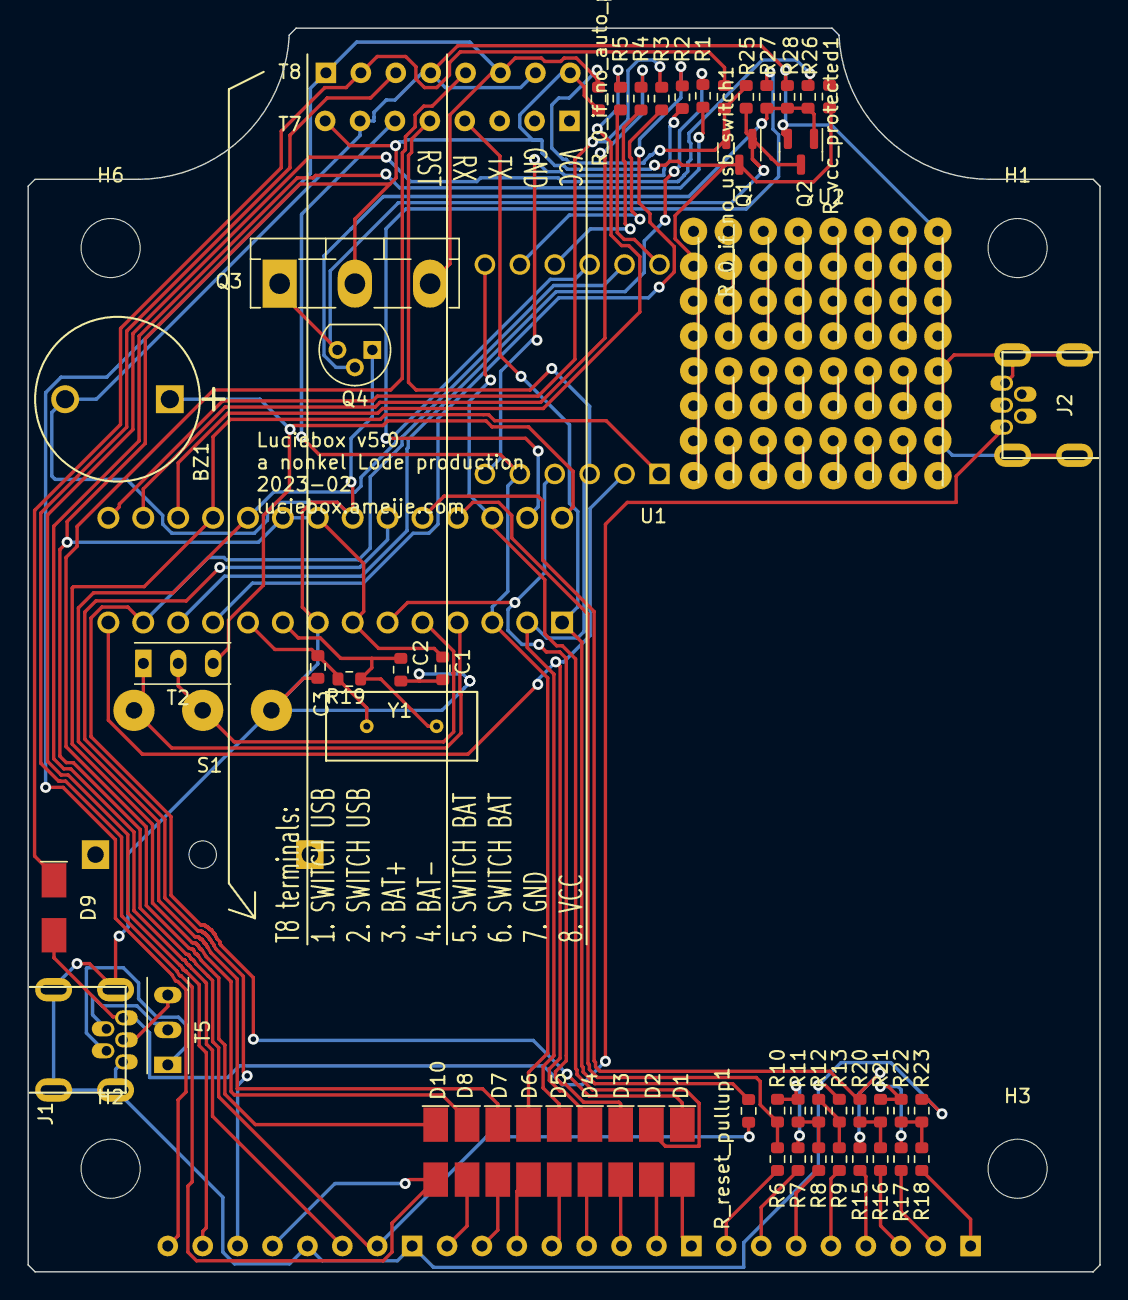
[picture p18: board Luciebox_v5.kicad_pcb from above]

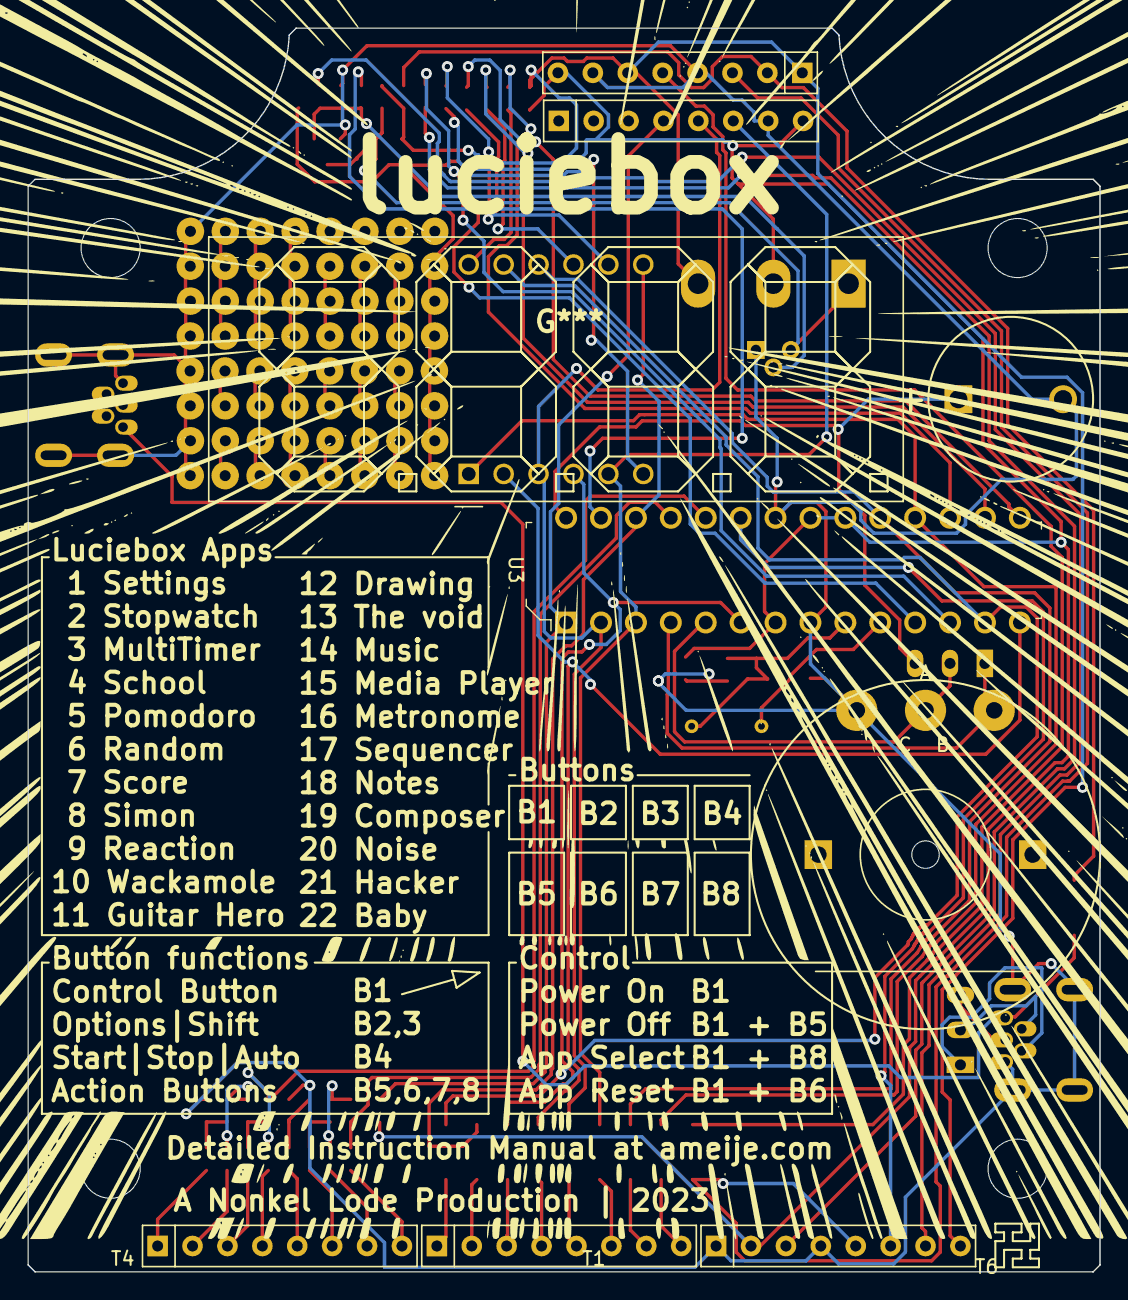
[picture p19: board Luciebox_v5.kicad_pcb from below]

Board: 2 copper layers, 78.0 x 90.5 mm, 66 parts (9 on the bottom side), 81 nets.

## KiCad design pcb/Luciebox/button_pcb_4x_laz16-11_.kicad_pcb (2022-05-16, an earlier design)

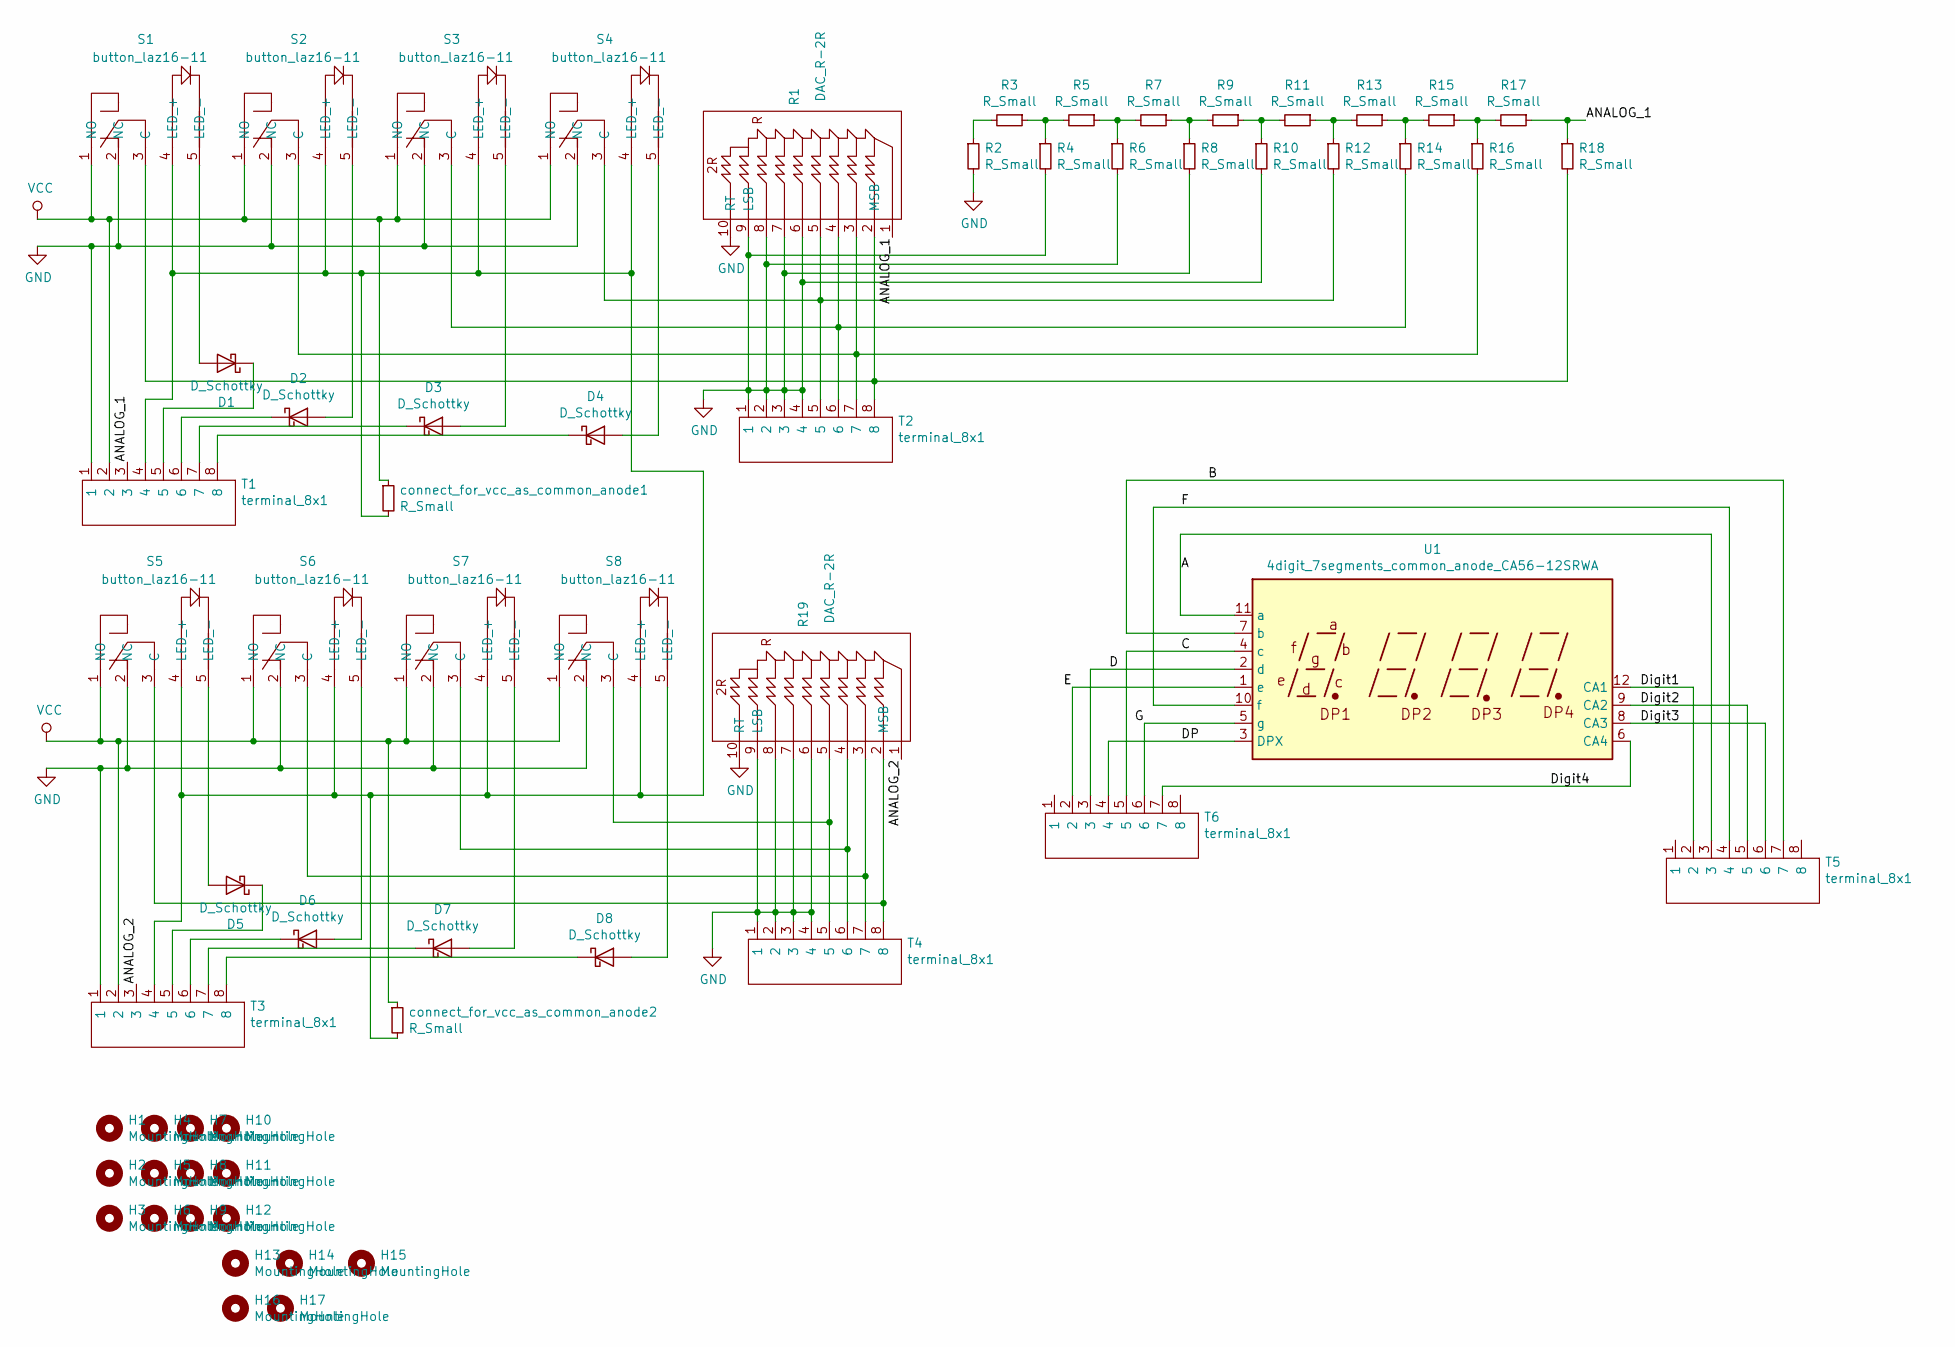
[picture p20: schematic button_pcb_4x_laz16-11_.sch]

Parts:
D1, D2, D3, D4, D5, D6, D7, D8: D_Schottky; smd_throughhole_2_pins
H1, H2, H3, H4, H5, H6, H7, H8, H9, H10, H11, H12, H13, H14, H15, H16, H17: MountingHole; MountingHole_4.3mm_M4
R1, R19: DAC_R-2R; SIP-10
R2, R3, R4, R5, R6, R7, R8, R9, R10, R11, R12, R13, R14, R15, R16, R17, R18: R_Small; 1206_0805
S1, S2, S3, S4, S5, S6, S7, S8: button_laz16-11; button_LAZ16-11
T1, T2, T3, T4, T5, T6: terminal_8x1; Terminal_8x1_100mil
U1: 4digit_7segments_common_anode_CA56-12SRWA; CA56-12SRWA
connect_for_vcc_as_common_anode1, connect_for_vcc_as_common_anode2: R_Small; 1206_0805

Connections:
/A: T5.3, U1.11 (a)
/ANALOG_1: R1.1, R17.1, R18.1, T1.3
/ANALOG_2: R19.1, T3.3
/B: T5.7, U1.7 (b)
/C: T6.5, U1.4 (c)
/D: T6.3, U1.2 (d)
/DP: T6.4, U1.3 (DPX)
/Digit1: T5.2, U1.12 (CA1)
/Digit2: T5.5, U1.9 (CA2)
/Digit3: T5.6, U1.8 (CA3)
/Digit4: T6.7, U1.6 (CA4)
/E: T6.2, U1.1 (e)
/F: T5.4, U1.10 (f)
/G: T6.6, U1.5 (g)
GND: R1.6, R1.7, R1.8, R1.9 (LSB), R1.10 (RT), R2.2, R4.2, R6.2, R8.2, R10.2, R19.6, R19.7, R19.8, R19.9 (LSB), R19.10 (RT), S1.2 (NC), S2.2 (NC), S3.2 (NC), S4.2 (NC), S5.2 (NC), S6.2 (NC), S7.2 (NC), S8.2 (NC), T1.1, T2.1, T2.2, T2.3, T2.4, T3.1, T4.1, T4.2, T4.3, T4.4
unnamed: D1.1 (K), T1.5
unnamed: D1.2 (A), S1.5 (LED_-)
unnamed: D2.1 (K), T1.6
unnamed: D2.2 (A), S2.5 (LED_-)
unnamed: D3.1 (K), T1.7
unnamed: D3.2 (A), S3.5 (LED_-)
unnamed: D4.1 (K), T1.8
unnamed: D4.2 (A), S4.5 (LED_-)
unnamed: D5.1 (K), T3.5
unnamed: D5.2 (A), S5.5 (LED_-)
unnamed: D6.1 (K), T3.6
unnamed: D6.2 (A), S6.5 (LED_-)
unnamed: D7.1 (K), T3.7
unnamed: D7.2 (A), S7.5 (LED_-)
unnamed: D8.1 (K), T3.8
unnamed: D8.2 (A), S8.5 (LED_-)
unnamed: R1.2 (MSB), R18.2, S1.3 (C), T2.8
unnamed: R1.3, R16.2, S2.3 (C), T2.7
unnamed: R1.4, R14.2, S3.3 (C), T2.6
unnamed: R1.5, R12.2, S4.3 (C), T2.5
unnamed: R2.1, R3.2
unnamed: R3.1, R4.1, R5.2
unnamed: R5.1, R6.1, R7.2
unnamed: R7.1, R8.1, R9.2
unnamed: R9.1, R10.1, R11.2
unnamed: R11.1, R12.1, R13.2
unnamed: R13.1, R14.1, R15.2
unnamed: R15.1, R16.1, R17.2
unnamed: R19.2 (MSB), S5.3 (C), T4.8
unnamed: R19.3, S6.3 (C), T4.7
unnamed: R19.4, S7.3 (C), T4.6
unnamed: R19.5, S8.3 (C), T4.5
unnamed: S1.4 (LED_+), S2.4 (LED_+), S3.4 (LED_+), S4.4 (LED_+), S5.4 (LED_+), S6.4 (LED_+), S7.4 (LED_+), S8.4 (LED_+), T1.4, T3.4, connect_for_vcc_as_common_anode1.2, connect_for_vcc_as_common_anode2.2
VCC: S1.1 (NO), S2.1 (NO), S3.1 (NO), S4.1 (NO), S5.1 (NO), S6.1 (NO), S7.1 (NO), S8.1 (NO), T1.2, T3.2, connect_for_vcc_as_common_anode1.1, connect_for_vcc_as_common_anode2.1

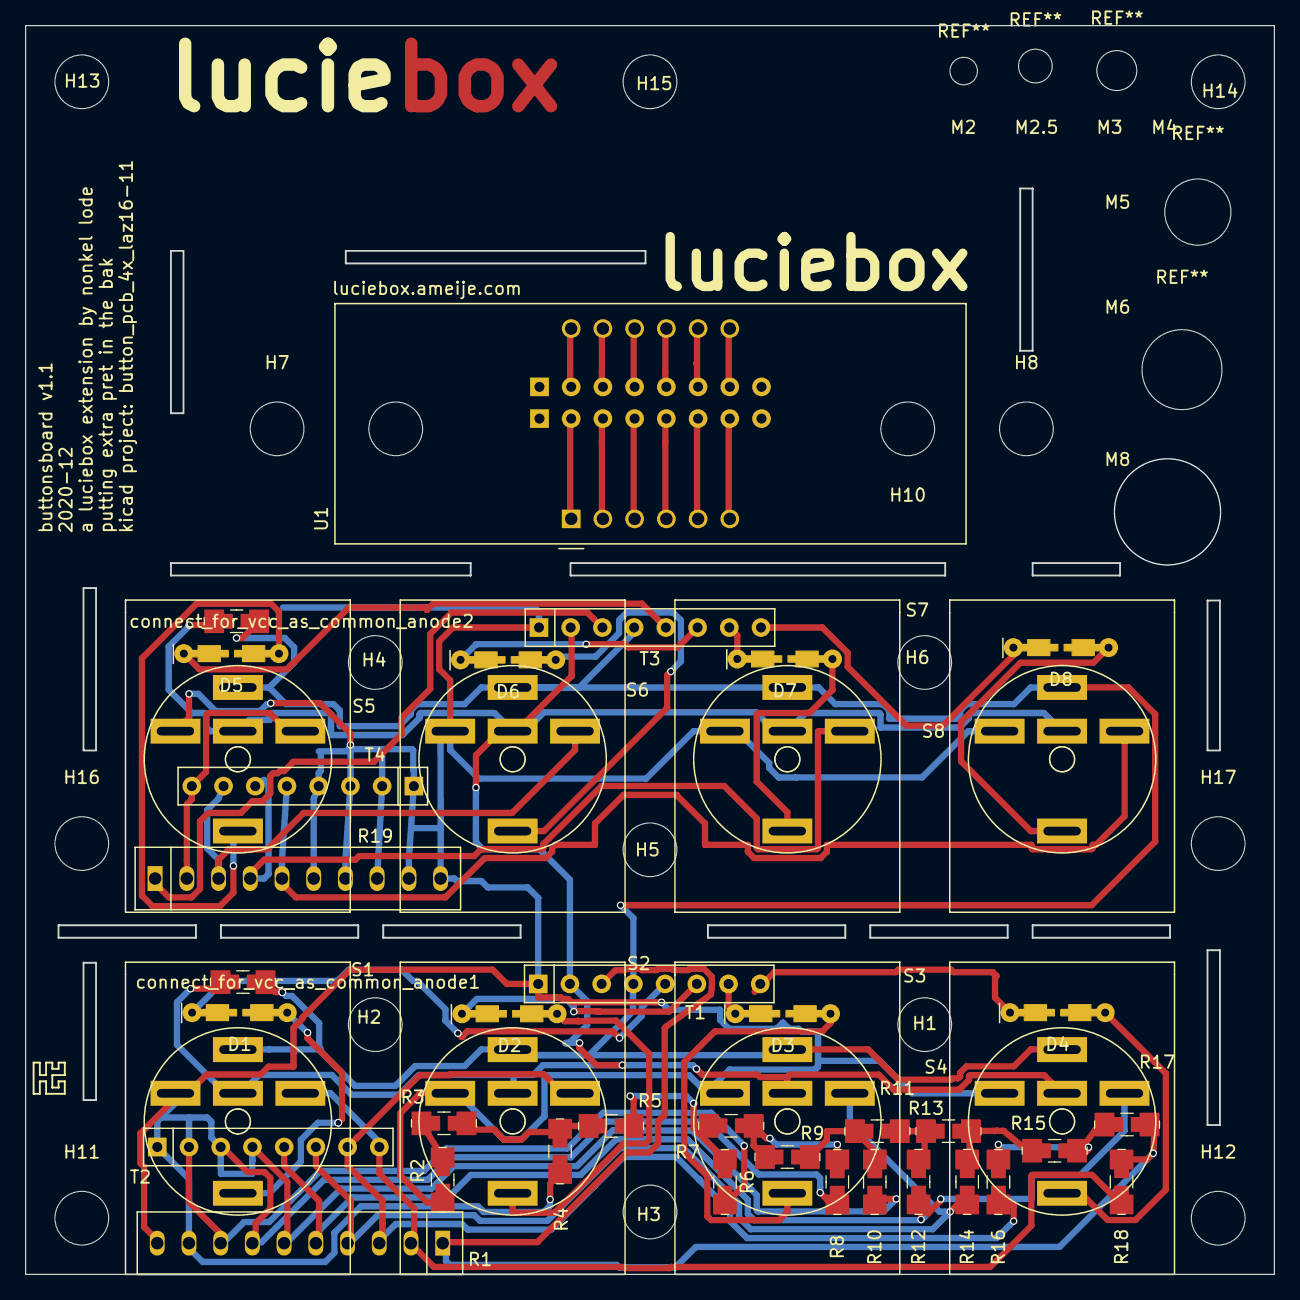
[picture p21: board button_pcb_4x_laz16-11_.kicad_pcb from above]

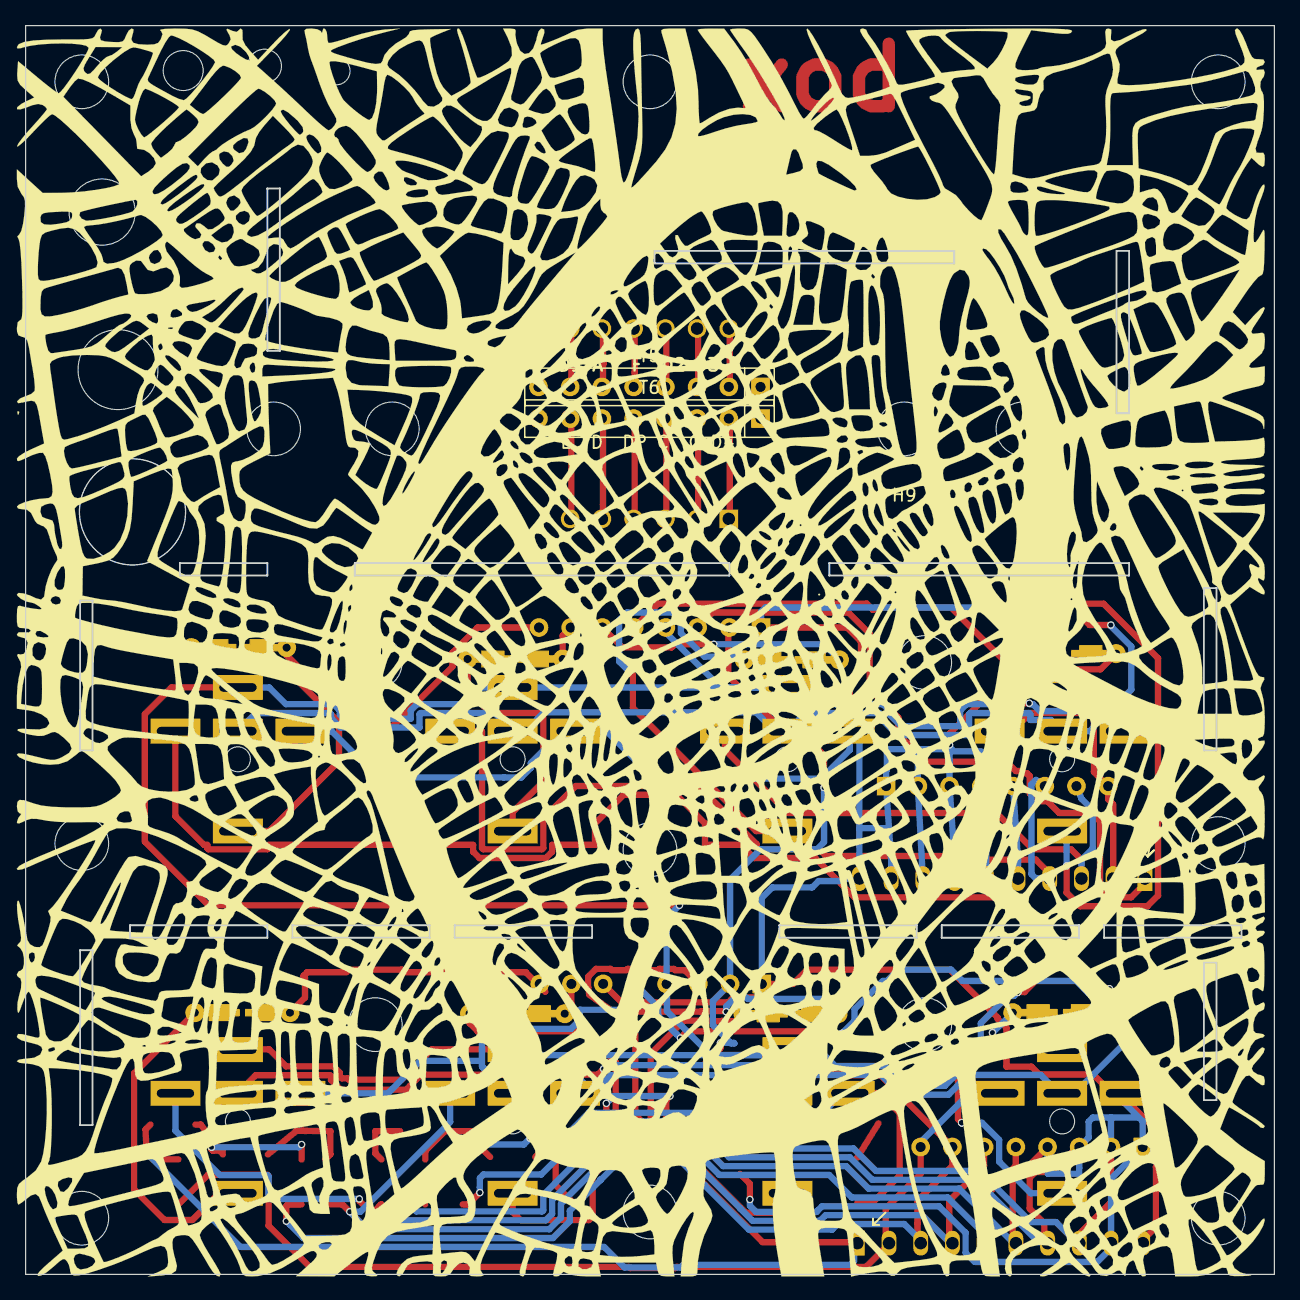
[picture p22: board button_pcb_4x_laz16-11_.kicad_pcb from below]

Board: 2 copper layers, 100.0 x 100.0 mm, 61 parts (4 on the bottom side), 49 nets.

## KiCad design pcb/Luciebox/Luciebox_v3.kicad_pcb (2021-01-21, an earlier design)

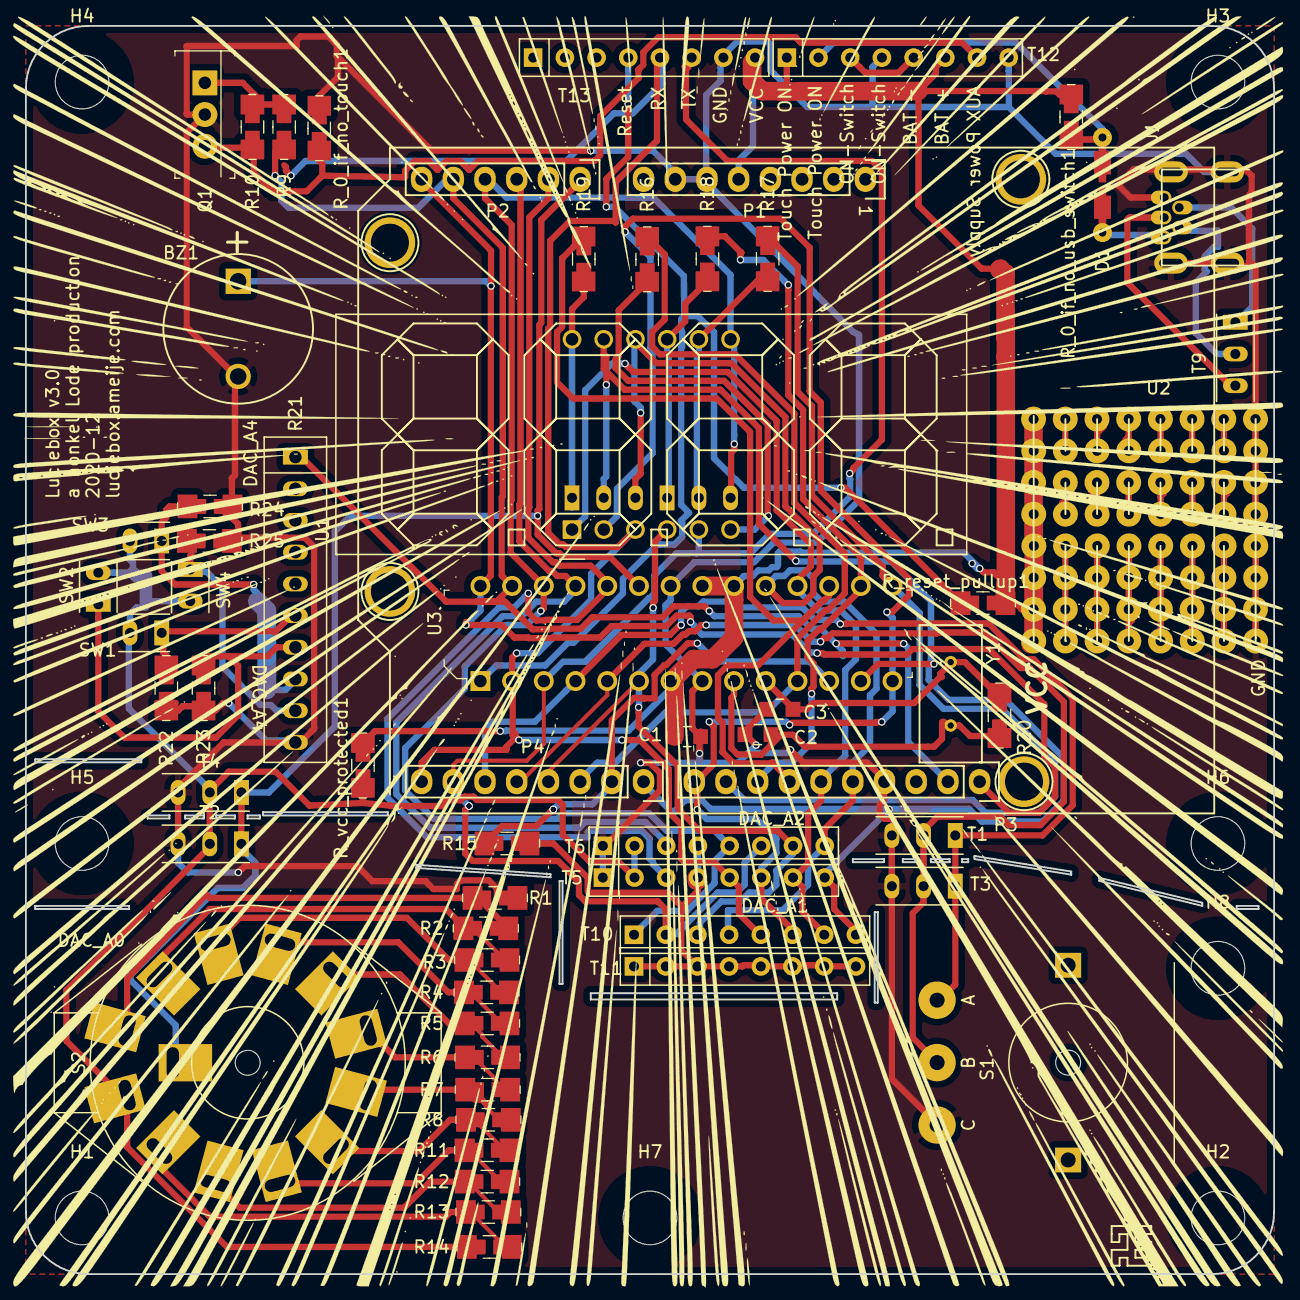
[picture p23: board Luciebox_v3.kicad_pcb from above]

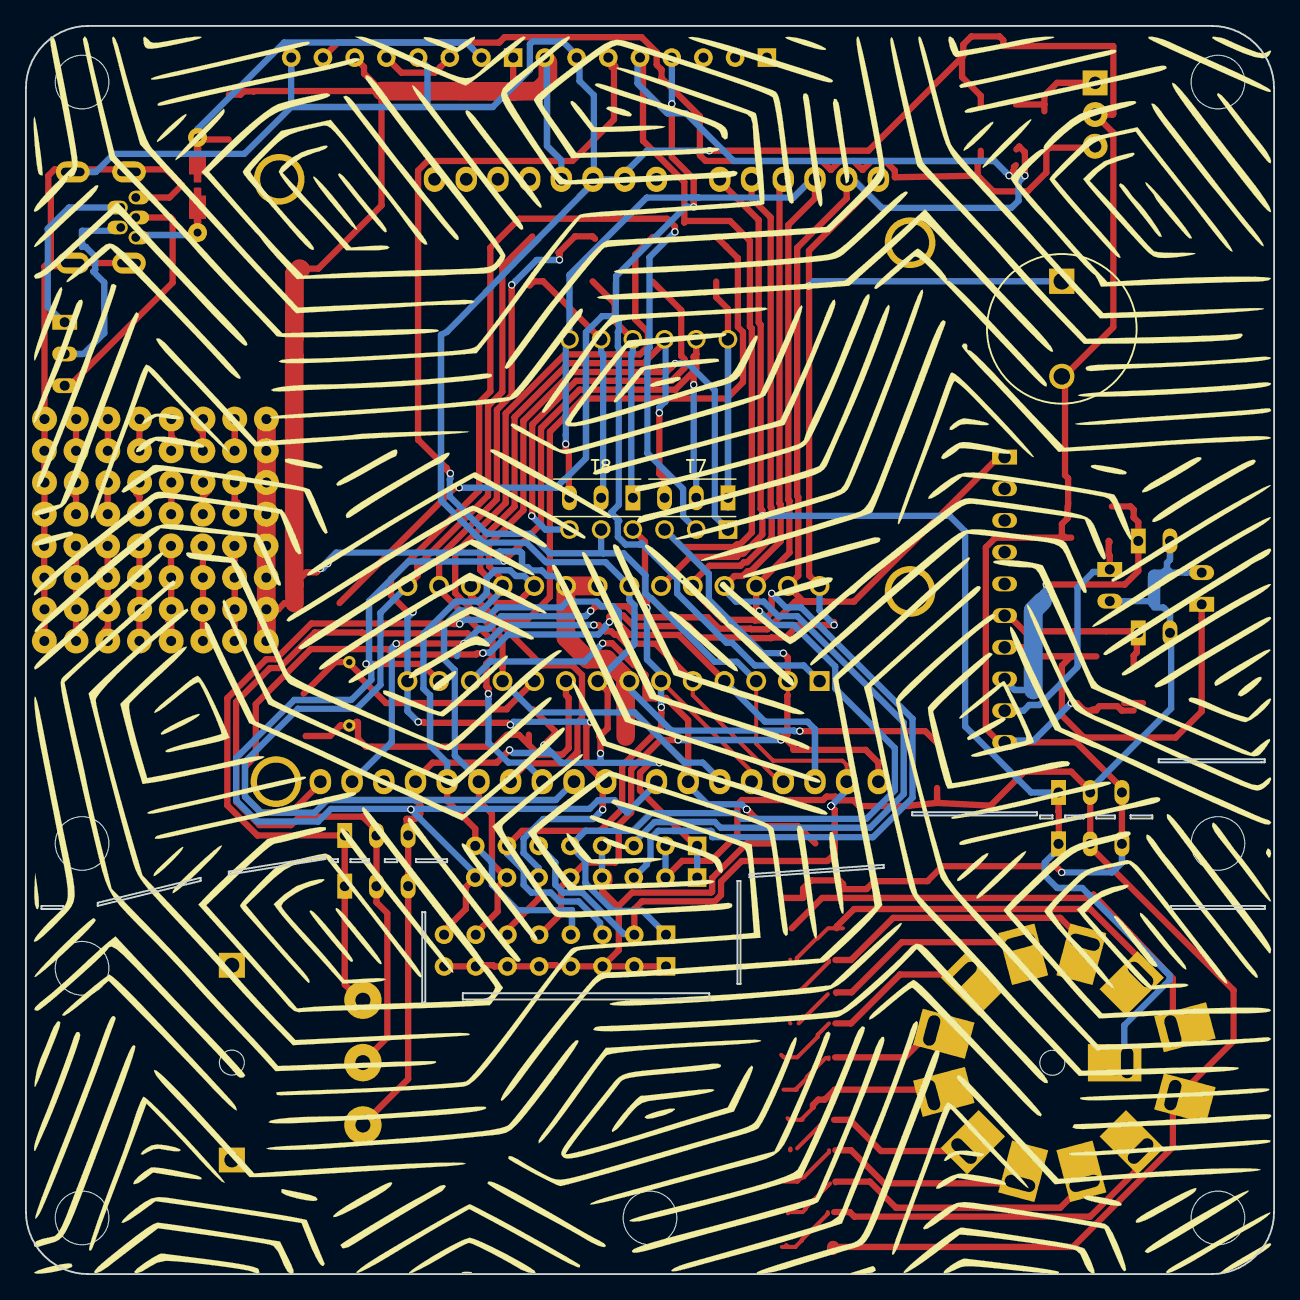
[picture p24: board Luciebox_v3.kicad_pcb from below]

Board: 2 copper layers, 100.0 x 100.0 mm, 75 parts (2 on the bottom side), 72 nets.

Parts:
BZ1: Buzzer; buzzer
C1: 100nF; 0805
C2, C3: 20pF; 0805
D1: D_Schottky; smd_throughhole_2_pins
H1, H2, H3, H4, H5, H6, H7, H8: MountingHole; MountingHole_4.3mm_M4
J1: USB_B_Mini; usb_mini_Molex-0548190519
P1: Power; Socket_Strip_Arduino_1x08
P2: Analog; Socket_Strip_Arduino_1x06
P3: Digital; Socket_Strip_Arduino_1x10
P4: Digital; Socket_Strip_Arduino_1x08
P5, P6, P7, P8: CONN_01X01; Arduino_1pin
Q1: N-Channel_Mosfet; TO-220-3
R1, R2, R3, R4, R5, R6, R7, R8, R9, R11, R12, R13, R14: 10K; 1206_0805
R10: 100K; 1206_0805
R15, R16, R17, R18, R19: 100; 1206_0805
R20: 1M; 1206_0805
R21: DAC_R-2R; SIP-10
R22, R23, R24, R25: R_Small; 1206_0805
R_0_if_no_touch1, R_0_if_no_usb_switch1: 0; 1206_0805
R_reset_pullup1: 30000; 1206_0805
R_vcc_protected1: 10K; 1206_0805
S1: rotary_encoder
S2: selector_knob; Rotary_Switch
SW1, SW2, SW3, SW4: Switch_tilt; Terminal_2x1_100mil
T1, T2, T3, T4, T7, T8, T9: terminal_3x1; Terminal_3x1_100mil
T5, T6, T10, T11, T12, T13: terminal_8x1; Terminal_8x1_100mil
U1: CA56-12SRWA
U2: 8X8PADS; 64_PADS_100mil
U3: ATmega328-PU; DIP-28_W7.62mm
Y1: 16MHz; CRYSTAL

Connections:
/0(Rx): P4.8, T5.5, T10.5, T13.5, U1.3, U3.2
/1(Tx): P4.7, T6.6, T10.2, T13.6, U1.5, U3.3
/2: P4.6, S1.1, T1.1, T3.1, U3.4
/3(PWM): P4.5, S1.2, T1.2, T3.2, U3.5
/4: P4.4, T6.7, T10.3, U1.4, U3.6
/5(PWM): P4.3, R16.2, U3.11
/6(PWM): P4.2, R15.2, U3.12
/7: P4.1, T5.8, T7.2, T10.8, U1.11, U3.13
/8: P3.10, T5.6, T10.6, U1.2, U3.14
/9(PWM): P3.9, R17.2, U3.15
/10(PWM-SS): P3.8, R18.2, U3.16
/11(PWM-MOSI): P3.7, R19.2, U3.17
/12(MISO): P3.6, T5.7, T10.7, U1.1, U3.18
/13(SCK): P3.5, T6.8, T7.3, T10.4, U1.10, U3.19
/A0: P2.1, S2.13, T2.1, T4.1, U3.23
/A1: P2.2, T5.3, U3.24
/A2: P2.3, T6.3, U3.25
/A3: P2.4, T6.5, T8.3, T10.1, U1.7, U3.26
/A4(SDA): P2.5, P3.2, R9.1, R21.1, U3.27
/A5(SCL): BZ1.1, P2.6, P3.1, U3.28
GND: BZ1.2, C1.2, C2.1, C3.1, J1.1, J1.6, P1.6, P1.7, P3.4, Q1.2, R1.2, R21.10, R22.1, R23.1, R24.1, R25.1, R_0_if_no_touch1.2, S1.3, T1.3, T2.3, T3.3, T4.3, T5.1, T6.1, T12.4, T12.8, T13.7, U2.57, U2.58, U2.59, U2.60, U2.61, U2.62, U2.63, U2.64, U3.8, U3.22
unnamed: C2.2, R20.1, U3.9, Y1.1
unnamed: C3.2, R20.2, U3.10, Y1.2
unnamed: D1.1, R_0_if_no_usb_switch1.1, T12.2
unnamed: D1.2, J1.5
unnamed: J1.2, T9.1
unnamed: J1.3, T9.3
unnamed: J1.4, T9.2
unnamed: Q1.1, R9.2, R10.1
unnamed: Q1.3, R10.2, R_0_if_no_touch1.1, T12.7
unnamed: R1.1, R2.2, S2.1
unnamed: R2.1, R3.2, S2.2
unnamed: R3.1, R4.2, S2.3
unnamed: R4.1, R5.2, S2.4
unnamed: R5.1, R6.2, S2.5
unnamed: R6.1, R7.2, S2.6
unnamed: R7.1, R8.2, S2.7
unnamed: R11.1, R12.2, S2.9
unnamed: R8.1, R11.2, S2.8
unnamed: R12.1, R13.2, S2.10
unnamed: R13.1, R14.2, S2.11
unnamed: R15.1, T5.4, T6.4, T11.1, T11.2, T11.3, T11.4, T11.5, T11.6, T11.7, T11.8
unnamed: R16.1, U1.6
unnamed: R17.1, T8.2, U1.8
unnamed: R18.1, T8.1, U1.9
unnamed: R19.1, T7.1, U1.12
unnamed: R21.6, R22.2, SW1.1
unnamed: R21.7, R23.2, SW2.1
unnamed: R21.8, R24.2, SW3.1
unnamed: R21.9, R25.2, SW4.1
unnamed: R_reset_pullup1.2, T13.4, U3.1
unnamed: T12.3, T12.5
unnamed: U2.9, U2.10, U2.11, U2.12
unnamed: U2.13, U2.14
unnamed: U2.15, U2.16
unnamed: U2.17, U2.18, U2.19, U2.20
unnamed: U2.21, U2.22
unnamed: U2.23, U2.24
unnamed: U2.25, U2.26, U2.27, U2.28
unnamed: U2.29, U2.30
unnamed: U2.31, U2.32
unnamed: U2.33, U2.34, U2.35, U2.36
unnamed: U2.37, U2.38
unnamed: U2.39, U2.40
unnamed: U2.41, U2.42, U2.43, U2.44
unnamed: U2.45, U2.46
unnamed: U2.47, U2.48
unnamed: U2.49, U2.50, U2.51, U2.52
unnamed: U2.53, U2.54
unnamed: U2.55, U2.56
VCC: C1.1, P1.5, R_0_if_no_usb_switch1.2, R_reset_pullup1.1, R_vcc_protected1.1, T12.1, T12.6, T13.8, U2.1, U2.2, U2.3, U2.4, U2.5, U2.6, U2.7, U2.8, U3.7, U3.20, U3.21
VCC_minimalCurrent: R14.1, R_vcc_protected1.2, S2.12, SW1.2, SW2.2, SW3.2, SW4.2, T2.2, T4.2, T5.2, T6.2

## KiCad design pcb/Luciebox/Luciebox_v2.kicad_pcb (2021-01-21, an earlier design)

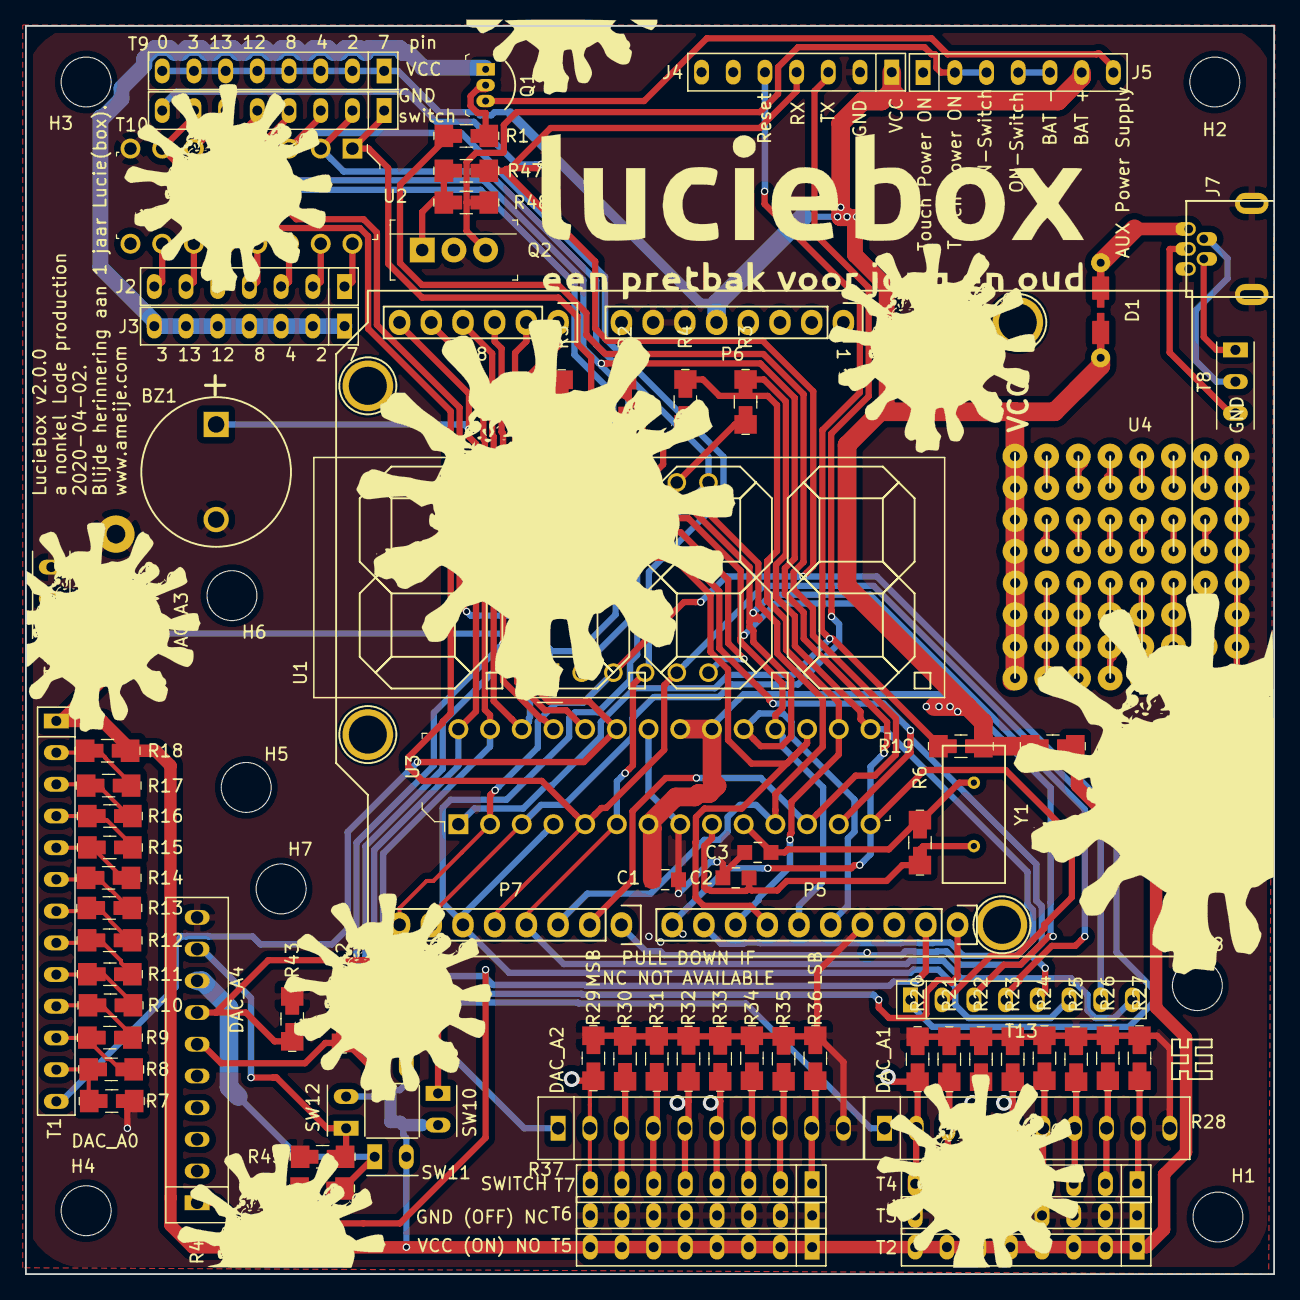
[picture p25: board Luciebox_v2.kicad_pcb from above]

Board: 2 copper layers, 100.0 x 100.0 mm, 95 parts (0 on the bottom side), 96 nets.

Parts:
BZ1: Buzzer; buzzer
C1: 100nF; 0805
C2, C3: 20pF; 0805
D1: D_Schottky; smd_throughhole_2_pins
H1, H2, H3, H4, H5, H6, H7, H8: MountingHole; MountingHole_4mm
J2, J3, J4, J5: Screw_Terminal_01x07; Terminal_7x1_100mil
J7: USB_B_Mini; usb_mini_Molex-0548190519
P1, P2, P3, P4: CONN_01X01; Arduino_1pin
P5: Digital; Socket_Strip_Arduino_1x10
P6: Power; Socket_Strip_Arduino_1x08
P7: Digital; Socket_Strip_Arduino_1x08
P8: Analog; Socket_Strip_Arduino_1x06
Q1: BC558; TO-92-3
Q2: N-Channel_Mosfet; TO-220-3
R1, R2, R3, R4, R5, R19: 100; 1206_0805
R6: 1M; 1206_0805
R7, R8, R9, R10, R11, R12, R13, R14, R15, R16, R17, R18, R49: 10K; 1206_0805
R20, R21, R22, R23, R24, R25, R26, R27, R29, R30, R31, R32, R33, R34, R35, R36, R42, R43, R44, R45: R_Small; 1206_0805
R28, R37, R46: DAC_R-2R; SIP-10
R47, R48: 100K; 1206_0805
RV1: R_POT; BIG_POTENTIO
SW9, SW10, SW11, SW12: Switch_tilt; Terminal_2x1_100mil
T1: terminal_13x1; Terminal_13x1_100mil
T2, T3, T4, T5, T6, T7, T9, T10, T13: terminal_8x1; Terminal_8x1_100mil
T8, T11: terminal_3x1; Terminal_3x1_100mil
U1: CA56-12SRWA
U2: ULN2003A; DIP-16_W7.62mm
U3: ATmega328-PU; DIP-28_W7.62mm
U4: 8X8PADS; 64_PADS_100mil
Y1: 16MHz; CRYSTAL

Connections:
+12V: J5.7, Q1.3
/0(Rx): J4.4, P7.8, R47.1, T10.8, T13.1, U1.3, U3.2
/1(Tx): J4.3, P7.7, U3.3
/2: P7.6, T10.2, T13.6, U1.7, U2.2, U3.4
/3(PWM): P7.5, T10.7, T13.7, U1.5, U2.7, U3.5
/4: P7.4, T10.3, T13.8, U1.4, U2.3, U3.6
/5(PWM): P7.3, R2.2, U3.11
/6(PWM): P7.2, R1.2, U3.12
/7: P7.1, T10.1, T13.5, U1.11, U2.1, U3.13
/8: P5.10, T10.4, T13.2, U1.2, U2.4, U3.14
/9(PWM): P5.9, R3.2, U3.15
/10(PWM-SS): P5.8, R4.2, U3.16
/11(PWM-MOSI): P5.7, R5.2, U3.17
/12(MISO): P5.6, T10.5, T13.3, U1.1, U2.5, U3.18
/13(SCK): P5.5, T10.6, T13.4, U1.10, U2.6, U3.19
/A0: P8.1, T1.13, U3.23
/A1: P8.2, R28.1, U3.24
/A2: P8.3, R37.1, U3.25
/A3: P8.4, RV1.2, T11.2, U3.26
/A4(SDA): P5.2, P8.5, R46.1, U3.27
/A5(SCL): BZ1.1, P5.1, P8.6, U3.28
GND: BZ1.2, C1.2, C2.1, C3.1, J4.2, J5.1, J7.5, J7.6, P5.4, P6.6, P6.7, Q2.2, R7.2, R20.2, R21.2, R22.2, R23.2, R24.2, R25.2, R26.2, R27.2, R28.10, R29.2, R30.2, R31.2, R32.2, R33.2, R34.2, R35.2, R36.2, R37.10, R42.1, R43.1, R44.1, R45.1, R46.10, RV1.3, T3.1, T3.2, T3.3, T3.4, T3.5, T3.6, T3.7, T3.8, T6.1, T6.2, T6.3, T6.4, T6.5, T6.6, T6.7, T6.8, T11.3, U2.8, U3.8, U3.22, U4.57, U4.58, U4.59, U4.60, U4.61, U4.62, U4.63, U4.64
unnamed: C2.2, R6.1, U3.9, Y1.1
unnamed: C3.2, R6.2, U3.10, Y1.2
unnamed: D1.2, J7.1
unnamed: J2.1, U2.16
unnamed: J2.2, U2.15
unnamed: J2.3, U2.14
unnamed: J2.4, U2.13
unnamed: J2.5, U2.12
unnamed: J2.6, U2.11
unnamed: J2.7, U2.10
unnamed: J3.1, J3.2, J3.3, J3.4, J3.5, J3.6, J3.7, Q1.1
unnamed: J4.5, R19.2, U3.1
unnamed: J5.2, J5.3, Q2.3, R48.2
unnamed: J5.4, J5.5
unnamed: J7.2, T8.2
unnamed: J7.3, T8.3
unnamed: J7.4, T8.1
unnamed: Q1.2, R1.1
unnamed: Q2.1, R47.2, R48.1
unnamed: R2.1, U1.6
unnamed: R3.1, U1.8
unnamed: R4.1, U1.9
unnamed: R5.1, U1.12
unnamed: R7.1, R8.2, T1.12
unnamed: R8.1, R9.2, T1.11
unnamed: R10.1, R11.2, T1.9
unnamed: R9.1, R10.2, T1.10
unnamed: R11.1, R12.2, T1.8
unnamed: R12.1, R13.2, T1.7
unnamed: R13.1, R14.2, T1.6
unnamed: R14.1, R15.2, T1.5
unnamed: R15.1, R16.2, T1.4
unnamed: R16.1, R17.2, T1.3
unnamed: R17.1, R18.2, T1.2
unnamed: R20.1, R28.2, T4.8
unnamed: R21.1, R28.3, T4.7
unnamed: R22.1, R28.4, T4.6
unnamed: R23.1, R28.5, T4.5
unnamed: R24.1, R28.6, T4.4
unnamed: R25.1, R28.7, T4.3
unnamed: R26.1, R28.8, T4.2
unnamed: R27.1, R28.9, T4.1
unnamed: R29.1, R37.2, T7.8
unnamed: R30.1, R37.3, T7.7
unnamed: R31.1, R37.4, T7.6
unnamed: R32.1, R37.5, T7.5
unnamed: R33.1, R37.6, T7.4
unnamed: R34.1, R37.7, T7.3
unnamed: R35.1, R37.8, T7.2
unnamed: R36.1, R37.9, T7.1
unnamed: R42.2, R46.6, SW9.1
unnamed: R43.2, R46.7, SW10.1
unnamed: R44.2, R46.8, SW11.1
unnamed: R45.2, R46.9, SW12.1
unnamed: U4.9, U4.10, U4.11, U4.12
unnamed: U4.13, U4.14
unnamed: U4.15, U4.16
unnamed: U4.17, U4.18, U4.19, U4.20
unnamed: U4.21, U4.22
unnamed: U4.23, U4.24
unnamed: U4.25, U4.26, U4.27, U4.28
unnamed: U4.29, U4.30
unnamed: U4.31, U4.32
unnamed: U4.33, U4.34, U4.35, U4.36
unnamed: U4.37, U4.38
unnamed: U4.39, U4.40
unnamed: U4.41, U4.42, U4.43, U4.44
unnamed: U4.45, U4.46
unnamed: U4.47, U4.48
unnamed: U4.49, U4.50, U4.51, U4.52
unnamed: U4.53, U4.54
unnamed: U4.55, U4.56
VCC: C1.1, D1.1, J4.1, J5.6, P6.5, R19.1, R49.1, T9.1, T9.2, T9.3, T9.4, T9.5, T9.6, T9.7, T9.8, U3.7, U3.20, U3.21, U4.1, U4.2, U4.3, U4.4, U4.5, U4.6, U4.7, U4.8
VCC_minimalCurrent: R18.1, R49.2, RV1.1, SW9.2, SW10.2, SW11.2, SW12.2, T1.1, T2.1, T2.2, T2.3, T2.4, T2.5, T2.6, T2.7, T2.8, T5.1, T5.2, T5.3, T5.4, T5.5, T5.6, T5.7, T5.8, T11.1

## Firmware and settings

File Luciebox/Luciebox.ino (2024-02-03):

#include "PretbakSettings.h"
#include "DisplayDigitsHandler5Digits.h"
#include "LedMultiplexer5x8.h"
#include "PotentioSelector.h"
#include "ButtonsDacR2r.h"
#include "BinaryInput.h"
#include "Buzzer.h"
#include "RotaryEncoderDial.h"

#ifdef ENABLE_APPS
#include "Apps.h"
#endif

// Lode Ameije 2019-05
// Pretbak is a busy box for my newly born niece
// The hardware is a box with:
// input: 4 big buttons, 4 small buttons, an encoder dial, a selector dial, and optionally four mercury switches.
// output: lights on buttons (one light per button), 7seg display (4 digits), buzzer

// compiling: optimizations --> erratum: it's already optimized as a default.....
// https://forum.arduino.cc/t/code-size-with-different-versions-and-flto-optimization/253140
// link time optimizations (LTO)

uint16_t setValues_1[BUTTONS_BIG_COUNT] = BUTTONS_BIG_VALUES;
uint16_t setValues_2[BUTTONS_SMALL_COUNT] = BUTTONS_SMALL_VALUES;

#ifdef ENABLE_TILT_SWITCHES
uint16_t setValues_mercury[MERCURY_SWITCHES_COUNT] = MERCURY_SWITCHES_VALUES;
#endif

//pretbak
#ifdef ENABLE_APPS
Apps pretbak_apps;
#endif

// INPUT
BinaryInput binaryInputs[BINARY_INPUTS_COUNT]; // 0: top left button, 4:bottom left button
#ifdef ENABLE_SELECT_APPS_WITH_SELECTOR
PotentioSelector selectorDial;
#endif
ButtonsDacR2r g_big_buttons;
ButtonsDacR2r g_small_buttons; // for v2: buttons without normally closed. this is a problem for the R-2R ladder. instead, I used a pull down resistor to ground at the switch. so: ON = 5V, OFF = GND over 1Kohm. 10K, 20K R2Rladder.  will only work for limited number of buttons.
#ifdef ENABLE_TILT_SWITCHES
ButtonsDacR2r mercurySwitches; // mercury switches go on or off depending on the position. Works with R-2R ladder. No NC in mercury switch, so, pulldown resistor (0.1R)to ground. R=10K
#endif

RotaryEncoderDial encoder_dial;

// OUTPUT
DisplayManagement visualsManager;
LedMultiplexer5x8 ledDisplay;
Buzzer buzzer;

#ifdef ENABLE_EEPROM
bool aBigButtonIsPressed = false;
#endif

// hack to get interrupts nicely going without too much magic.
// https://forum.arduino.cc/index.php?topic=41713.0
// interrupts are use for the encoder dial
void isr0()
{
    encoder_dial.interruptChannelA();
}
void isr1()
{
    encoder_dial.interruptChannelB();
}

void lucieboxLoop()
{
    //update inputs
    processInput();

#ifdef DEBUG_BUTTONS
    for (uint8_t i = 0; i < BINARY_INPUTS_COUNT; i++)
    {
        if (binaryInputs[i].getEdgeUp())
        {
            Serial.println("{{{-------PRESS:-------:");
            Serial.println(i);
            Serial.println((analogRead(PIN_BUTTONS_BIG)));
            Serial.println((analogRead(PIN_BUTTONS_SMALL)));
            //Serial.println(g_big_buttons.getButtonsValueRaw(),BIN);
            //Serial.println(g_small_buttons.getButtonsValueRaw(),BIN);
        }

        if (binaryInputs[i].getEdgeDown())
        {
            Serial.println("-----RELEASE:");
            Serial.println(i);
            //Serial.println( (analogRead(PIN_BUTTONS_BIG)));
            //Serial.println(g_big_buttons.getButtonsValueRaw(),BIN);
        }
    }
#endif

    //Serial.println("papa help "); // display this PAPA - HELP - PAPA - ... on screen when errors.

#ifdef DEBUG_SELECTOR_KNOB
    //rotary 12 positions selector knob is taken as base for mode selecion. so there are 12 states.
    if (selectorDial.getValueChangedEdge())
    {
        //Serial.println(SELECTOR_DIAL_POSITIONS);
        Serial.println("selector:");
        Serial.println(selectorDial.getSelectorValue());
        Serial.println(analogRead(PIN_SELECTOR_DIAL));
    }
#endif

#ifdef ENABLE_APPS
    pretbak_apps.appStateLoop();
#endif

    processOuput();
}

void processInput()
{
    // process edges from binaryInputs here, think of it as the previous cycle (done before new input processed.)
    for (uint8_t i = 0; i < BINARY_INPUTS_COUNT; i++)
    {
        binaryInputs[i].refresh();
    }
#ifdef ENABLE_SELECT_APPS_WITH_SELECTOR
    selectorDial.refresh();
#endif

    g_big_buttons.refresh();
    g_small_buttons.refresh();
#ifdef ENABLE_TILT_SWITCHES
    mercurySwitches.refresh();
#endif
    encoder_dial.refresh();

    if (g_small_buttons.getValueChangedEdge())
    {
        for (uint8_t i = 0; i < BUTTONS_SMALL_COUNT; i++)
        {
            binaryInputs[BUTTONS_SMALL_TO_BINARY_INPUT_OFFSET + i].setValue(g_small_buttons.getButtonValueByIndex(i));
        }
    }
#ifndef ENABLE_SELECT_APPS_WITH_SELECTOR
    binaryInputs[0].setValue(digitalRead(PIN_SELECTOR_BUTTON));
#endif

    if (g_big_buttons.getValueChangedEdge())
    {
#ifdef ENABLE_EEPROM
        if (!aBigButtonIsPressed)
        {
            // add 1 to power cycles tally keeper. It's done at first key press to avoid gigantic number in case of multiple brown outs.
            eeprom_update_word((uint16_t *)EEPROM_LUCIEBOX_POWER_CYCLE_COUNTER, eeprom_read_word((uint16_t *)EEPROM_LUCIEBOX_POWER_CYCLE_COUNTER) + 1);
            aBigButtonIsPressed = true;
        }
#endif

        for (uint8_t i = 0; i < BUTTONS_BIG_COUNT; i++)
        {
            binaryInputs[BUTTONS_BIG_TO_BINARY_INPUT_OFFSET + i].setValue(g_big_buttons.getButtonValueByIndex(i));
        }
    }

#ifdef ENABLE_TILT_SWITCHES
    if (mercurySwitches.getValueChangedEdge())
    {
#ifdef DEBUG_MERCURY
        Serial.println("analog in mercury switches:");
        Serial.println(analogRead(A4));
        Serial.println(mercurySwitches.getButtonsValueRaw(), BIN);
        Serial.println(mercurySwitches.getButtonsValue());
#endif

        for (uint8_t i = 0; i < MERCURY_SWITCHES_COUNT; i++)
        {
#ifdef DEBUG_MERCURY
            Serial.println(MERCURY_SWITCHES_TO_BINARY_INPUT_OFFSET);
            Serial.println(i);
#endif
            binaryInputs[MERCURY_SWITCHES_TO_BINARY_INPUT_OFFSET + i].setValue(mercurySwitches.getButtonValueByIndex(i));
        }
    }
#endif
}

void processOuput()
{
    buzzer.checkAndPlayNotesBuffer();
    visualsManager.refresh();
    ledDisplay.refresh();
}

void setup()
{
#ifdef ENABLE_SOFT_POWER_OFF
    // first thing to do: hold power
    pinMode(PIN_POWER_ON_HOLD, OUTPUT);
    digitalWrite(PIN_POWER_ON_HOLD, HIGH);
#endif

    // fill up the ram with a default value. This is fun to check in HACK mode.
    // by checking how much of the original values are still there, we can see how much RAM is used at its peak
    // test done 20210409 with i=600 at init: dial was not working. But, ram values constant from address: 1075->2047
    // for (uint16_t i=1000;i<2048;i++){
    // for (uint16_t i=500;i<2048;i++){ // works, but display is trembling, dial not working
    // for (uint16_t i=750;i<2048;i++){ // works, but dial not working
    for (uint16_t i = 1000; i < 2048; i++)
    {                         // works, but dial not working
        *((uint8_t *)i) = 63; // 63 is the random value in lucieAscii
    }

    // trick to use the easy arduino libary
    // instead of complicated native functions
    attachInterrupt(0, isr0, CHANGE);
    attachInterrupt(1, isr1, CHANGE);

#ifdef ENABLE_SERIAL
    Serial.begin(9600);
#endif
#ifdef ENABLE_SELECT_APPS_WITH_SELECTOR
    selectorDial.initialize(PIN_SELECTOR_DIAL, SELECTOR_DIAL_POSITIONS);
#else
    pinMode(PIN_SELECTOR_BUTTON, INPUT);
    digitalWrite(PIN_SELECTOR_BUTTON, HIGH); // pull high
#endif

    g_big_buttons.setPin(PIN_BUTTONS_BIG, BUTTONS_BIG_COUNT, setValues_1);
    g_small_buttons.setPin(PIN_BUTTONS_SMALL, BUTTONS_SMALL_COUNT, setValues_2);
    encoder_dial.setPins(PIN_ROTARY_ENCODER_DIAL_CHANNEL_A, PIN_ROTARY_ENCODER_DIAL_CHANNEL_B);
    ledDisplay.Begin(DISPLAY_IS_COMMON_ANODE, PIN_DISPLAY_DIGIT_0, PIN_DISPLAY_DIGIT_1, PIN_DISPLAY_DIGIT_2, PIN_DISPLAY_DIGIT_3, PIN_DISPLAY_DIGIT_BUTTON_LIGHTS, PIN_DISPLAY_SEGMENT_A, PIN_DISPLAY_SEGMENT_B, PIN_DISPLAY_SEGMENT_C, PIN_DISPLAY_SEGMENT_D, PIN_DISPLAY_SEGMENT_E, PIN_DISPLAY_SEGMENT_F, PIN_DISPLAY_SEGMENT_G, PIN_DISPLAY_SEGMENT_DP);
    visualsManager.setMultiplexerBuffer(ledDisplay.getDigits());
#ifdef ENABLE_TILT_SWITCHES
    mercurySwitches.setPin(PIN_MERCURY_SWITCHES, MERCURY_SWITCHES_COUNT, setValues_mercury);
    mercurySwitches.setDebounceMillis(30);
#endif

#ifdef ENABLE_EEPROM

    uint8_t soundDisabled = eeprom_read_byte((uint8_t *)EEPROM_SOUND_DISABLED);

    // set sound
    int buzzer_pin = PIN_BUZZER;
    if (soundDisabled == 1)
    {
        buzzer_pin = PIN_BUZZER_FAKE;
    }
    buzzer.setPin(buzzer_pin);

    if (soundDisabled == 0xFF)
    {
        //first power on ever.
        // do total reset
        // confirmation song will not play because we are not yet in our refresh loop at setup
        pretbak_apps.eraseEepromRangeLimited(EEPROM_TOTAL_RESET);
    }

#else
    buzzer.setPin(PIN_BUZZER);
#endif

#ifdef ENABLE_APPS
#ifdef ENABLE_SELECT_APPS_WITH_SELECTOR
    pretbak_apps.setPeripherals(binaryInputs, &encoder_dial, &visualsManager, &ledDisplay, &buzzer, &selectorDial);
#else
    pretbak_apps.setPeripherals(binaryInputs, &encoder_dial, &visualsManager, &ledDisplay, &buzzer);
#endif

#endif
}

void loop()
{
    lucieboxLoop();
}

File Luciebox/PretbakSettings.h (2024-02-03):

#define SOFTWARE_VERSION 308
// started at v2.00: 200
// v300 : pcb v3 burst implemented. change in button sequence...
// v301 : sending out to Belgium 2021-03-19
// v302 : development since 2021-03-19. Numerous small bugfixes and additional functionality.
// v303 : settings debug selector dial. Make sure values are not too erratic. small bugfixes.
// v304 : quizmaster scoring bugfix and optimization / baby dreamtime mode change behaviour + shift button keeps it in dreamtime mode (all button mash apps should have the shift button included). / total time timer is now set to a timer of the chrono app.
// v305 : add battery voltage indicator (note the voltagedrop because of a Schottky diode to differentiate between real battery voltage and Vcc) / buzzer rework (note scheme, buzzer buffer) / sequencer rework
// v306 : song composer / change apps sequence. baby app has no shift.
// v307 : introduce V4 prototype. make app selector dial optional. redo apps (see manual)
// v308 : V5: bugfixes

// #define ENABLE_SERIAL  //for debugging. if used, pin 0 and 1 cannot be used for other purposes than tx and rx
//#define ENABLE_TILT_SWITCHES
//#define ENABLE_ANALOG_PIN_DEBUG  // for debugging at startup (always available in apps anyways.)

// #define V2_PCB_CORONA
//#define V3_PCB_BURST
// #define V4_PCB_MINI --> abandoned. extremely similar layout of V5 (which is just a debugged V4)
#define V5_PCB_MINI

// #define ENABLE_SELECT_APPS_WITH_SELECTOR  // up to version 3 a big selector dial is used to change apps.
#define ENABLE_SOFT_POWER_OFF

#define ENABLE_APPS
#define ENABLE_BATTERY_STATUS

#ifdef ENABLE_SERIAL
//#define DEBUG_ENCODER_DIAL
//#define DEBUG_ANALOG_IN
//#define DEBUG_MERCURY
//#define DEBUG_POTENTIO
//#define DEBUG_BUTTONS
//#define DEBUG_SELECTOR_KNOB
//#define DEBUG_MINIMULTITIMER
//#define DEBUG_SEQUENCER
//#define SUPERDEBUG
#endif

#define DISPLAY_IS_COMMON_ANODE true //check led displays both displays should be of same type   //also set in SevSeg5Digits.h : MODEISCOMMONANODE

#define PIN_DUMMY 66
#define PIN_DUMMY_2 22 // randomly chosen. I've had it set to 67, and at some point, multiple segments were lit up. This STILL is C hey, it's gonna chug on forever!

#define PIN_DISPLAY_DIGIT_0 11
#define PIN_DISPLAY_DIGIT_1 10
#define PIN_DISPLAY_DIGIT_2 9
#define PIN_DISPLAY_DIGIT_3 5
#define PIN_DISPLAY_DIGIT_BUTTON_LIGHTS 6

#define PIN_DISPLAY_SEGMENT_A 7
#define PIN_DISPLAY_SEGMENT_B A3 // was 2
#define PIN_DISPLAY_SEGMENT_C 4
#define PIN_DISPLAY_SEGMENT_D 8
#define PIN_DISPLAY_SEGMENT_E 12
#define PIN_DISPLAY_SEGMENT_F 13

#define PIN_BUZZER_FAKE 68

#define PIN_BUZZER A5

#ifdef ENABLE_SERIAL
#define PIN_DISPLAY_SEGMENT_DP PIN_DUMMY_2
#define PIN_DISPLAY_SEGMENT_G PIN_DUMMY_2 // was 3

#else
#define PIN_DISPLAY_SEGMENT_DP 0
#define PIN_DISPLAY_SEGMENT_G 1 // was 3

#endif

#ifdef ENABLE_SELECT_APPS_WITH_SELECTOR
#define PIN_SELECTOR_DIAL A0
#define SELECTOR_DIAL_POSITIONS 12 //there are only 12 actual positions on the knob, but the resistor bridge has 13 positions on the final version (gnd is never provided, to avoid short circuits at the switch between ground and vcc)

#else
#define PIN_SELECTOR_BUTTON A0

#endif

#define PIN_ROTARY_ENCODER_DIAL_CHANNEL_A 2
#define PIN_ROTARY_ENCODER_DIAL_CHANNEL_B 3

#ifdef ENABLE_SOFT_POWER_OFF
#define PIN_POWER_ON_HOLD A4
#else
#define PIN_MERCURY_SWITCHES A4
#endif

#ifdef ENABLE_TILT_SWITCHES

#define SWITCH_TILT_FORWARD 11
#define SWITCH_TILT_BACKWARD 9
#define SWITCH_TILT_LEFT 8
#define SWITCH_TILT_RIGHT 10

#define BINARY_INPUTS_COUNT 12
#else
#define BINARY_INPUTS_COUNT 8

#endif

#define BIG_BUTTONS_COUNT 4

#if (defined V5_PCB_MINI)
#define PIN_BUTTONS_BIG A2
#define PIN_BUTTONS_SMALL A1
#define LIGHT_BUTTON_SMALL_0 0  //old: LIGHT_BUTTON_SMALL_0 0  // old: big latch
#define LIGHT_BUTTON_SMALL_1 1  //old: LIGHT_BUTTON_SMALL_1 1  // old: small latch left
#define LIGHT_BUTTON_SMALL_2 2  //old: LIGHT_BUTTON_SMALL_2 2  // old: small latch right
#define LIGHT_BUTTON_SMALL_3 3  //old: LIGHT_BUTTON_SMALL_3 3  // old: extra latch
#define LIGHT_BUTTON_BIG_0 7  //old: LIGHT_BUTTON_BIG_0 7 // old: m omentary 0
#define LIGHT_BUTTON_BIG_1 6  //old: LIGHT_BUTTON_BIG_1 6 // old: m omentary 1
#define LIGHT_BUTTON_BIG_2 5  //old: LIGHT_BUTTON_BIG_2 5 // old: m omentary 2
#define LIGHT_BUTTON_BIG_3 4  //old: LIGHT_BUTTON_BIG_3 4 // old: m omentary 3

#define BUTTONS_BIG_TO_BINARY_INPUT_OFFSET 4
#define BUTTONS_BIG_COUNT 4
#define BUTTONS_BIG_VALUES \
    {                            \
        512, 256, 128, 64        \
    }

#define BUTTONS_SMALL_COUNT 4
#define BUTTONS_SMALL_TO_BINARY_INPUT_OFFSET 0
#define BUTTONS_SMALL_VALUES \
    {                           \
        512, 256, 128, 64       \
    }

#define MERCURY_SWITCHES_COUNT 4
#define MERCURY_SWITCHES_TO_BINARY_INPUT_OFFSET 8
#define MERCURY_SWITCHES_VALUES \
    {                           \
        450, 262, 128, 64       \
    }
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

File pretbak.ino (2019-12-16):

#include "PotentioSelector.h"
#include "ButtonsDacR2r.h"
#include "BinaryInput.h"
#include "Buzzer.h"
#include "Apps.h"
#include "Potentio.h"
#include "DisplayDigitsHandler5Digits.h"
#include "PretbakSettings.h"

//#define ENABLE_SERIAL  //for debugging. if used, pin 0 and 1 cannot be used for other purposes than tx and rx

#ifdef ENABLE_SERIAL
  #define DEBUG_MERCURY
  //#define DEBUG_POTENTIO
  // #define DEBUG_BUTTONS
  //#define DEBUG_SELECTOR_KNOB
  //#define DEBUG_MINIMULTITIMER
  //#define DEBUG_SEQUENCER
#endif 

// Lode Ameije 2019-05
// Pretbak is a busy box for my newly born niece
// The hardware is a box with:
// input: momentary buttons, latching buttons, a potentiometer, a selector dial, four mercury switches.
// output: lights on buttons (one light per button), 7seg display (4 digits), buzzer

//pretbak
Apps pretbak_apps;

// INPUT
BinaryInput binaryInputs[BINARY_INPUTS_COUNT];
PotentioSelector selectorDial;
ButtonsDacR2r buttons_1;
ButtonsDacR2r buttons_2; // buttons without normally closed. this is a problem for the R-2R ladder. instead, I used a pull down resistor to ground at the switch. so: ON = 5V, OFF = GND over 1Kohm. 10K, 20K R2Rladder.  will only work for limited number of buttons.
ButtonsDacR2r mercurySwitches;  // mercury switches go on or off depending on the position. Works with R-2R ladder. No NC in mercury switch, so, pulldown resistor (0.1R)to ground. R=10K 
Potentio potentio;

// OUTPUT
DisplayManagement ledDisp;
Buzzer buzzer;

//output
char  textBuf [6];
char  scrollBuf [40];

void refresh(){
  //input process  
  input_process();
  
  #ifdef DEBUG_BUTTONS
  
  for(uint8_t i=0;i<BINARY_INPUTS_COUNT;i++){
    if (binaryInputs[i].getEdgeUp()){
      
      Serial.println("PRESS:");
      Serial.println(i);
       Serial.println( (analogRead(PIN_BUTTONS_1)));
       Serial.println( (analogRead(PIN_BUTTONS_2)));
  
    }
    if (binaryInputs[i].getEdgeDown()){
      Serial.println("RELEASE:");
      Serial.println(i);
//      Serial.println("Button released");
//      Serial.println("analog in mercury switches edge down:");
//      Serial.println(mercurySwitches.getButtonsValueRaw());
      
    }
  }
  
  #endif
  
  //Serial.println("papa help "); // display this PAPA - HELP - PAPA - ... on screen when errors.

  //modes functionality
  
  //mode change
  if (selectorDial.getValueChangedEdge()) {
    //default mode (go to default state at each change)
    pretbak_apps.setDefaultMode();
    
    #ifdef DEBUG_SELECTOR_KNOB
    Serial.println("selector:");
    Serial.println(selectorDial.getSelectorValue());
    #endif
    
  }

  mode_refresh();

  //output process
  ledDisp.refresh();
  buzzer.doBuzzerRoll();
    
  for(uint8_t i=0;i<BINARY_INPUTS_COUNT;i++){
    binaryInputs[i].refresh();
  }
}

void input_process(){
  selectorDial.refresh();
  buttons_1.refresh();
  buttons_2.refresh();
  mercurySwitches.refresh();
  potentio.refresh();

  if (buttons_2.getValueChangedEdge()) {
    for (uint8_t i=0; i< BUTTONS_2_COUNT; i++){
      binaryInputs[BUTTONS_2_TO_BINARY_INPUT_OFFSET + i].setValue(buttons_2.getButtonValueByIndex(i));
    }
  }

  if (buttons_1.getValueChangedEdge()) {
    //Serial.println("analog in buttons:");
    //Serial.println(buttons_1.getButtonsValueRaw());
    //Serial.println(buttons_1.getButtonsValue());
    for (uint8_t i=0; i< BUTTONS_1_COUNT; i++){
      binaryInputs[BUTTONS_1_TO_BINARY_INPUT_OFFSET + i].setValue(buttons_1.getButtonValueByIndex(i));
    }
  }

   if (mercurySwitches.getValueChangedEdge()) {
      #ifdef DEBUG_MERCURY
      Serial.println("analog in mercury switches:");
      Serial.println(analogRead(A4));
      Serial.println(mercurySwitches.getButtonsValueRaw(), BIN);
      Serial.println(mercurySwitches.getButtonsValue());
      #endif
    for (uint8_t i=0; i< MERCURY_SWITCHES_COUNT; i++){
       #ifdef DEBUG_MERCURY
      Serial.println(MERCURY_SWITCHES_TO_BINARY_INPUT_OFFSET );
      Serial.println(i);
      #endif
      binaryInputs[MERCURY_SWITCHES_TO_BINARY_INPUT_OFFSET + i].setValue(mercurySwitches.getButtonValueByIndex(i));
    }
  }
}



void mode_refresh(){
  
  //rotary 12 positions selector knob is taken as base for mode selecion. so there are 12 states. 

  //check if first iteration at new selector value.
  bool init = selectorDial.getValueChangedEdge();
  pretbak_apps.appSelector(init, selectorDial.getSelectorValue());
  
}

void setup() {
  
  #ifdef ENABLE_SERIAL
  Serial.begin(9600);
  #endif
  
  // put your setup code here, to run once
  
  selectorDial.setPin(PIN_SELECTOR_DIAL);
  buttons_1.setPin(PIN_BUTTONS_1,BUTTONS_1_COUNT);
  buttons_2.setPin(PIN_BUTTONS_2,BUTTONS_2_COUNT);
  mercurySwitches.setPin(PIN_MERCURY_SWITCHES, MERCURY_SWITCHES_COUNT);
  mercurySwitches.setDebounceMillis(30);

  buzzer.setPin(PIN_BUZZER);

  potentio.setPin(PIN_POTENTIO);
  
  ledDisp.startUp(DISPLAY_IS_COMMON_ANODE, PIN_DISPLAY_DIGIT_0, PIN_DISPLAY_DIGIT_1, PIN_DISPLAY_DIGIT_2, PIN_DISPLAY_DIGIT_3, PIN_DISPLAY_DIGIT_4, PIN_DISPLAY_DIGIT_BUTTON_LIGHTS, PIN_DISPLAY_SEGMENT_A, PIN_DISPLAY_SEGMENT_B, PIN_DISPLAY_SEGMENT_C, PIN_DISPLAY_SEGMENT_D, PIN_DISPLAY_SEGMENT_E, PIN_DISPLAY_SEGMENT_F, PIN_DISPLAY_SEGMENT_G, PIN_DISPLAY_SEGMENT_DP);
  //ledDisp.startUp(DISPLAY_IS_COMMON_ANODE, PIN_DISPLAY_DIGIT_0, PIN_DISPLAY_DIGIT_1, PIN_DISPLAY_DIGIT_2, PIN_DISPLAY_DIGIT_3, PIN_DISPLAY_DIGIT_4, PIN_DISPLAY_SEGMENT_A, PIN_DISPLAY_SEGMENT_B, PIN_DISPLAY_SEGMENT_C, PIN_DISPLAY_SEGMENT_D, PIN_DISPLAY_SEGMENT_E, PIN_DISPLAY_SEGMENT_F, PIN_DISPLAY_SEGMENT_G, PIN_DISPLAY_SEGMENT_DP);


  pretbak_apps.setPeripherals(binaryInputs, &potentio, &ledDisp, &buzzer);
  pretbak_apps.setBuffers(scrollBuf, textBuf);
  pretbak_apps.setDefaultMode();
}

void loop() {
  // put your main code here, to run repeatedly:
  refresh();
}

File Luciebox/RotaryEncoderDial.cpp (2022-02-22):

#include "RotaryEncoderDial.h"
#include "Arduino.h"
#include "PretbakSettings.h"

//empty constructor
RotaryEncoderDial::RotaryEncoderDial()
{
    // this->increment = 1;
    // this->encoderPos = 0;

    this->sensitivity = 0;
    this->sensitivity_counter = 0;
    this->maxValue = 32767;
    this->wrapAround = false;
}

int8_t RotaryEncoderDial::getDelta()
{
    // only take into account small increases. if it jumps.
    return this->delta_memory;
}

void RotaryEncoderDial::setRange(int16_t maxValue, boolean wrapAround)
{
    this->maxValue = maxValue;
    this->wrapAround = wrapAround;
    if (this->value > this->maxValue)
    {
        this->value = this->maxValue;
    }
}

int16_t RotaryEncoderDial::getValueLimited(int16_t maxValue, boolean wrapAround)
{
    this->setRange(maxValue, wrapAround);
    return this->getValue();
}

// int16_t RotaryEncoderDial::getValueMapped(int16_t minValue, int16_t maxValue){
//   // DEPRECATED!
//   // hacked. Not yet nicely done!!!
//   this->setRange (maxValue, false);
//   return this->getValue();
// }

void RotaryEncoderDial::refresh()
{
    noInterrupts();
    // disable interrupts when working with values that are modified by them.
    this->delta_memory = this->delta;
    this->delta = 0;
    interrupts();
    // take care for non atomic actions (16bit value on 8 bit processor), so an interrupt can ruin it!
    this->value += this->delta_memory;

    if (this->value < 0)
    {
        if (this->wrapAround)
        {
            this->value = this->maxValue;
        }
        else
        {
            this->value = 0;
        }
    }
    else if (this->value > this->maxValue)
    {
        if (this->wrapAround)
        {
            this->value = 0;
        }
        else
        {
            this->value = this->maxValue;
        }
    }

    // edge detection here, so it stays 'on' until next refresh.
    // this->value_changed = this->value - this->value_memory;
    // #ifdef ENABLE_SERIAL

    // #endif

    this->value_memory = this->value;
}

void RotaryEncoderDial::setValue(int16_t value)
{
    // noInterrupts();
    // this->delta_memory = 0;
    // interrupts();
    this->value = value;
    this->refresh();
    // this->value_changed = 0; // let's not detect edges if we set the value manually.
}

int16_t RotaryEncoderDial::getValue()
{
    return this->value;
}

void RotaryEncoderDial::setSensitivity(uint8_t sensitivity)
{
    // number of steps for encoder before a step is detected and the value incremented.
    // 1 is no extra steps added.
    // 96 is full turn per step.
    this->sensitivity = sensitivity - 1;
    // this->sensitivity_counter = 0;
}

// void RotaryEncoderDial::setIncrement(uint8_t increment){
//   this->increment = increment;
// }

void RotaryEncoderDial::setPins(byte pinChannelA, byte pinChannelB)
{
    // https://www.onetransistor.eu/2019/05/arduino-class-interrupts-and-callbacks.html
    this->pinChannelA = pinChannelA; // MUST BE pin 2 for arduino uno interrupt CHANGE to work
    this->pinChannelB = pinChannelB; // MUST BE pin 3 for arduino uno interrupt CHANGE to work

    pinMode(this->pinChannelA, INPUT);
    pinMode(this->pinChannelB, INPUT);

    digitalWrite(this->pinChannelA, HIGH);
    digitalWrite(this->pinChannelB, HIGH);

    this->A_set = 0;
    this->B_set = 0;
    this->A_waitfor = 1;
    this->B_waitfor = 1;
    this->A_changedir_waitfor = 1;
    this->B_changedir_waitfor = 1;

    this->ccwElseCw = 1;
    initialize();
}

void RotaryEncoderDial::initialize()
{
    this->A_set = digitalRead(this->pinChannelA);
    this->B_set = digitalRead(this->pinChannelB);
    this->setNewState();
    this->ccwElseCw = 0;
}

// Interrupt handling

void RotaryEncoderDial::interruptChannelA()
{
    this->A_set = digitalRead(this->pinChannelA);
    this->checkState();
}

void RotaryEncoderDial::interruptChannelB()
{
    this->B_set = digitalRead(this->pinChannelB);
    this->checkState();
}

void RotaryEncoderDial::checkState()
{
    // check the state if it satisfies the requirements for a step or a change of direction
    if (this->A_set == this->A_waitfor && this->B_set == this->B_waitfor)
    {
        // next step

        if (this->sensitivity_counter >= this->sensitivity)
        {
            if (ccwElseCw)
            {
                this->delta--;
            }
            else
            {
                this->delta++;
            }

            this->sensitivity_counter = 0;
        }
        else
        {
            this->sensitivity_counter++;
        }
        this->setNewState();
    }
    else if (this->A_set == this->A_changedir_waitfor && this->B_set == this->B_changedir_waitfor)
    {
        // change of dir
        this->ccwElseCw = !this->ccwElseCw;
        this->setNewState();
        this->sensitivity_counter = 0;
    }
}

void RotaryEncoderDial::setNewState()
{
    // to visualize: best to draw the two channels duty cycle for a full rotation and look what's going on. Channel phases are (should be) shifted 90degrees.
    this->A_waitfor = (this->B_set == this->ccwElseCw);
    this->B_waitfor = (this->A_set != this->ccwElseCw);
    this->A_changedir_waitfor = !this->A_set;
    this->B_changedir_waitfor = !this->B_set;
}

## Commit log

2019-05-05 init arduino and init of main menu dial. --> hardware bug: make before break dial.
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2019-05-13 make multiplexing leak less current by setting the ouputs as inputs (high impedance) during seven segment unused cycle.
    [SevSeg5Digits.cpp]
2019-05-18 create a buzzer class. compiles, but not yet tested
    [Buzzer.h]
2019-05-19 Buzzer working correctly. Show number to display as method in displayClass.
    [Buzzer.h]
2019-05-19 Buzzer functionality for pure frequencies. Organize mode selection
    [Buzzer.h]
2019-05-27 add individual segment manipulation for screen. BUG digit1 has weird output on displaygit status! todo
    [SevSeg5Digits.cpp]
2019-06-01 buzzer sounds done better
    [Buzzer.h]
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2019-08-01 commit 1: settings lights done, and discovery of fischer timer bug. Now the minimultitimer looks REALLY nice! It's my pronkstuk! commit2:settings lights done, and discovery of fischer timer bug. Now 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
    [Apps.cpp, Apps.h, Buzzer.h]
2019-08-06 pcb kicad schematic. add r2-r ladder with hierarchical sheet
    [Luciebox.kicad_pcb, Luciebox.sch, R-2R_DAC.sch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]
2019-08-13 pcb progress'
    [Luciebox.sch]
2019-08-13 pcb progress dedicated R-2R ladder'
    [Luciebox.kicad_pcb, Luciebox.sch, R2-R_ladder_dac.sch]
2019-08-13 pcb selector resistors
    [Luciebox.kicad_pcb]
2019-08-14 working on pcb of luciebox
    [Luciebox.kicad_pcb, R2-R_ladder_dac.sch]
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2019-08-31 pcb add auto power OFF hardware
    [Luciebox.sch, R2-R_ladder_dac.sch]
2019-11-06 pcb organize components
    [Luciebox.kicad_pcb]
2019-11-07 all components have footprint. All fitting on board.
    [Luciebox.kicad_pcb, Luciebox.sch, R2-R_ladder_dac.sch]
2019-11-07 pcb arrange components to input and ouput regions
    [Luciebox.kicad_pcb]
2019-11-10 pcb all traces made. Copper pours in place. Check for trace widths and artwork.
    [Luciebox.kicad_pcb, Luciebox.sch, R2-R_ladder_dac.sch]
2019-11-10 ah, now all traces are connected
    [Luciebox.kicad_pcb]
2019-11-11 fiddling with traces
    [Luciebox.kicad_pcb]
2019-11-12 pcb v1.0.0 looks like all done!
    [Luciebox.kicad_pcb, Luciebox.sch, R2-R_ladder_dac.sch]
2019-11-13 pcb add clouds soldermask back, create gerber files
    [Luciebox-B_Cu.gbr, Luciebox-B_Mask.gbr, Luciebox-B_SilkS.gbr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]
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2019-11-13 pcb v1.0.0 finished and ordered at jlcpcb.com
    [Luciebox-B_Cu.gbr, Luciebox-B_Mask.gbr, Luciebox-B_SilkS.gbr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]
2019-11-21 finish schematics for printout
    [Luciebox.sch, R2-R_ladder_dac.sch]
2019-11-22 add gerbers (after I received the boards already) from v1.0.0
    [Luciebox-B_Cu.gbl, Luciebox-B_Mask.gbs, Luciebox-B_SilkS.gbo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]
2019-11-22 reload autosave, the v1.0.0 save was not actually saved. oioioi. So, now at v1.0.0 pcb!
    [Luciebox.kicad_pcb]
2019-12-16 pcb ordered, errors found
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2020-01-04 working on buttons problem. Selector dial should be ok now. (not yet tested)
    [selectorDialValues.ods]
2020-01-06 busy debugging R2R ladder for buttons
    [selectorDialValues.ods]
2020-01-06 all buttons seem to work again. solved bugs.
    [ButtonsDacR2r.cpp, PretbakSettings.h]
2020-01-07 buttons margin depending on number of buttons in use per adc. ROOT CAUSE PROBLEM: the buttons adc value changes. there must be a hardware problem, as sometimes the values are nicely (like set in pret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
    [ButtonsDacR2r.cpp, PretbakSettings.h]
2020-01-18 buttons and selector switch debugging. Starting to change pcb schematic for v2.0 board
    [Luciebox.kicad_pcb, Luciebox.sch, R2-R_ladder_dac.sch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]
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2020-01-22 bugfix reactiongame score and animationstep was mangled
    [Apps.cpp]
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2020-01-23 clean up a little bit. ram one byte less, enough to avoid ram run out error for minimultitimer to show decimal point
    [Apps.cpp, PretbakSettings.h]
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2020-01-23 rework reaction game. state machine. , less memory, one timer less
    [Apps.cpp, Apps.h]
2020-01-25 rework metronome mode (accomodate for extra button, so we have three tickers!
    [Apps.cpp, Apps.h, PretbakSettings.h]
2020-02-03 not working. ram problems? But even when stuff disabled, strange behaviour.
    [Apps.cpp, Apps.h]
2020-02-03 the problem is that there MUST be a stray Serial.println statement in the code somewhere with ENABLE_SERIAL set. I believe I fuck up somewhere with some bit shifts or pointers and the ram gets affect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
    [Apps.cpp]
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2020-02-07 working point. no ram issue change
    [Apps.cpp, Buzzer.h]
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2020-02-11 reworking of sequencer. Adding more bells and whistles. visualize notes. Cool transpose function. Free up the toggle switch for future save and load tracks
    [Apps.cpp, Apps.h]
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2020-02-16 dicerollapp bugfix during drawcard from deck animation no cards should be drawn
    [Apps.cpp, Apps.h]
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2020-02-20 reworking and expanding Simon
    [Apps.cpp, Apps.h]
2020-02-20 simon multiplayer. error at nextPlayer. --> check with Serial.println todo
    [Apps.cpp, Apps.h]
2020-02-23 various changes and little bugfixes
    [Apps.cpp, Apps.h]
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2020-02-23 bugfix Init setting was not triggered for changing apps with Big latching button
    [Apps.cpp, Apps.h]
2020-02-23 rework app selector function. I just learned that switch statements take a lot of memory. 500 bytes extra for adding some more options? yoink! I will try with function pointers. Or i'll have to rewin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
    [Apps.cpp, Apps.h]
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2020-02-27 reworking draw app, make things A LOT less complicated
    [Apps.cpp, Apps.h, PretbakSettings.h]
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2020-03-04 draw bugfix save display to eeprom
    [Apps.cpp, Apps.h]
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2020-03-06 changes in pcb v2.0
    [Luciebox.kicad_pcb, Luciebox.sch, R2-R_ladder_dac.sch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]
2020-03-07 progressive change towards v2.0
    [Luciebox.kicad_pcb, Luciebox.sch, R2-R_ladder_dac.sch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]
2020-03-07 add holes for R-2R ladder, fix bug with tilt switch sheet. Set output led's. All good here.
    [Luciebox.kicad_pcb, Luciebox.sch, R2-R_ladder_dac.sch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]
2020-03-07 rework display: multitimer, sequencer, reaction game: done
    [Apps.cpp, Apps.h]
2020-03-08 rework song player (work in progress)
    [Apps.cpp, Apps.h, Buzzer.h]
2020-03-11 modify pcb v2.0. nearly finished. Choose box.
    [Luciebox.kicad_pcb, Luciebox.sch, R2-R_ladder_dac.sch]
2020-03-14 buzzer notes display bugfix
    [Apps.cpp]
2020-03-14 bad bad pointer bugfix
    [Apps.cpp]
2020-03-14 memory optimizing -> buzzer, potentio, timer
    [Apps.cpp, Apps.h]
2020-03-15 rework metronome. Not the memory gain I thought I was going to see...
    [Apps.cpp, Apps.h]
2020-03-16 hacktime app. display mode, problem: does not show value hex, or dec. Also binary is odd. to be investigated
    [Apps.cpp, Apps.h]
2020-03-20 bugfix composer step. but, why 28 bytes more memory for using int16 instead of int8
    [Apps.cpp]
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2020-03-28 pcb change extra header so holes line up for lights to buttons.
    [Luciebox.kicad_pcb, Luciebox.sch]
2020-03-29 pcb finish v2.0
    [Luciebox-B_Cu.gbl, Luciebox-B_Mask.gbs, Luciebox-B_SilkS.gbo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]
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2020-04-11 Bugfix in sound note scales
    [Apps.h]
2020-04-11 Fix scale manual step bug.
    [Apps.cpp, Buzzer.h]
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2020-09-06 fix bug: wrong find and replace instances of big_latching were changed by extra_latching
    [Apps.cpp, Apps.h, PretbakSettings.h]
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2020-09-06 attempt to optimize. failed.
    [Apps.cpp, Apps.h]
2020-09-09 fix bug in hex hero.
    [Apps.cpp, Apps.h, PretbakSettings.h]
2020-09-12 reaction game eeprom update for high scores . reset is needed as eeprom layout changed.
    [Apps.cpp, PretbakSettings.h]
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2020-10-15 implement encoder_dial pin change: keep buzzer where it was. pin 2 and 3 used for interrupt in encoder. segA moved from 2 to A3, segG moved from 3 to 1
    [Apps.cpp, Apps.h, Buzzer.h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]
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2020-10-21 all apps ON. juuuussst 100% memory. G segment not working. hardware?
    [Apps.cpp, Apps.h, PretbakSettings.h]
2020-10-22 bugfix metronome speed change only when ticking
    [Apps.cpp]
2020-10-26 hack mode reworked after dial update
    [Apps.cpp, Apps.h]
2020-10-29 tilt movement detector working. All apps fit in memory. PCB bugfix (traces were shorted at selector knob
    [Luciebox.kicad_pcb]
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2020-11-02 movie player rework. Saves like 0.3% flash after quite some work. Totally worth it!
    [Apps.cpp, Apps.h]
2020-11-05 rework buzzer songs --> almost done but strange error with songindex
    [Apps.cpp, Apps.h, Buzzer.h]
2020-11-06 complete buzzer song load rework --> complete alphabet song makes it return
    [Apps.cpp, Apps.h]
2020-11-07 bugfix drawmode cursor overflow
    [Apps.cpp, Apps.h]
2020-11-08 rework init. Also init on app change latching button.
    [Apps.cpp, Apps.h, PretbakSettings.h]
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2020-11-08 bugfix init app playing variable cannot be shared
    [Apps.cpp, Apps.h]
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2020-12-04 unknown changes code
    [Luciebox.kicad_pcb, Luciebox.sch, R2-R_ladder_dac_tilt_switches.sch]
2020-12-04 pcb new version v3 . Chaotic history
    [Luciebox_BOM.csv, Luciebox_BOM_byValue.csv, Luciebox_v2.kicad_pcb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]
2020-12-04 external I/O button board design halfway
    [button_pcb_4x_laz16-11_.sch]
2020-12-07 pcb work on button pcb
    [Luciebox_v3.kicad_pcb, Luciebox_v3.sch, button_pcb_4x_laz16-11_.kicad_pcb]
2020-12-09 button board pcb v1.0 + gerbers
    [Luciebox-B_Cu.gbl, Luciebox-B_Mask.gbs, Luciebox-B_SilkS.gbo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]
2020-12-10 before finishing v3
    [Luciebox_v3.kicad_pcb, Luciebox_v3.sch, button_pcb_4x_laz16-11_.kicad_pcb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]
2020-12-11 pcb v3 comming along
    [Luciebox_v3.kicad_pcb, Luciebox_v3.sch]
2020-12-12 published and ordered v3 luciebox v1 buttonboard. Gerbers included
    [Luciebox_v3-B_Cu.gbl, Luciebox_v3-B_Mask.gbs, Luciebox_v3-B_SilkS.gbo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]
2020-12-13 correct and send out button board v1.1
    [button_pcb_4x_laz16-11_-B_Cu.gbl, button_pcb_4x_laz16-11_-B_Mask.gbs, button_pcb_4x_laz16-11_-B_SilkS.gbo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]
2020-12-14 all button lights working
    [button_pcb_4x_laz16-11_.kicad_pcb]
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2020-12-16 draw app lights. memory 2 bytes too small.
    [Apps.cpp, Apps.h]
2020-12-16 bugfix latching button extra was not indicated as indexed.
    [Apps.cpp]
2020-12-23 bug fix time index
    [Apps.cpp, Apps.h, PretbakSettings.h]
2020-12-24 mute mode in sound, simon says lights bug fix. Mem full
    [Apps.cpp, Apps.h]
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2020-12-27 multitimer app fix fischer timer
    [Apps.cpp, Apps.h]
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2021-03-11 SET to debug mode, but multitimer crash issue solved
    [Apps.cpp, Apps.h, PretbakSettings.h]
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2021-03-12 reaction game sound mode. wrong sounds played bug fix
    [Apps.cpp, Apps.h, PretbakSettings.h]
2021-03-13 reaction game countdown mode fixed
    [Apps.cpp, Apps.h, PretbakSettings.h]
2021-03-14 bug fix hex hero played whack a bird sounds. Add random start song for sequencer
    [Apps.cpp, Apps.h]
2021-03-15 sequencer songs in mediaplayer were not timed right. The fix is to have them all at a same lenght
    [Apps.cpp, Buzzer.h]
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2021-03-16 multitimer settings to eeprom + bugfix movieplayer
    [Apps.cpp, Apps.h, PretbakSettings.h]
2021-03-16 multitimer bugfix: it added fischertimer to finished timer
    [Apps.cpp, Apps.h]
2021-03-16 improve settings menu, eeprom behaviour (partial reset), set power cycler counter
    [Apps.cpp, Apps.h, PretbakSettings.h]
2021-03-16 Do total eeprom reset at first ever power on
    [Apps.cpp, Apps.h, PretbakSettings.h]
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2021-03-18 change draw mode single digit toggle button + bugfix wrong randombeeplight pomodoro timer
    [Apps.cpp, Apps.h]
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2021-03-19 draw insert and delete pictures bugfix
    [Apps.cpp, Apps.h, PretbakSettings.h]
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2021-04-10 hack mode optimized and representation bugfix
    [Apps.cpp, Apps.h]
2021-04-13 add whack a bird init lights. Still a bit too big too compile. make -500 default for timers.
    [Apps.cpp, Apps.h]
2021-04-13 fix buzzer note display bug
    [Apps.cpp, Buzzer.h]
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2021-04-18 pomodoro changing to hourglass. Still too big. Working though.
    [Apps.cpp, Apps.h]
2021-04-20 bugfix settings mode had latching 1 switch not as an exception
    [Apps.cpp]
2021-04-21 bugfix eeprom range games --> pointer casting was wrong
    [Apps.cpp, Apps.h]
2021-04-21 repo clean up
    [selectorDialValues.ods]
2021-04-21 F303. settings mode change easier debug. small bugfixes
    [Apps.cpp, Apps.h, PretbakSettings.h]
2021-09-02 quizmaster bugfix and optimization
    [Apps.cpp, PretbakSettings.h]
2021-09-15 rework dreammode to baby activity center
    [Apps.cpp, Apps.h, PretbakSettings.h]
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2021-09-30 add optimization to buzzer, set notes count as define
    [Apps.cpp, Apps.h, Buzzer.h]
2021-10-01 convert Buzzer to new note system. concept working.
    [Apps.cpp, Apps.h, Buzzer.h]
2021-10-01 rework buzzer buffer treatement
    [Buzzer.h]
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2021-10-02 add debug cycle counter. Add buzzer optimization and seamless play of consecutive same notes
    [Apps.cpp, Apps.h, Buzzer.h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]
2021-11-24 Restore pcb components
    [Luciebox_v3.sch, R2-R_ladder_dac_tilt_switches.sch]
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2022-01-13 set inactivity time to 10mins. Bugfix: autopower off during stopwatch pause
    [Apps.cpp, Apps.h]
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2022-01-14 rework app selector loop into state machine for auto power off and no selector knob
    [Apps.cpp, Apps.h, Luciebox.ino]
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2022-01-30 replace all apps from latching to software latching buttons. Not all tested.
    [Apps.cpp]
2022-01-30 fix drawing game app and app selector button bug
    [Apps.cpp]
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2022-01-31 reset app at app select menu
    [Apps.cpp, Apps.h]
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2022-02-22 Rework Quiz app for new buttons and better playability
    [Apps.cpp, Apps.h]
2022-05-16 Pcb v4 setup with kicad6. Button board --> before erasing smd components from the board
    [Luciebox_buttons.kicad_sch, Luciebox_v4.kicad_pcb, Luciebox_v4.kicad_sch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]
2022-05-29 V4 main pcb ready for layouting
    [Luciebox_buttons.kicad_sch, Luciebox_v4.kicad_pcb, Luciebox_v4.kicad_sch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]
2022-06-01 layout main board start
    [Luciebox_v4.kicad_pcb, Luciebox_v4.kicad_sch, button_pcb.kicad_pcb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]
2022-06-28 Pcb v4 evolution
    [Luciebox_v4.kicad_pcb, Luciebox_v4.kicad_sch]
2022-11-08 Progress on pcb's
    [Luciebox_v4.kicad_pcb]
2022-11-08 Main board pcb prevent interference with buttons from button board
    [Luciebox_v4.kicad_pcb, button_pcb.kicad_pcb]
2022-11-09 Moved boards connector. Main board ready for traces.
    [Luciebox_v4.kicad_pcb, Luciebox_v4.kicad_sch, button_pcb.kicad_pcb]
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2022-11-09 Add artwork. Copy screenshot to gimp to delete parts you don't want with silkscreen from original image. Than, generate new artwork. from burst, set to 150mm export
    [Luciebox_v4.kicad_pcb, button_pcb.kicad_pcb]
2022-11-10 Add extra text and adjust artwork
    [Luciebox_v4.kicad_pcb, button_pcb.kicad_pcb]
2022-11-14 PCB v4 sent for production
    [Luciebox_v4-B_Cu.gbr, Luciebox_v4-B_Mask.gbr, Luciebox_v4-B_Paste.gbr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]
2022-12-04 Multitimer, disable stop function. App needs to be reset to stop. Too dangerous (player presses button by accident during game means, all is lost)
    [Apps.cpp, Apps.h]
2022-12-09 Main pcb v4 values
    [Luciebox_v4.kicad_pcb, Luciebox_v4.kicad_sch]
2023-02-03 Start pcb v5 with feedback from v4
    [Luciebox_buttons.kicad_sch, Luciebox_v4.kicad_pcb, Luciebox_v4.kicad_sch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]
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2023-03-07 Button lights mapping corrected for v5 pcb
    [PretbakSettings.h]
2023-03-07 Fix splash screen button light snake
    [Apps.h, PretbakSettings.h]
2023-03-08 Bugfix store last app at shutdown
    [Apps.cpp, Apps.h, PretbakSettings.h]
2023-03-09 Rework Multitimer. Make room for survive timeout function. Not yet implemented
    [Apps.cpp, Apps.h, PretbakSettings.h]
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2023-03-10 Bugfix: stopwatch laptime enable
    [Apps.cpp]
2023-03-10 Add noise to stopwatch
    [Apps.cpp]
2023-07-28 No clue what I'm doing. experimenting with buzzer?
    [Apps.cpp, Apps.h]
2024-01-02 Bug fix whack-a-bird with random notes
    [Apps.cpp]
2024-01-04 Disable school app(to free up memory). Bugfixes in multitimer. lights in stopwatch
    [Apps.cpp, Apps.h]
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2024-01-07 Bugfix and beautify randomworld
    [Apps.cpp, Apps.h]
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2024-01-08 Memory optimization multitimer with lights. Not working yet
    [Apps.cpp]
2024-01-08 Bugfix lights errors multitimers
    [Apps.cpp]
2024-01-14 Stopwatch, prevent autopower off
    [Apps.cpp]
2024-01-15 Simon says, display improvement. Game improvement (in custom mode, game ends if one player is still alive). Not working, no memory
    [Apps.cpp, Apps.h]
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2024-01-15 Bug fix high score for hex with inversion repair
    [Apps.cpp]
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2024-01-18 Simon app crashes if starts at startup and press start
    [Apps.cpp, Apps.h]
2024-01-18 Bugfig Simon single player random choser infinit while looop
    [Apps.cpp]
2024-01-19 Simon app repair, rework, improve custom game
    [Apps.cpp, Apps.h]
2024-01-19 Simon rework. all good. But, for custom build up, should be lighting up long after player choses, not new level...
    [Apps.cpp, Apps.h]
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2024-01-25 Simon says rework. Bug with buzzer getNotesBufferEmpty does not imply sounds are finished. To check other programs. Mem full. not compiling
    [Apps.cpp, Apps.h, Buzzer.h]
2024-01-26 Generalize Buzzer done playing function, too big size
    [Apps.cpp, Buzzer.h]
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2024-01-30 Rework big button mask. More readable. Untested
    [Apps.cpp, Apps.h]
2024-02-02 Tally rework. In middle of it
    [Apps.cpp, Apps.h, PretbakSettings.h]
2024-02-02 Tally keeping app. Total rework. Base is ok. Negative numbers not yet working
    [Apps.cpp, Apps.h]
2024-02-03 Store tally keeper values in eeprom. Works. Can't compile with all apps enabled . too big
    [Apps.cpp, Apps.h, Luciebox.ino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]
2024-02-03 rework buzzer to get sound well in tally. Not working yet
    [Apps.cpp, Apps.h]
2024-02-03 Buzzer rest rework, not yet compiling
    [Apps.cpp, Apps.h]
2024-03-27 Bugfix shootout, minimize probability for wrong button detection.
    [button_pcb.kicad_sch]
